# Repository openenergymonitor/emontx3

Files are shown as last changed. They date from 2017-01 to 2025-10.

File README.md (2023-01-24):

# emonTx V3.4.x



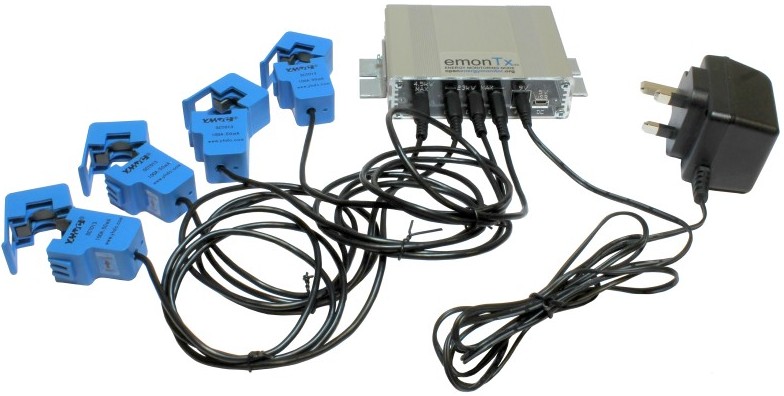
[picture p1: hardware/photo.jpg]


## Documentation

- [Overview](https://docs.openenergymonitor.org/emontx3/overview.html)
- [Install Guide](https://docs.openenergymonitor.org/emontx3/install.html)
- [Adding to an existing install](https://docs.openenergymonitor.org/emontx3/add.html)
- [3 phase](https://docs.openenergymonitor.org/emontx3/3phase.html)
- [Add ESP8266](https://docs.openenergymonitor.org/emontx3/esp8266.html)
- [Direct Serial](https://docs.openenergymonitor.org/emontx3/direct.html)
- [Configuration](https://docs.openenergymonitor.org/emontx3/configuration.html)
- [Firmware](https://docs.openenergymonitor.org/emontx3/firmware.html)
- [Technical](https://docs.openenergymonitor.org/emontx3/technical.html)

This documentation can also be viewed on github directly [here](docs).

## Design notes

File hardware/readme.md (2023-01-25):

# emonTx V3.4

The emonTx V3.4 is the latest generation of the open-source hardware Arduino compatiable emonTx low power wireless energy monitoring node. The unit has been totally re-designed using surface mount (SMT) electronics to enable automated pre-assembled manufacture here in the UK.

## Hardware change log

### V3.4.5 

*Not yet released as of April 2021*

PCB changes
- Remove MLF ATmega footprint to avoid solder bridges during reflow
- Fix rear silkscreen version number
- Improve via spacing 

BOM changes
- Update R13 & R14 from 1% to 0.5% tolerance
- Switch to LDK320ADU33R LDO for higher 18V input voltage
- Remove battery holder from BOM 
- Revert to 4x 3.5mm black CT sockets due to procurement issues for differnet colour sockets
- Moved TSV diodes from ESD5Z3.3T1G to UCLAMP3301H to procurement issues 

### V3.4.4 

Minor PCB changes:

- fix overlayed double via
- Add protection ring for top-right fiducial

### V3.4.3

**Shipping March/April 2018 onwards**

- Identifiable with blue CT4 jackplug socket (mostly)
- Add extra UART header with Rx/Tx swap-over for easy ESP connection
- Increase  reservoir capacitor of AC-DC circuit C18 16uF to 100uF to allow for greater peak power consumption of RFM69CW (compared to RFM12B)
- Change Burden resistors R7, R8, R9 (22R) from 1% to 0.5% tolerance  to increase accuracy. Wanted to change to 0.1% but unable to source
- Changed Burden resistor R18 (120R) from 1 % to 0.1%
- Change all 470K resistors from 1% to 0.1% (R1, R2, R4, R6, R11, R12, R15, R17, R21, R23, R27, R30)
- Changed CT4 jack plug socket to blue colour to indicate low power high accuracy channel

Live BOM: https://octopart.com/bom-tool/xiwE7CiN

#### V3.4.2

**Aug 2016**

- Same BOM as V3.4.1
- Increase mini USB location pin holes from 0.8mm to 0.9mm

#### 3.4.1 Mar 2015

- lots of via GND links around GND plane - make sure ant has best GND plane possible
- make sure antenna has got GND plane under ant PCB trace
- pull top gnd plane in around RFM69CW module and rear GND plan to cover whole undersided
- Get rid of unused L1
- Move D2 location to not be under battery holder
- Correct terminal block silkscreen
- Disconnect RJ45 pin 1 and 3 from GND, stop power rail short if ethernet cable is connected by mistake

#### V3.4

- More FTDI connection bit to the left
- Increase pads for DIP switch
- Add TVS diodes, CT input protection

### V3.3

- ATmega328 on-board
- Edge SMA Antenna
- Non plate through mounting pads to eliminate interference through enclosure
- RJ45 DS18B20 temperature sensor
- 3 x AA Battery monitor on ADC7
- DIP Switch on Dig8 and Dig9 for Node ID selection
- RFM69CW compatible with SEL line pull-up resistor
- Pulse counting / terminal block IRQ changed from D2 IRQ0 to D3 IRQ1 since RFM12B now uses IRQ0
- Changed MCP1700 3.3V regulator to MCP1702 3.3V regulator to allow for powering from higher voltages (12V max) over RJ45

***

## Links

- [Purchase](http://shop.openenergymonitor.com/emontx-v3/)

- [User Guide](https://guide.openenergymonitor.org/setup/emontx)

***



### Schematic

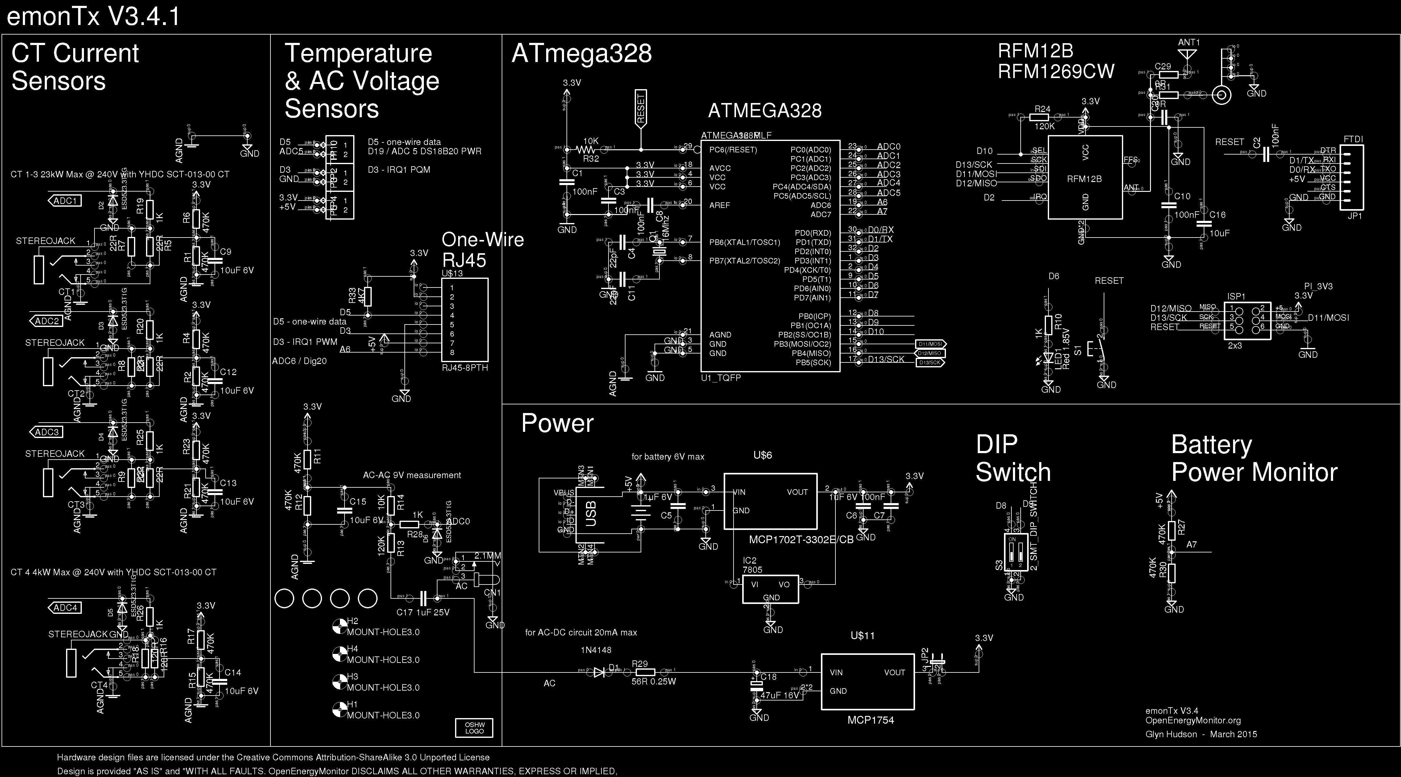
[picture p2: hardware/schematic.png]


### Board

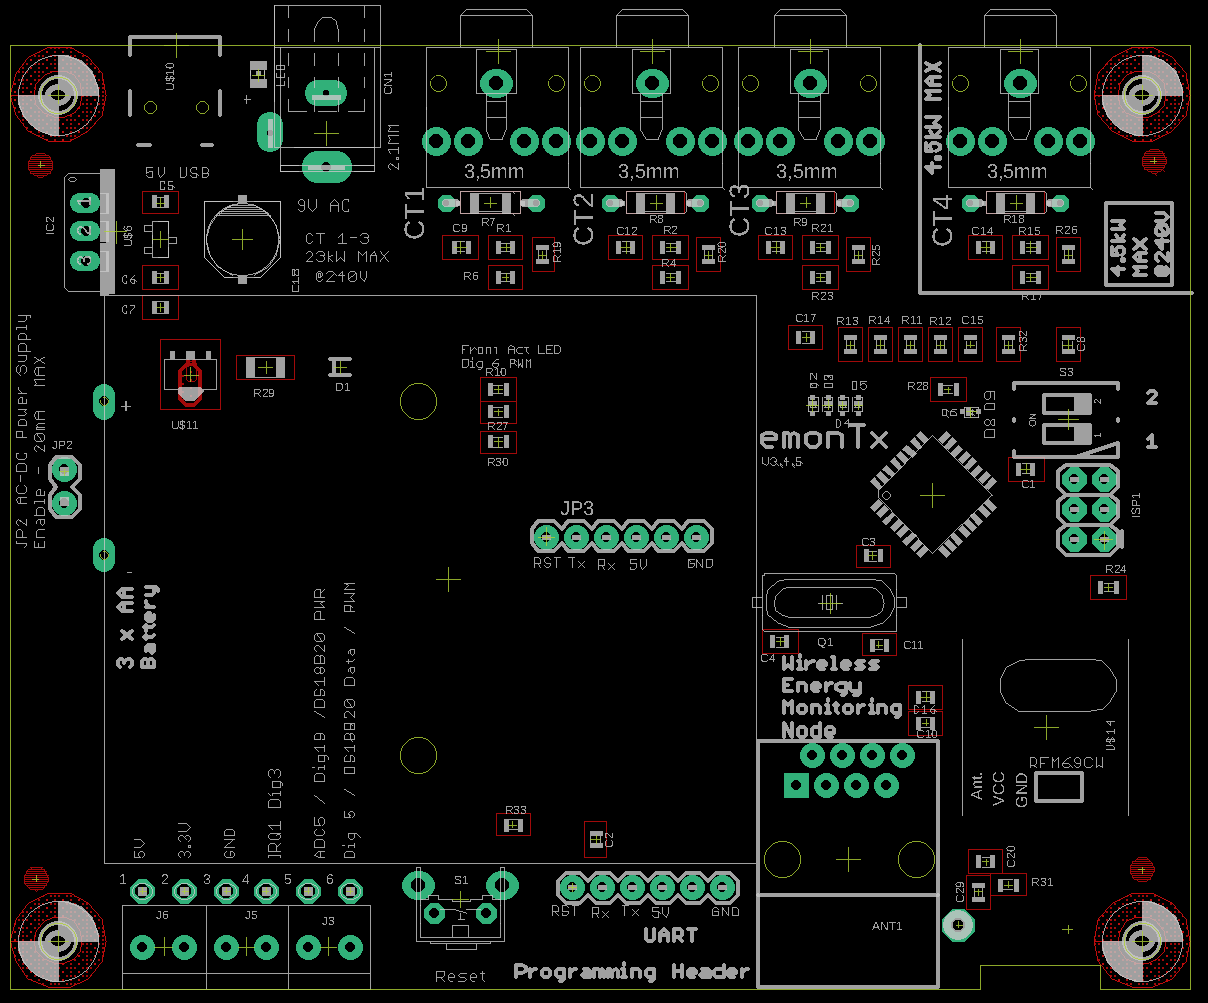
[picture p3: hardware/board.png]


## Portmap

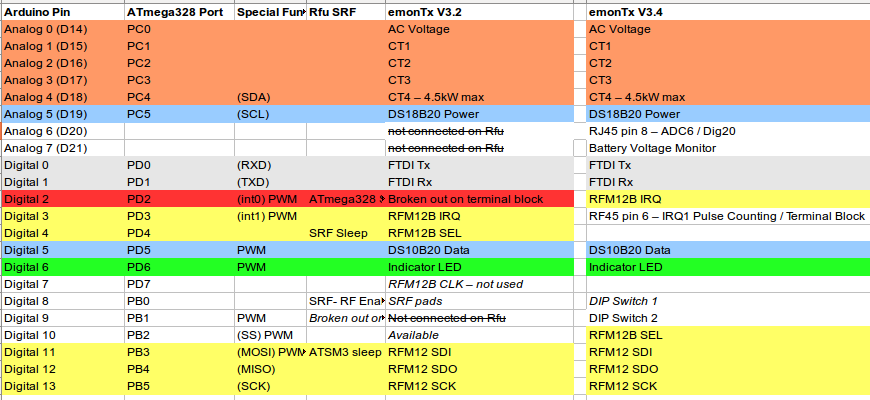
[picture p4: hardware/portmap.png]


### Open Hardware

Hardware designs (schematics and CAD) files are licensed under the [Creative Commons Attribution-ShareAlike 3.0 Unported License](http://creativecommons.org/licenses/by-sa/3.0/) and follow the terms of the [OSHW (Open-source hardware) Statement of Principles 1.0.](http://freedomdefined.org/OSHW)

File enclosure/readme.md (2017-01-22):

Lincoln Binns E-Case B

https://www.lincolnbinns.com/en/aluminium-electronic-enclosure-e-case-b-data/

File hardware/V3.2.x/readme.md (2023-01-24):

# emonTx 3.2.x

The emonTx v3.2 used the RFu328 module to provide both the ATmega328 and the RFM12B radio module. This was available pre-installed or the emonTx base board. 

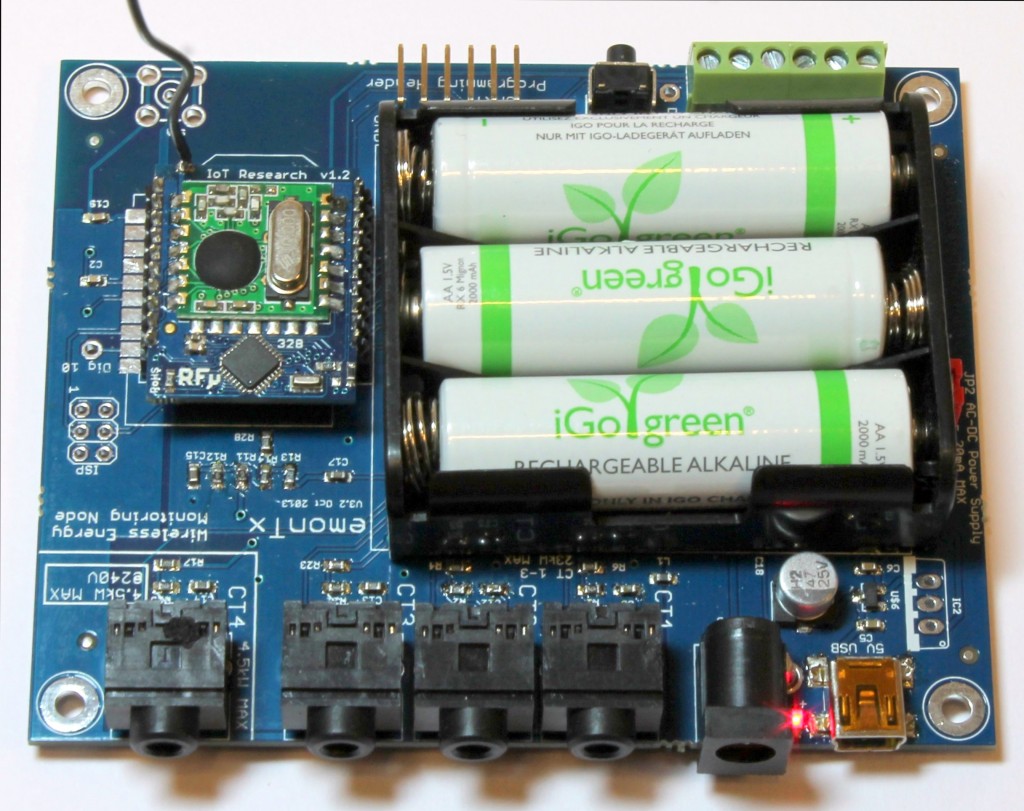
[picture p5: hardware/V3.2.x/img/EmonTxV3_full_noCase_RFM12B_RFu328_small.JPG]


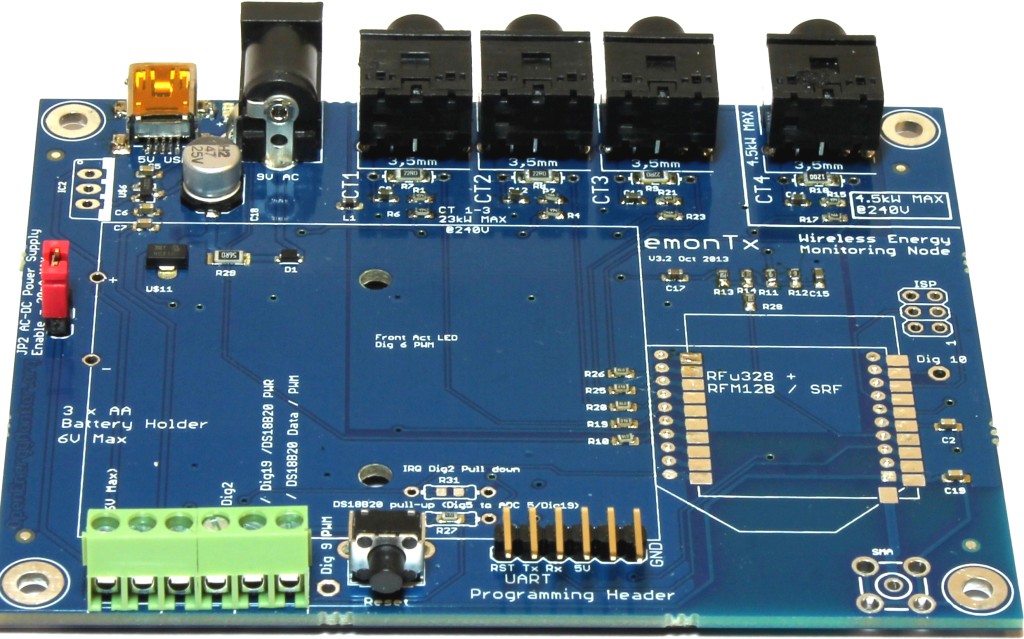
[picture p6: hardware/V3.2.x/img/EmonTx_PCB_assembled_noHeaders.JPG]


## Port Map

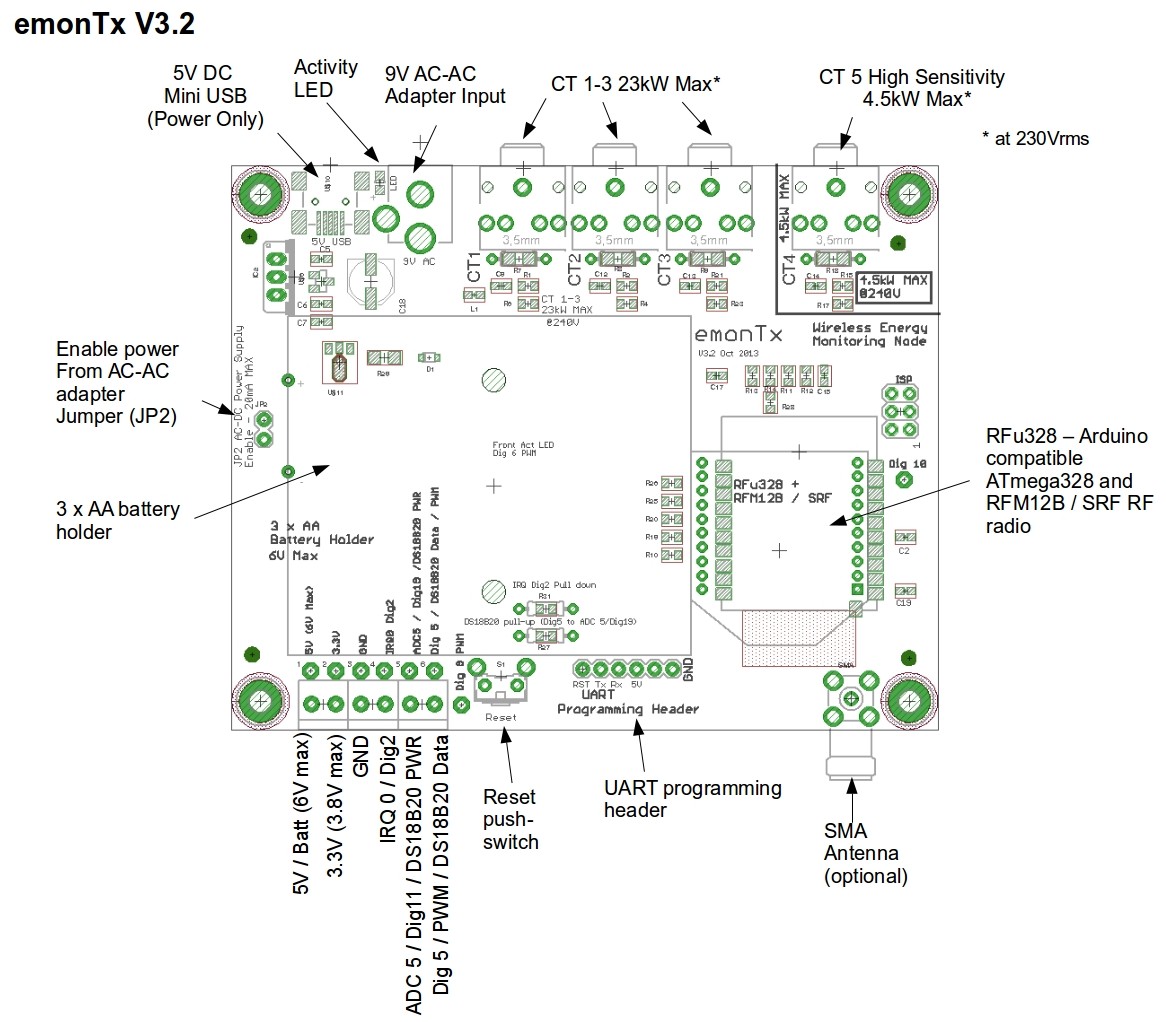
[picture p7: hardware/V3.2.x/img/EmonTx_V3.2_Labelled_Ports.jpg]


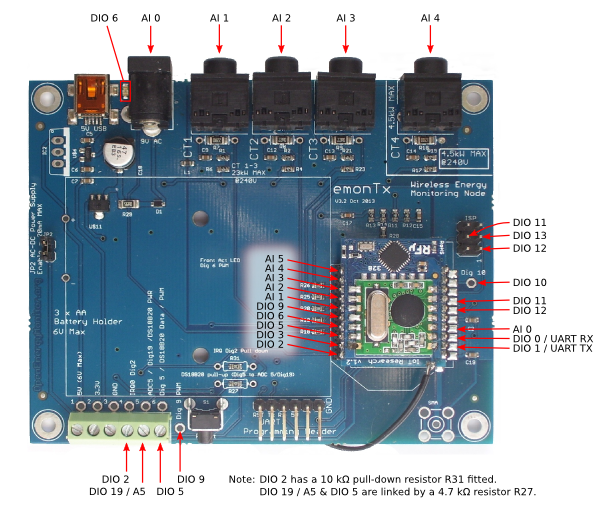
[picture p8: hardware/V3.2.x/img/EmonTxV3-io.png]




*Note: pulse counting on IRQ0, Dig2 rather than IRQ1 Dig3 on the emonTx3.4 

## Firmware

See: [https://github.com/openenergymonitor/emonTxFirmware/tree/master/emonTxV3/RFM/emonTxV3.2 ](https://github.com/openenergymonitor/emonTxFirmware/tree/master/emonTxV3/RFM/emonTxV3.2 )

## RF Connectivity

### RFM12B

To use the RFM12B on the RFu328, a modified version of the JeeLib RF12 library has been created. This is called the [RFu_JeeLib](https://github.com/openenergymonitor/RFu_jeelib) see the GitHub readme for details regarding the modifications. 

The emonTx V3.2 was initially shipped with a wire whip antenna. An SMA antenna could alternatively be added by soldering in the connector on the board. A small wire link was required between the RFu328 and the base board if an RFu328 with headers was used. See [EmonTx_V3_SMA.jpg](img/EmonTx_V3_SMA.jpg) & [EmonTx_V3_SMA_RFu_headers.jpg](img/EmonTx_V3_SMA_RFu_headers.jpg).

Power consumption:

- MCU sleep + RFM12B sleep: 0.034 mA
- MCU running: 7.3mA 
- MCU + LED: 9-10mA
- RFM12B TX ~3ms: 23-28mA

### RF testing

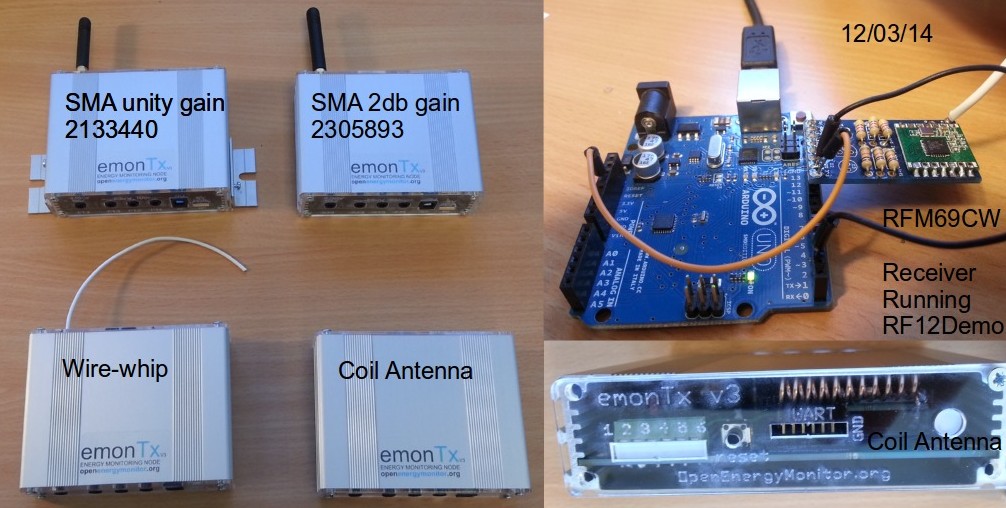
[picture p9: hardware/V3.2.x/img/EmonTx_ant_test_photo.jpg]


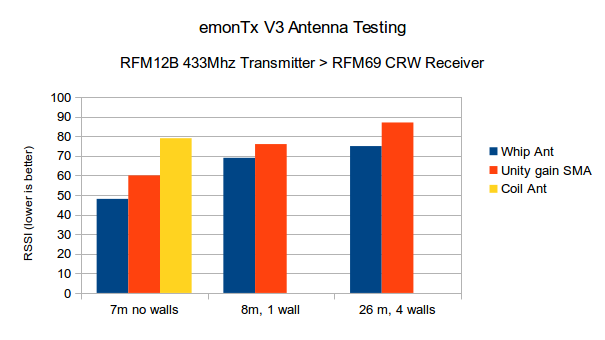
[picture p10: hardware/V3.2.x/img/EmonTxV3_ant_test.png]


All antennas and RFM12B modules were 433MHz running standard emonTx discrete sampling firmware, transmitting once very 10s.

An RFM69CW receiver provided RSSI readings to enable antenna comparison. The RSSI readings were all lower than normal since the RFM69CW used is an 868MHz module, with an 868MHz antenna, forced via software, to a 433MHz receive frequency.

The emonTxs with the SMA antenna had the RFu328 soldered directly (SMT) to the PCB, the coil and whip antenna had the RFu328 mounted using headers 

## BOM

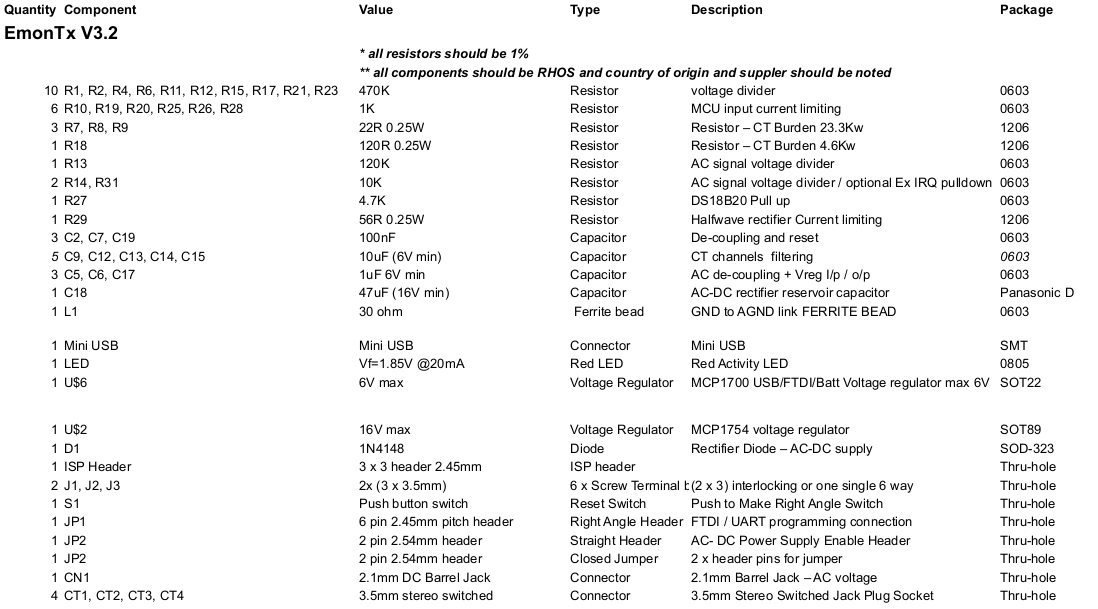
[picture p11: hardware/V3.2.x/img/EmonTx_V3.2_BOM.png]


## Dimensions

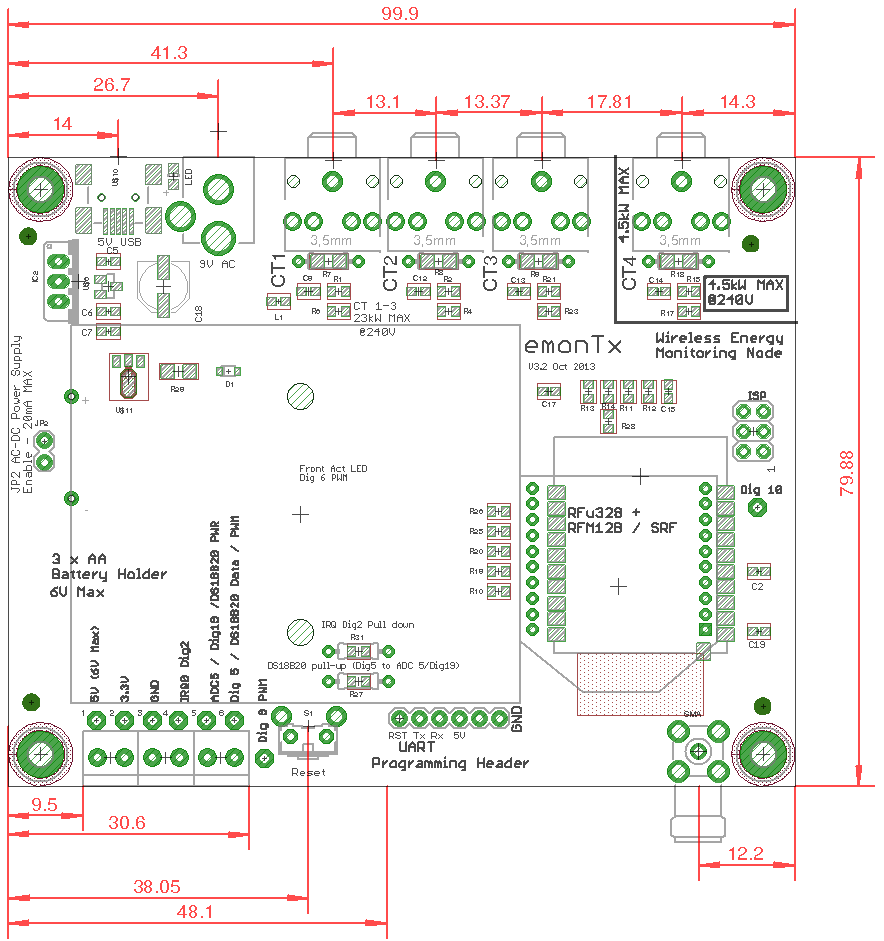
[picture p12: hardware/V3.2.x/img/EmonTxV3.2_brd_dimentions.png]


Enclosure: extruded aluminium case with acrylic fascia.

**DIN Rail Mount:** Thanks to [@Aquefot](http://twitter.ccom/Aquefot) for contributing a [DIN mount rail fitting CAD design](https://twitter.com/aquefot/status/413708371809026048/photo/1) ready to be 3D printed for the emonTx: [Thingiverse Download](http://www.thingiverse.com/thing:208177) 

## Licence

Creative Commons Attribution-ShareAlike 3.0 Unported License

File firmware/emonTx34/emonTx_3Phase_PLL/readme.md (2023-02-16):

# emonTx_3Phase_PLL

This firmware is a development of the 3-phase ‘discrete sample’ sketch and MartinR’s PLL
energy diverter.

It is intended for use on a **3-phase, 4-wire system**. It utilises advanced features of the Atmel328P microprocessor to provide continuous monitoring of voltage of one phase and the currents in all three phases, thereby allowing a good estimate of real power to be calculated. The physical quantities are measured continuously, the average values are calculated and transmitted at user-defined intervals.

Pulse counting and temperature monitoring using a single DS18B20 sensor is supported.

## Key Feautures

- Continuous monitoring of one voltage channel and up 4 current channels.
- Gives an accurate measure of rapidly varying loads.
- 1800 sample sets per second – using 4 channels of an emonTx V3.4 @ 50 Hz
- Calculates rms voltage, rms current, real & apparent power & power factor.
- Pulse input for supply meter monitoring.
- Integrated temperature measurement (one DS18B20 sensor).
- User-defined reporting interval.
- Suitable for operation on a three-phase, 4-wire supply at 50 or 60 Hz.
- Can be calibrated for any voltage and current (default calibration is for emonTx with 100 A CTs & UK a.c. adapter).
- **New:** Radio format support with #define selection for: JeeLib Classic, JeeLib Native & LowPowerLabs

## Limitations

Because the voltage of only one phase can be measured, the sketch must assume that the voltages of the other two phases are the same. This will, in most cases, not be true, therefore the powers calculated and recorded will be inaccurate. However, this error should normally be limited to a few percent. Voltage imbalance might be the result of unbalanced loads within your installation, or it might result from the actions of other consumers on the same supply.

If you find that one or other phase voltage is consistently wrong, you might want to consider a small adjustment to the current calibration of the affected phase. Because of the additional power required for continuous operation, a 5 V USB power supply is likely to be required, even if only the on-board RFM69CW radio is used. The 5 V power will always be required when the ESP8266 WiFi module is added.

The sketch is not compatible with the RFM12B radio module, nor the Arduino Due.

## Resources

- [Introduction to three-phase](https://learn.openenergymonitor.org/electricity-monitoring/ac-power-theory/3-phase-power)
- [Full 3-phase Firmware User Guide](emonTx_3Phase_PLL_User_Doc.pdf)

## Pre-compiled HEX files:

JeeLib Classic radio format:<br>
https://github.com/openenergymonitor/emontx3/releases/download/tx3-16-02-23/emonTx_3Phase_PLL_jeelib_classic_2_1.hex

**New:** LowPowerLabs radio format:<br>
https://github.com/openenergymonitor/emontx3/releases/download/tx3-16-02-23/emonTx_3Phase_PLL_LPL_2_1.hex

## Compile and upload using PlatformIO

PlatformIO works great from the command line. See the excellent [PlatformIO Quick Start Guide](https://docs.platformio.org/en/latest/core/installation/index.html#super-quick-mac-linux) for installation instructions.

    git clone https://github.com/openenergymonitor/emontx3
    cd emontx3/firmware/emonTx34/emonTx_3Phase_PLL
    pio run -t upload

View serial port with PlatformIO CLI

    pio device monitor

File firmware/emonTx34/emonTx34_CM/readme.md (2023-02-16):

# emonTx3_CM

This firmware implements higher accuracy continuous monitoring. Continuous monitoring means that the power readings are representative of the full 10s period that they represent rather than a short snapshot (as originally implemented in the discrete sampling firmware). 

Continuous monitoring firmware was pre-loaded on emonTx3 units sold from the OpenEnergyMonitor shop as standard since 2019, unless battery operation was selected.

## Features

- Continuous Monitoring on all four EmonTxV3 CT channels and ACAC Voltage input channel.
- Real power (Watts) and cumulative energy (Watt-hours) measurement per CT channel.
- RMS Voltage measurement.
- Support for 3x DS18B20 temperature sensors.
- Support for pulse counting.
- Resulting readings transmitted via RFM radio or printed to serial.
- Serial configuration of RFM radio and calibration values.
- **New:** Radio format support with #define selection for: JeeLib Classic, JeeLib Native & **LowPowerLabs**

## Serial configuration

See [https://docs.openenergymonitor.org/emontx3/configuration.html#serial-configuration](https://docs.openenergymonitor.org/emontx3/configuration.html#serial-configuration)

## Pre-compiled HEX files:

JeeLib Classic radio format:<br>
https://github.com/openenergymonitor/emontx3/releases/download/tx3-16-02-23/emonTx34_CM_jeelib_classic_2_4.hex

**New:** LowPowerLabs radio format:<br>
https://github.com/openenergymonitor/emontx3/releases/download/tx3-16-02-23/emonTx34_CM_LPL_2_4.hex

## Compile and upload using PlatformIO

PlatformIO works great from the command line. See the excellent [PlatformIO Quick Start Guide](https://docs.platformio.org/en/latest/core/installation/index.html#super-quick-mac-linux) for installation instructions.

    git clone https://github.com/openenergymonitor/emontx3
    cd emontx3/firmware/emonTx34/emonTx34_CM
    pio run -t upload

View serial port with PlatformIO CLI

    pio device monitor

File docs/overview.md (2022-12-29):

# Overview

The emonTx3 is a low power RF remote sensor node. Data is transmitted to an emonPi or an emonBase via a low power 433 MHz radio.

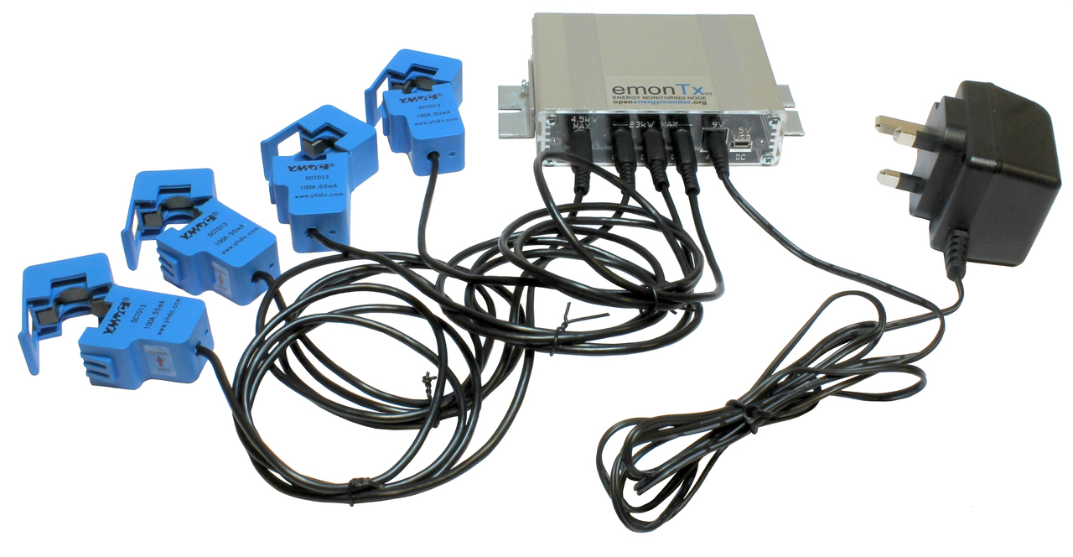
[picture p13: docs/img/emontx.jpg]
emonTx


**Features:**

- 4x CT Sensor inputs for single-phase AC electricity monitoring designed for use with the [100A SCT-013-000 CT sensor](https://shop.openenergymonitor.com/100a-max-clip-on-current-sensor-ct/)
- CT 1-3 are standard 100A / 24KW max CT inputs (@240V)
- CT 4 is a special high sensitivity input for 19A / 4.6KW (@240V)
- 1x AC voltage measurement using plug-in AC-AC adapter for real power calculation alongside current measurement from CT sensors. Designed for use with a [9V AC output voltage adapter](https://shop.openenergymonitor.com/ac-ac-power-supply-adapter-ac-voltage-sensor-uk-plug/)
- Support for multiple wired one-wire DS18B20 temperature sensors via RJ45 socket or terminal block.
- Support for pulse counting either wired or via Optical Pulse Sensor
- Can be powered by a single AC-AC adaptor (DC PSU not required)
- Battery power option via 3 x AA batteries
- RF Range is approximately similar to home WiFi (real world range depends on many factors e.g. thick stone walls)
- Up to 2x emonTx can be connected to a single emonPi or emonBase (up to 30x is possible with manual RF node ID setting*)
- Wall-mount option
- New 2019: The emonTx firmware now supports higher accuracy continuous monitoring as standard, power from an ACAC adapter or USB power is assumed.
- Alternative firmware options include: Discrete Sampling firmware - useful when only battery power is available; and 3-phase firmware.

**WiFi option:** It is possible to use an emonTx with a ESP8266 WiFi adapter to provide WiFi connectivity. This can be useful in applications where the 433 MHz radio range is not sufficient but there is good WiFi signal. The emonTx can post data to a local emonBase/emonPi over WiFi or work in 'standalone mode' to post directly to a remote emoncms server such as emoncms.org. See [Using emonTx with the ESP8266 WiFi module](esp8266.md)

**Battery vs AC adapter:**
An emonTx can be powered by 3 x AA batteries; however, if possible, it is recommended to power the unit with an AC-AC adapter to provide an AC voltage reference for more accurate real power calculation and continuous sampling support.

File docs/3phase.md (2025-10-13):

# emonTx 3phase

An emonTx3 can be used for 3-phase monitoring using the [3-phase firmware](https://github.com/openenergymonitor/emontx3/tree/master/firmware/emonTx34/emonTx_3Phase_PLL).

Designed for use on a 3-phase, 4-wire system. The firmware provides continuous monitoring of voltage of one phase and the currents in all three phases, thereby allowing a good estimate of real power to be calculated. The physical quantities are measured continuously, the average values are calculated and transmitted at user-defined intervals.

Pulse counting and temperature monitoring using a single DS18B20 sensor is supported.

Data is transmitted to the emonPi or emonBase via the low power 433MHz radio as standard, or alternatively using the [ESP8266 WiFi adapter](esp8266.md).

## 1. Installation 

**Before starting installation it's important to identify the phases.**

- Ideally plug the AC voltage adapter into L1 this will allow straightforward connection of CTs as follows CT1=L1, CT2=L2 and CT3=L3. 

- If it's not possible to plug the AC voltage adapter into L1 e.g all the accessible plug sockets are on a different phase then the connection of CTs must be adjusted e.g If AC voltage adapter is plugged into L2 then the CTs must be connected as follows CT1=L2, CT2=L3 and CT3=L1

For a detailed and technical explanation of the 3-phase firmware, see the [emonTx three-phase technical user guide](https://github.com/openenergymonitor/emontx3/blob/master/firmware/emonTx34/emonTx_3Phase_PLL/emonTx_3Phase_PLL_User_Doc.pdf) and the [3-phase emonTx firmware](https://github.com/openenergymonitor/emontx3/tree/master/firmware/emonTx34/emonTx_3Phase_PLL). 

```{note}
The emonTx3 3-phase firmware default nodeid is node 11. If installing multiple units, moving the bottom DIP switch (D8) to the left will change the node ID to 12. This can alternatively be done via serial configuration, see [Adding to an existing install](add.md)
```

## 2. Emoncms Input processing

Setup the input processing as follows, 

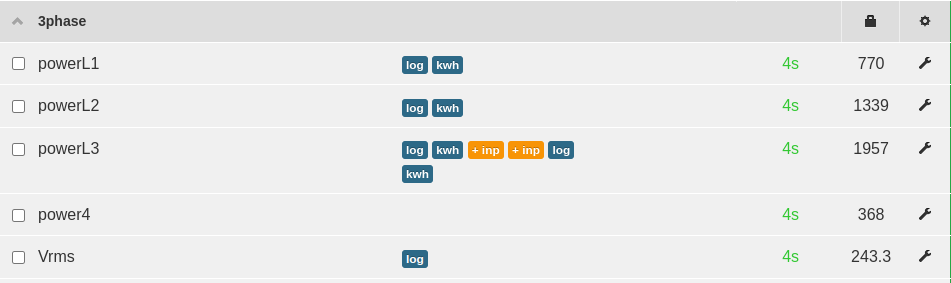
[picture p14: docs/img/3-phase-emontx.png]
emontx three-phase input processing


Use the `+ Input` input process to add the phase power inputs together to create a feed for the total power e.g

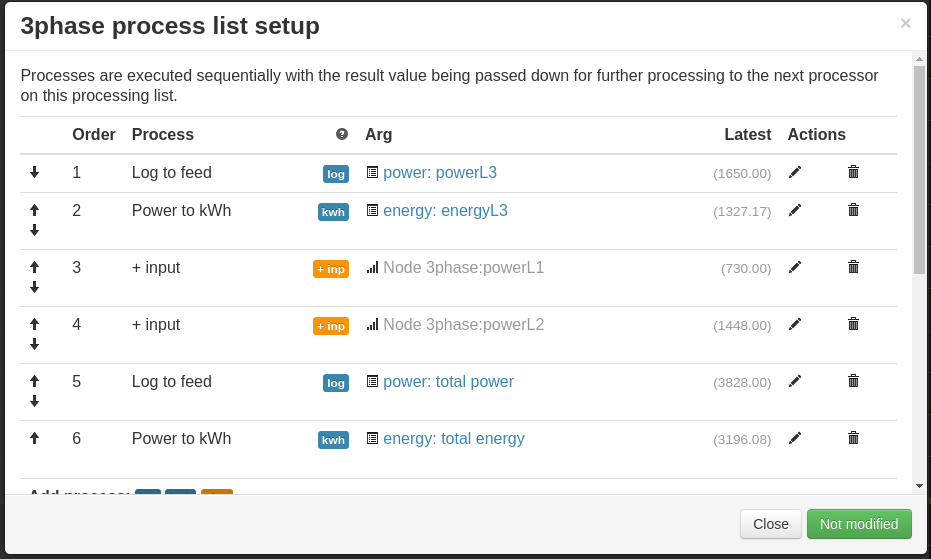
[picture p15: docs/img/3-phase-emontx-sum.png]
emontx three-phase sum


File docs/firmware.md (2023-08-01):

# Firmware

The emonTx3 firmware is based on Arduino. Alternative or customised firmware sketches can be uploaded using Arduino IDE or PlatformIO and a USB to UART cable.

## Available Firmware

### [emonTx34_CM](https://github.com/openenergymonitor/emontx3/tree/master/firmware/emonTx34/emonTx34_CM): continuous sampling firmware

This firmware provides higher accuracy continuous monitoring. Continuous monitoring means that the power readings are representative of the full 10s period that they represent rather than a short snapshot. This firmware was pre-loaded as standard since 2019, unless battery operation was selected.

**New:** Support for three different radio formats is available: JeeLib Classic, JeeLib Native and **LowPowerLabs**.

### [emonTx34_DS_jeelib_classic](https://github.com/openenergymonitor/emontx3/tree/master/firmware/emonTx34/emonTx34_DS_jeelib_classic): discrete sampling firmware

The original emonTx firmware, this performs power measurement in short discrete snapshots ~300ms long per CT channel at 50Hz per 10s period. This makes it possible for the emonTx to go to sleep inbetween readings enabling battery powered operation but is less accurate.

**Indicator LED:** Illuminates solid for a 10 seconds on first power up, then flashes multiple times to indicate an AC-AC waveform has been detected (if powering via AC-AC adapter). Flashes once every 10s to indicate sampling and RF transmission interval.

### [emonTx_3Phase_PLL](https://github.com/openenergymonitor/emontx3/tree/master/firmware/emonTx34/emonTx_3Phase_PLL): 3-phase continuous sampling firmware

This firmware is intended for use on a 3-phase, 4-wire system and implements continuous monitoring as above. Because the voltage of only one phase can be measured, the firmware must assume that the voltages of the other two phases are the same. This will, in most cases, not be true, therefore the powers calculated and recorded will be inaccurate. However, this error should normally be limited to a few percent.

- [Learn: Introduction to three-phase](https://learn.openenergymonitor.org/electricity-monitoring/ac-power-theory/3-phase-power)
- [Full 3-phase Firmware User Guide](https://github.com/openenergymonitor/emontx3/blob/master/firmware/emonTx34/emonTx_3Phase_PLL/emonTx_3Phase_PLL_User_Doc.pdf)

**New:** Support for three different radio formats is available: JeeLib Classic, JeeLib Native and **LowPowerLabs**.

## Updating firmware using an emonPi/emonBase

The easiest way of updating the emonTx3 firmware is to connect it to an emonPi or emonBase with a USB to UART cable and then use the firmware upload tool available at `Setup > Admin > Update > Firmware`.

The example images below show the earlier [Wicked Device / OpenEnergyMonitor Programmer](../electricity-monitoring/programmers/wicked-device.md). The programmer is the small board that plugs in to the emonTx3 on the 6-pin UART header. The [newer programmer](../electricity-monitoring/programmers/ftdi-programmer.md) currently available in the shop needs to be orientated the other way around. **Make sure that GND on the programmer matches up with GND on the emonTx3 board.**

Refresh the update page after connecting the USB cable. You should now see port ttyUSB0 appear in the ‘Select port` list.

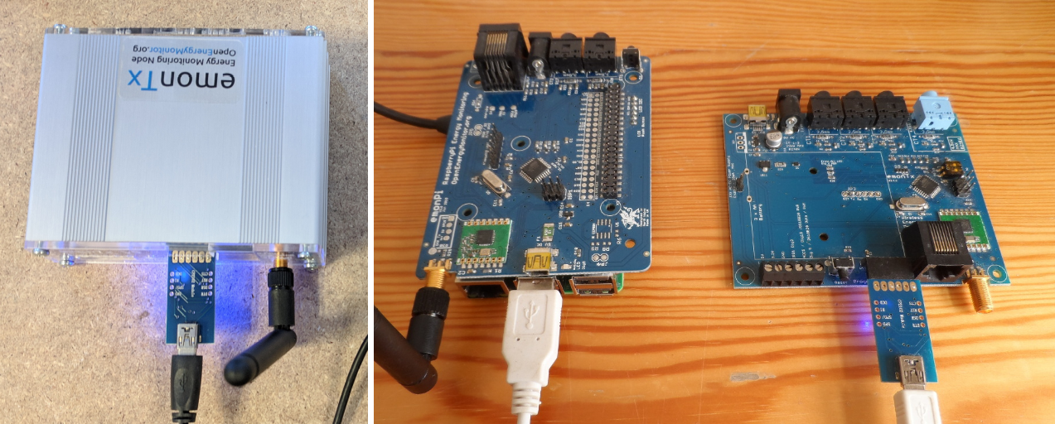
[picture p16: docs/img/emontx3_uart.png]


Select port: `ttyUSB0`, Hardware: `emonTx`, Radio format: `RFM69 JeeLib Classic`, Firmware: As required, see above.



Click `Update Firmware` to upload the firmware.

## How to compile and upload firmware

### PlatformIO Command Line

PlatformIO works great from the command line. See the excellent [PlatformIO Quick Start Guide](https://docs.platformio.org/en/latest/core/installation/index.html#super-quick-mac-linux) for installation instructions.

**Compile and upload emonTx34_CM Continuous Sampling firmware**

    git clone https://github.com/openenergymonitor/emontx3
    cd emontx3/firmware/emonTx34/emonTx34_CM
    pio run -t upload
    
**Compile and upload emonTx34_DS_jeelib_classic Discrete Sampling firmware**

    git clone https://github.com/openenergymonitor/emontx3
    cd emontx3/firmware/emonTx34/emonTx34_DS_jeelib_classic
    pio run -t upload
    
**Compile and upload emonTx_3Phase_PLL firmware**

    git clone https://github.com/openenergymonitor/emontx3
    cd emontx3/firmware/emonTx34/emonTx_3Phase_PLL
    pio run -t upload

**View serial port with PlatformIO CLI**

    pio device monitor

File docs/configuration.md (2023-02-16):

# Configuration

## DIP Switch

The on board DIP switch can be used as a convenient way to change both the node ID and the voltage calibration of the emonTx3.

Multiple emonTx unit's can operate on a single network posting to a single emonBase web-connected base station, each emonTx on the same network group must have an unique node ID. If more than two emonTx's are required on the same network then further nodeID values can be set via RF node ID serial config.

The following image shows the DIP switch configuration looking at the emonTx with the CT sensor inputs at the top of the board. 

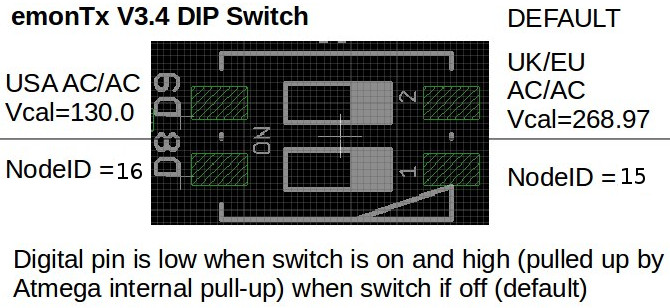
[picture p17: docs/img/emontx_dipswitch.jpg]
```{image} img/emontx_dipswitch.jpg
:width: 400px
:align: right
```

<br>

Move the top switch D9 to the left to select USA ACAC Voltage calibration. 

Move the bottom switch D8 to the left to select RF node ID 16 rather than 15.

<br>
<br>

## Serial Configuration

It's possible to set the emonTx3 radio settings, sensor calibration and other properties over serial using the arduino serial monitor or other similar tool. 

The following details the available commands and their function:

- **l** list the settings
- **r** restore sketch defaults
- **s** save settings to EEPROM
- **v** show firmware version
- **z** zero energy values
- **x** exit, lock and continue
- **?** show this text again
- **w\<x\>** turn RFM Wireless data off: x = 0 or on: x = 1
- **b\<n\>** set r.f. band n = a single numeral: 4 = 433MHz, 8 = 868MHz, 9 = 915MHz (may require hardware change)
- **p\<nn\>** set the r.f. power. nn - an integer 0 - 31 representing -18 dBm to +13 dBm. Default: 25 (+7 dBm)
- **g\<nnn\>** set Network Group nnn - an integer (OEM default = 210)
- **n\<nn\>** set node ID n= an integer (standard node ids are 1..60)
- **d\<xx.x\>** a floating point number for the datalogging period
- **c\<n\>** n = 0 for OFF, n = 1 for ON, enable current & power factor values to serial output for calibration.
- **f\<xx\>** the line frequency in Hz: normally either 50 or 60
- **k\<x\> \<yy.y\> \<zz.z\>**
  - Calibrate an analogue input channel:
  - x = a single numeral: 0 = voltage calibration, 1 = ct1 calibration, 2 = ct2 calibration, etc
  - yy.y = a floating point number for the voltage/current calibration constant
  - zz.z = a floating point number for the phase calibration for this c.t. (z is not needed, or ignored if supplied, when x = 0)
  - e.g. k0 256.8
  - k1 90.9 2.00
- **a\<xx.x\>** a floating point number for the assumed voltage if no a.c. is detected
- **m\<x\> \<yy\>** meter pulse counting: 
  - x = 0 for OFF, x = 1 for ON
  - yy = an integer for the pulse minimum period in ms. (y is not needed, or ignored when x = 0)
- **t\<x\>** turn temperature measurement on or off: x = 0 for OFF, x = 1 for ON

```{note}
If a custom node ID is set, a corresponding node decoder needs to be in place in emonhub.conf to decode the EmonTx radio packet data. See [emonhub.conf configuration guide](https://github.com/openenergymonitor/emonhub/blob/emon-pi/configuration.md).
```

Note: When using the Arduino IDE to set properties of the firmware via serial, ensure the serial monitor is set to `NL` (newline) and the baud rate is set to `115200`. The serial monitor may need to be restarted after changing the line ending selection.

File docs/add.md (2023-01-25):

# Adding to an existing install

Additional [EmonTx energy monitoring nodes](../emontx3/add.md) can be added to both an emonPi or a emonBase system to:

- Expand the number of AC circuits that can be measured.<br>(Each EmonTx adds +4x CT sensor inputs)
- Monitor circuits at different locations in a building
- Monitor circuits where an AC socket is not available (using battery power)
- Monitor 3-phase power (with 3-phase emonTx firmware, see [EmonTx Technical](../emontx3/add.md))

Data is transmitted to the emonPi or emonBase via low power 433MHz radio as standard, or alternatively using the [ESP8266 WiFi adapter](esp8266.md) via WiFi for applications where the 433 MHz radio range is insufficient. 

emontx

## 1. Adding one emonTx to an emonPi system

If you have already setup an emonPi following the [emonPi installation guide](../emonpi/install.md). The steps for installing an emonTx are covered in the [emonTx and emonBase installation guide](../emontx3/install.md). The emonPi in this instance works in much the same way as the emonBase.

## 2. Adding more than one emonTx to an emonPi or emonBase system

In addition to standard emonTx installation as covered in the [emonTx and emonBase installation guide](../emontx3/install.md): when using 2 or more emonTx units with the same base-station **the node ID on each unit needs to be unique**. See [Configuration](configuration.md) for details on how to change the nodeid.

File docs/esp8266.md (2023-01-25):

# Using the emonTx v3 with the ESP8266 Huzzah WIFI module

This is a guide on how to use the Adafruit ESP8266 Huzzah WiFi module with an [emonTx v3](../emontx3/technical.md) to make a simple WiFi enabled energy monitor that can post directly to [emoncms.org](https://emoncms.org) or any other Emoncms installation local or remote.

For applications that only require basic posting of data from one emonTx to a remote server such as Emoncms.org an emonTx with this WiFi module provides a lower cost route than an emonBase or emonPi base-station installation.

An emonBase or emonPi is recommended for more complex applications where local storage is desirable and/or an installation with multiple sensors and control nodes. An emonPi/emonBase system allows for much greater expandability and customisation.

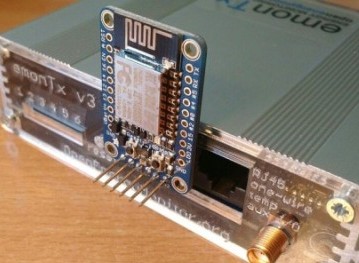
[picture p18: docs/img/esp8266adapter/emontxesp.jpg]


## To set up an emonTx v3 + ESP8266 Wifi energy monitor you will need:

- **[An emonTx + WiFi adapter bundle is now available to buy in the shop.](https://shop.openenergymonitor.com/emontx-wifi-adapter-1/)** 

Alternatively, you will need:

- **[emonTx V3](../emontx3/overview.md):** + CT, AC-AC adapter, temperature and pulse sensors as required by your application.<br>
*To use ESP8266 with emonTx three-phase firmware, the EmonESP baud rate needs to be set to 9600*

- **5V USB DC Power supply for the emonTx:** The AC-AC Voltage adapter that can power the emonTx in normal operation does not deliver enough power to run the ESP8266 Huzzah WiFi module and so an additional 5V USB Power supply is required. Battery operation is not possible when using ESP8266.

- **ESP8266 Huzzah WiFi module with a 6 way stackable header running [EmonESP](https://github.com/openenergymonitor/emonesp):** For a DIY approach see the original forum post [here](https://community.openenergymonitor.org/t/using-the-emontx-v3-with-the-esp8266-huzzah-wifi-module/795).

## ESP8266 Huzzah WIFI module with a 6 way stackable header:

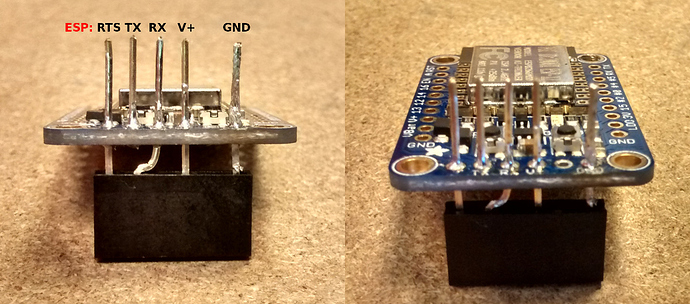
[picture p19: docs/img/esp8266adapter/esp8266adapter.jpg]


Alternatively, 6 way ribbon cable with the RX/TX line swapped could be used, and may be a bit easier to put together.

N.B. You should connect ONLY the RX pins, and leave the Tx pins not connected, as the pictures above show.

## Setup procedure

1) Plug the ESP8266 Huzzah WIFI module into the emonTx as shown in the first picture above.

2) Connect any CT sensors, AC-AC adapter for voltage sensing and other sensors as required and plug in USB Power to the USB mini socket on the emonTx.

3) Remove (open) jumper JP2 on the emonTx PCB, then connect both the 5V DC USB power supply and the AC-AC adapter simultaneously, to ensure that the emonTx starts up detecting the AC-AC adapter and that enough power is delivered to the ESP8266 Huzzah WiFi module for start-up.

**Note:** It's important to remove/open jumper JP2 separates the AC and DC power supplies to ensure the emonTx is powered via DC and the AC is only used to provide an AC voltage reference.

4) The ESP8266 WiFi module will now create a WiFi access point for configuration. Using your laptop or phone, scan for WIFI networks, you should see a network SSID that looks something like:

    emonESP_1679732

5) After successful connection, navigate to IP address 192.168.4.1 to access the configuration page:

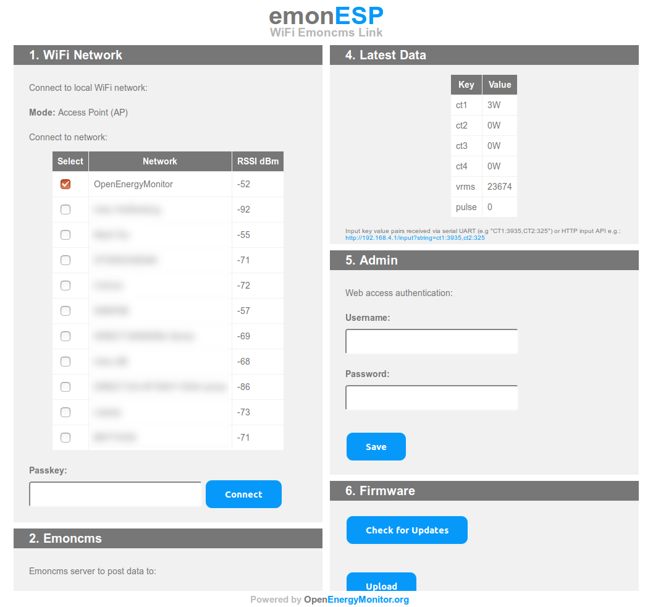
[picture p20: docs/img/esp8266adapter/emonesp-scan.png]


6) Select the WiFi network that you wish to connect to, enter passkey and click 'Connect'. Wait about 30s for the module to connect. Once connected the module will show its IP-address in the interface (underlined in red in the screenshot).

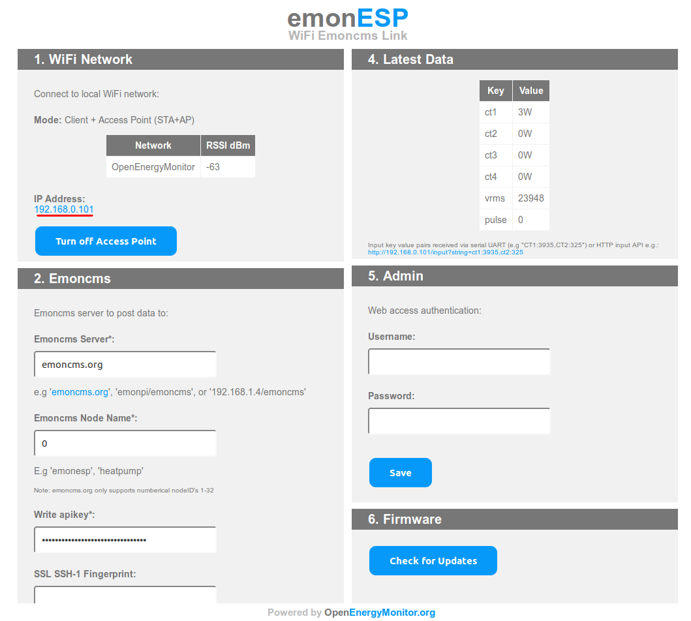
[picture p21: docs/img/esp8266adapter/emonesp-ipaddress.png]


7) Click on the IP address to change your browser to the new location. Re-connect to your home WiFi network. Refresh the page to load the emonESP configuration page across your home LAN WiFi rather than the access point.

8) If you wish to post data to Emoncms.org, enter your Emoncms.org write apikey found on your Emoncms.org account page.

9) Click save, after around 10-20 seconds the interface should report that the successful packets have been sent to emoncms.org. You can now check the inputs page on your emoncms.org account, which should looks like this:

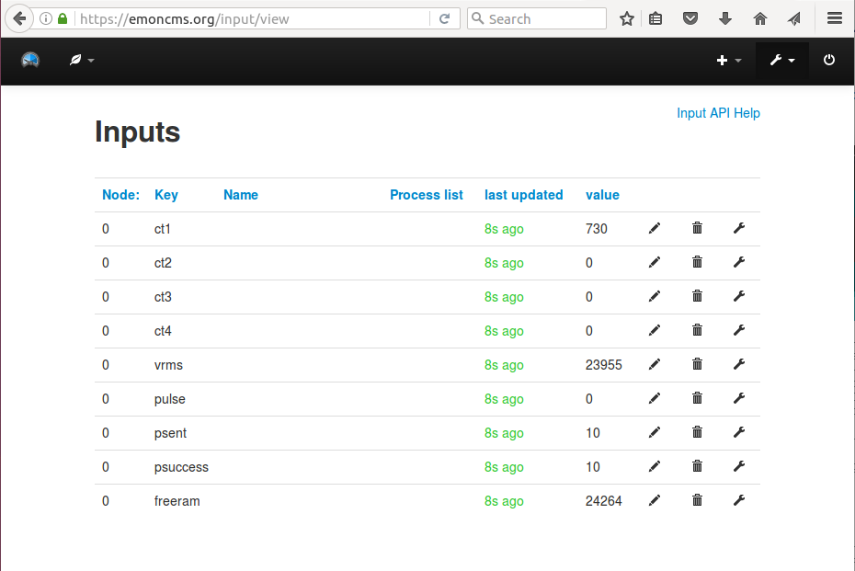
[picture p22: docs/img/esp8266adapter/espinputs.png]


10) Configure Emoncms.org as normal, see emoncms documentation section of guide.

## EmonESP

The ESP8266 needs to run EmonESP firmware. The Huzzah modules sold via the shop are pre-loaded with EmonESP. For more info about EmonESP and to check for updates see [EmonESP Github](https://github.com/openenergymonitor/emonesp).

## MQTT

The emonESP firmware also supports publishing data to an MQTT broker. To use MQTT see the MQTT section on the EmonESP configuration page. You can enter a hostname, username, password and base topic to configure the module to post to an MQTT broker of your choice.

If you have an emonBase or emonPi on your local network the default settings are:

**hostname:** emonpi<br>
**username:** emonpi<br>
**password:** emonpimqtt2016<br>
**base topic:** emon/emontx<br>

*Note: on some networks that don't support hostname lookup you will need to use the IP address of the emonPi as the hostname. Also some networks report local hostname with the .local or .lan extension e.g. http://emonpi.local*

See [emonPi technical overview](../emonpi/technical.md) and [MQTT](../emoncms/mqtt.md) User Guide pages for more info.

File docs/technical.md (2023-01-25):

# Technical

The following has been ported over from the original emonTx3 Wiki page.

## Electrical characteristics

| Function | Parameter | Min | Recommended  Max / typical | Absolute Max  if exceeded, damage may occur | Notes |
|---|---|---|---|---|---|
| CT 1-3 | Monitoring Power @ 240V | | 23kW / 95.8A | 60kW / 250A | Using 22R burden and  YHDC SCT-013-00 |
| CT 4 | Monitoring Power @ 240V | | 4.5kW / 19.2A | 4.6kW max measure – 19.7kW / 82A Max dissipation  | Using 120R burden and  YHDC SCT-013-00 |
| DC half-wave power supply  | Current output | | 20mA | 60mA | Current draw above 20mA AC sample signal will be affected  |
| 3.3V Rail current output | When powered via 5V USB connector  | | 150mA | 168mA | Limitation SOT22 MCP1700 Ta=40C Vi=5.25V |
| Operating Temperature | Temperature | -40C | +40C | +85C | |
| Storage Temperature | Temperature | -50C | | +150C | |
| 5V Input Voltage | USB/FTDI/5V Aux | +3.4V | +6V | +6.5V (see note 1) | See note 1 |
| 3.3V Supply Voltage | on 3.3V supply rail | 2.6V *  | 3.3V | 3.9V RFM69CW | *ADC readings will be incorrect if Vcc is not 3.3V |

*A higher voltage (up to 17.6V) can be used to power the emonTx if power is connected into the MCP1754 through the AC-DC enable jumper pin.*

## Port Map



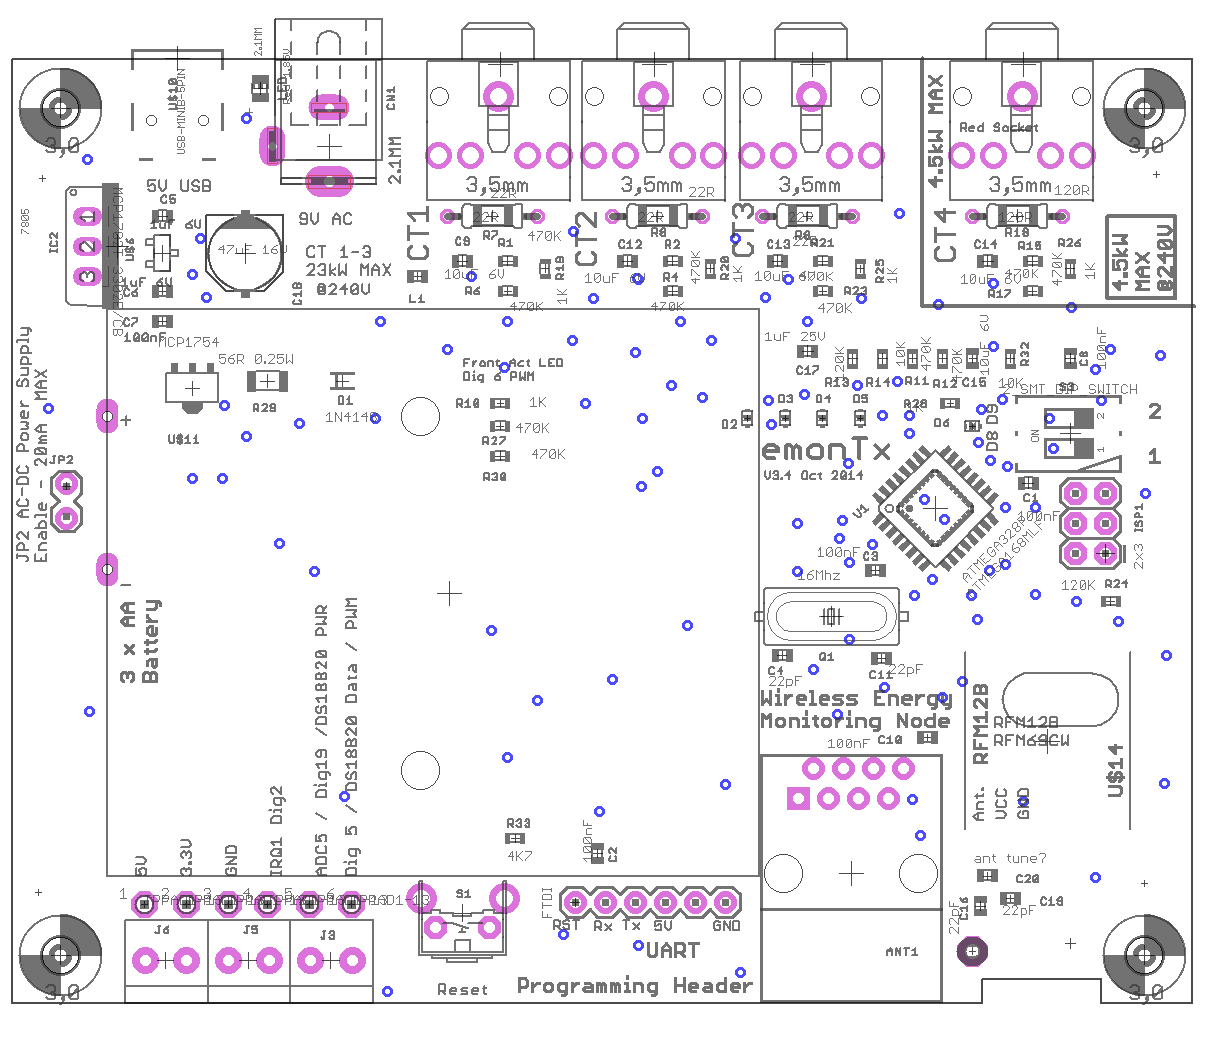
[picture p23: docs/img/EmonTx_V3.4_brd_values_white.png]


*Note: The FTDI connector Tx and Rx pins are reversed on the PCB legend and on the Schematic. Data is received by the emonTx on the Tx pin and transmitted by the emonTx on the Rx pin.*

## Schematic and Board files

Proudly open source, the hardware designs are released under the Creative Commons Attribution-ShareAlike 3.0 Unported License: 

**emonTx Schematic and Board files:**<br> [https://github.com/openenergymonitor/emontx3/tree/master/hardware](https://github.com/openenergymonitor/emontx3/tree/master/hardware)

## CT Sensor Burden Resistor Calculations

The emonTx3 was primarily designed to use the YHDC SCT-013-000 100A, 2000 turns, current output CT sensors. Using this sensor:

- **CT channels 1-3** have a 22R burden resistor, and can measure up to 97A RMS (23.3kW @ 240V) using a YHDC SCT-013-00 CT which has 2000 turns.

- **CT channel 4** has a 120R burden and can measure up to 19.16 A RMS (4.6kW max @ 240 V) 

These burden resistor values were choosen based on the following calculation:

    Peak current primary = RMS current x sqrt(2)

    Peak current secondary = Peak current primary / turns

    Burden resistance = (Analog reference voltage x 0.5) / Peak current secondary

The analog reference voltage on the emonTx3 is 3.3V.

For a capability to measure 100A RMS primary current on CT channels 1-3, the calculated burden resistance is 23.3 Ohms. The closest resistor values are 22 Ohms and 24 Ohms. We selected 22 Ohms giving a measurement range of 0-97A RMS.

For a capability to measure 4kW or 16.7A RMS primary current on CT channels 4, the calculated burden resistance is 139.9 Ohms. The closest resistor values are 120 Ohms and 150 Ohms. We selected 120 Ohms giving a measurement range of 0-19.2A RMS or 4.6 kW @ 240V.

It is possible to change the standard burden resistors on an emonTx3 in order to change the measurement range when using the standard SCT-013-000 CT sensor. E.g to make all CT channels higher sensitivity 4.6kW channels. The burden resistor can also be changed to suit alternative CT sensors, in order to match the CT sensor output and desired measurement range with the emonTx3 ADC input voltage range.

The higher the burden resistance, the smaller the measurement range, the higher the low end accuracy will be. For higher accuracy it's also worth choosing resistors with precise tolerance e.g ±0.1% or ±1%.

The following burden resistor value calculator is a useful tool to work out the best value: [https://tyler.anairo.com/projects/open-energy-monitor-calculator](https://tyler.anairo.com/projects/open-energy-monitor-calculator)

If the power level goes above the CT max rating, the voltage will go above 3.3V and the ATmega328’s ADC will be saturated. A 1K series resistor is used to limit input current to the ATmega. The ATmega 328’s internal clamping diodes will safely limit the voltage, preventing damage. [http://openenergymonitor.org/emon/node/171 ](http://openenergymonitor.org/emon/node/171 )

**Alternative CT sensors**

Using an SCT-016-000 with 6060 turns, at 200A max primary the recommended burden is 33R, which gives a max current rating of 214A

Using an SCT-006-000 with 533 turns, at 20A max primary the recommended burden is 30R, which gives a max current rating of 20.7A

**Burden resistor power rating**

From the YHDC SCT-013-000 test results, the maximum current in the secondary at saturation is 85 mA RMS (primary current 250A – 60kW! @ 240V).

- CT 1-3: the max voltage across the 22 Ohm burden CT at saturation will be 1.87V (measured to be 1.5V RMS by @Robert.Wall). The power dissipation will be `1.87V x 85mA = 159 mW`.

- CT 4: the max voltage across the 120 Ohm burden CT at saturation will be 10.2V (measured to be 5.2V RMS by @Robert.Wall). The power dissipation would be `10.2V x 85mA = 867mW`.

However as the emonTx is designed for domestic use, the maximum rated fuse/RCB is 100A and therefore we can safely design for a maximum of 100A. The current in the secondary at 100A is 50mA (RMS).

- Max voltage in CT 1-3 22R burden = 1.1Vrms (measured by Robert to be 0.935 Vrms). 
- Max power in 22R CT = 55mW.
- Max voltage in CT 4 120R burden = 6V (measured by Robert to be 3.9 V rms)
- Max power in 120R burden = 300mW

If a 0.25W resistor is used, the maximum current in the secondary would be 42mA. This equates to 82A or 19.7kW. CT4 is physically removed from CT1-3 and clearly marked as 4.6kW max.

Given testing results these values have been shown be to conservative, testing results are:

- 100 A, 22 R: Burden voltage = 0.935 Vrms, 2.612 V peak-peak, 40mW
- 100 A, 120 R: Burden voltage = 3.89 Vrms, 12.07 V peak-peak, 126mW
- 250 A, 22 R: Burden voltage = 1.498 Vrms, 5.626 V peak-peak, 102mW
- 250 A, 120 R: Burden voltage = 5.194 Vrms, 21.9 V peak-peak, 225mW

These are the maximum RMS voltages that can be developed.

Conclusion: 0.25W burden and 6V capacitor will be suitable ratings. A 0606 X5R 10uF 6.3V filtering capacitor can be used.

## Power Supply Options

There are four ways to power the emonTx3:

1. USB to UART cable - only recommended for short periods while programming, it is recommended to remove all other power sources
2. 5V DC Mini-USB cable - remove jumper JP2 when powering via DC if AC adapter is present
3. 3 x AA Batteries - remove jumper JP2 when powering via DC if AC adapter is present
4. 9V AC-AC power adapter - with jumper JP2 closed (If jumper 2 is left open then the AC-AC adapter will be used for power sampling but not to power the emonTx3 - see AC adapter voltage sensing and power supply below).

## AC adapter voltage sensing and power supply.

The emonTx3 is designed to use an AC-AC adapter to provide an AC voltage sample and also depending on the configuration power as well. If the emonTx3 detects the presence of an AC adapter at startup, it will automatically implement Real Power and Vrms measurements by sampling the AC voltage. Real Power is what you get billed for, and depending on the appliances connected to the circuit being monitored, can vary significantly from Apparent Power - see Learn for more info on AC power theory. **For best energy monitoring accuracy, we recommend powering the emonTx3 with an AC-AC adapter whenever possible**.

Using the AC-AC adapter also enables the emonTx to monitor the direction of current flow. This is important for solar PV monitoring. If you notice a negative reading when you were expecting a positive one, reverse the orientation of the CT on the conductor.

Powering via the AC adapter is only suitable for standard CT monitoring and up to 4x DS18B20 temperature sensors, transmitting data via RFM69 433Mhz radio. The power supply circuit is only able to deliver a limited amount of current without impacting the voltage sensor accuracy.

To avoid damage to the emonTx3 circuits, the current drawn from the AC circuit should never exceed 60mA. If more than 10 mA of current is required, it is recommended to remove jumper 2 (JP2) and power the emonTx via the 5V mini-USB connector. When JP2 is removed, the AC-AC adapter (if connected) will be used only to provide an AC voltage sample, i.e. it will not power the emonTx.

**If using the emonTx with an ESP8266 WiFi adapter a seperate 5V USB power supply is required.**

## Power supply design considerations

**DC:**<br>
The emonTx3 has been designed to accept power via 5V USB, 3x AA batteries, UART connection or auxiliary input from terminal blocks.

In order to keep quiescent power loss to a minimum, a SOT32 MCP1700 LDO regulator was chosen for battery, USB 5V and FTDI power (5V) operation. The max input is 6V which is fine for battery (3 x AA) and USB operation. The MCP1700 has lower quiescent power consumption than the MCP1754 used in the AC-DC half-wave supply.

Powering from 5V USB (MCP1700 SOT22) Thermal Calculations 

- Max voltage drop required = 5.25-3.3=1.95V
- Thermal resistance junction to ambient (JA) for MCP1700 SOT23A = 230 degrees C/W (from datashet)
- Max case temperature = 150 degrees (from datasheet)
- I max = (T case max – T ambient max)/thermal resistance (JA) / delta V max
- I max (SOT23A) = ((150-40)/336)/1.95V = 168mA (for SOT23A)

The emonTx v3 does not support battery charging. Please ensure batteries are removed before connecting USB or FTDI power. 

**AC-DC:**<br>

For Power supply design circuit design, see blog posts: [[1](http://openenergymonitor.blogspot.co.uk/2012/05/emontx-single-ac-power-supply.html)] ][2](http://openenergymonitor.blogspot.com/2013/01/power-emontx-from-single-ac-power.html)] 

An SOT89 MCP1754 LDO regulator is used in the the AC-DC power supply circuit. The MCP17542 maximum input is 16 Volts. The larger SOT89 package is needed to dissipate the heat. The 47uF capacitor stores enough energy to see us through half wave cycles.

- Thermal resistance junction to ambient (JA) for MCP1702 SOT-89 JA=153.3 degrees C/W (from datasheet P.22)

- Max case temperature = 150 degrees (from datasheet)

- Imax = (T case max – T ambient max)/thermal resistance (JA) / delta V max

At 12Vrms (max output of 9V AC-AC at max mains voltage)

- ΔB = 12-3.3 = 10.7V
- Imax (SOT-89) MCP1754 = ((150-40)/153.3)/10.7V = 67 mA (40C ambient)
- worst case – max mains voltage and 50 degree ambient – max output = 61mA )

At V=10.4Vrms (output of 9V AC-AC at typical mains voltage)

- ΔB = 10.4-3.3 = 7.1V
- Imax (SOT-89) MCP1754 = ((150-40)/153.3)/7.1V = 101 mA (40C ambient)

At V=8.77Vrms (output of 9V AC-AC at min mains voltage)

- ΔB = 8.77-3.3 = 3.62
- Imax (SOT-89) MCP1754 = ((150-40)/153.3)/3.62V = 198 mA (40C ambient) 

Using the MCP1754 with its higher thermal rating means the current limiting resistor dissapation rating is now the bottleneck to how much current can be drawn from the supply.

The AC-DC supply ripple is greatest at high current load and lowest mains voltage.

**AD-DC Power Supply component ratings**

Max operation output of circuit = 20mA

Maximum output of circuit = 30mA. The AC voltage sample will be affected and the MCP1702 could overheat if ambient temperature is 40-50 degrees. 30mA should be drawn only for short periods. E.g. SRF radio Transmitting.

Do not try to draw more than 30mA. This will result in the 3.3V rail dropping significantly, and excess current passing through the 56R current limiting resistor. This will cause the resistor to overheat.

Halfwave rectifier diode D1: Worst case at highest mains voltage and extreme current output: 30mW average

Current limiting resistor: 56R R29. At worst case, lowest mains voltage and extreme current output: Average power dissipation: 222mW. 0.25W resistor will be ok.

Reservoir capacitor C18 47uF: should not see a higher voltage than 12V since the zener diode will clamp the voltage to 12V. A capacitor rating of 16V will be more than enough.

De-coupling 1uF capacitor C17 voltage rating: The transformer is ground referenced, the other side referenced to 1.65 V – so 6.3 V should be plenty. The alternating component of the voltage should be very small, else we have phase shift problems. [The major part of the 12V will appear across the divider chain, R13 + R14.]

Zener diode - 12V MCP1702 over voltage protection 106mW average - not needed since MCP1754 is used and can handle 16V input

Update V3.4.5: Swap to LDK320ADU33R with a max input voltage of 18V since at highest mains voltage 16V max input of MCP1754 was being exceeded** 

## Enclosure

The emonTx V3 PCB is 100mm x 80mm and enclosed in an EBS80 enclosure sourced from Lincoln Binns, see [data sheet](https://www.lincolnbinns.com/en/aluminium-electronic-enclosure-e-case-b-data).

**Community contributed**

- [emonTx DIN-RAIL mount #1 fixing on Thingiverse](http://www.thingiverse.com/thing:1355749)
- [emonTx DIN-RAIL mount #2 fixing on Thingiverse](https://www.thingiverse.com/thing:208177)
- [emonTx > EmonESP > LCD](https://www.thingiverse.com/thing:2043784)
- [emonTx 3D printed case design](https://www.thingiverse.com/nduarte/designs)

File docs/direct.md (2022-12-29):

# emonTx3 direct serial

EmonTx3 data can also be read directly over serial or via a USB to UART cable. When connected to an emonPi/emonBase or RaspberryPi, the data can be read and forwarded directly to emoncms using the emonHub software utility.

## Using a USB to UART cable



**EmonHub interfacer configuration**<br>
To use emonHub to read the emonTx3 data, add the following emonHub OEM interfacer to the EmonHub configuration file in the interfacers section:

    [[USB0]]
        Type = EmonHubOEMInterfacer
        [[[init_settings]]]
            com_port = /dev/ttyUSB0
            com_baud = 115200
        [[[runtimesettings]]]
            pubchannels = ToEmonCMS,
            nodename = emonTx3

## Direct Raspberry Pi GPIO

Both the Raspberry Pi and emonTx v3 run at 3.3V so the serial Receive and Transmit lines can be connected directly. The 5V power rail from the Raspberry Pi can be supplied to the emonTx which is then stepped down to to 3.3V by the emonTx voltage regulator. 5V is provided by the red wire (see photo). The ground connection is the black wire and the serial data going from the emonTx to the Raspberry Pi is the green wire. Wire for serial data going the opposite direction (Pi to emonTx) has not been connected in this example but could be added if two-way communication is required.

```{note}
On the PCB and schematic, the Tx and Rx pins are labelled according to the connections on the Programmer, meaning that data is received by the emonTx on the Tx pin, and transmitted by the emonTx from the Rx pin.
```

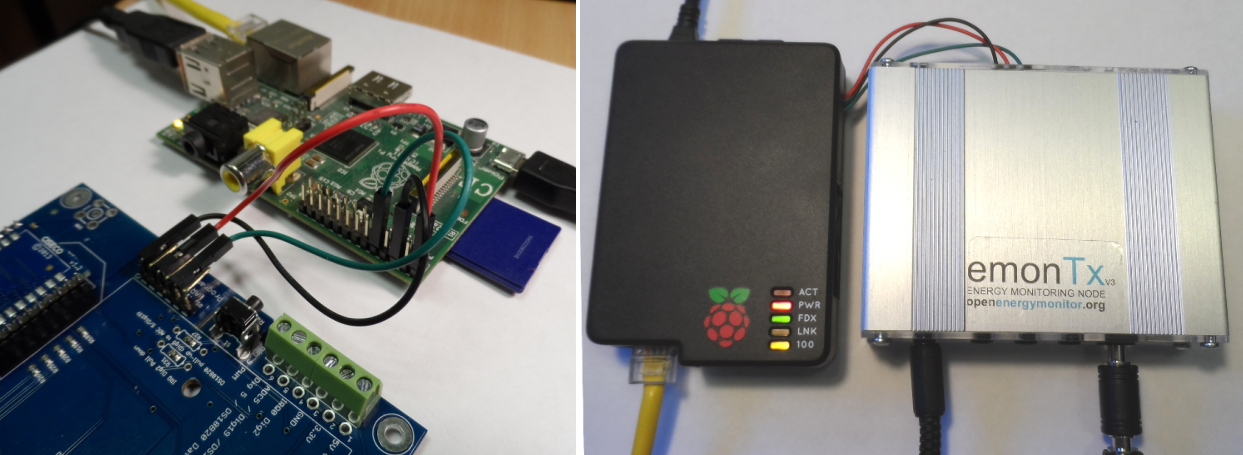
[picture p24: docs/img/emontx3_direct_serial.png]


**EmonHub interfacer configuration**<br>
To use emonHub to read the emonTx3 data, add the following emonHub OEM interfacer to the EmonHub configuration file in the interfacers section:

    [[AMA0]]
        Type = EmonHubOEMInterfacer
        [[[init_settings]]]
            com_port = /dev/ttyAMA0
            com_baud = 115200
        [[[runtimesettings]]]
            pubchannels = ToEmonCMS,
            nodename = emonTx3

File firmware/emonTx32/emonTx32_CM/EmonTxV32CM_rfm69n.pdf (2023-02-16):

# EmonTxV32CM_rfm69n.ino

This sketch should only be used when transmitting data to an emonPiCM that expects the radio data packet to use the “RFM69 Native” format. An emonPi or emonBase not using that format will be unable to receive the data from this sketch. (Use one of the archived sketches, e.g. emonTxV3_2_DiscreteSampling.ino instead.)
This sketch uses the Continuous Monitoring library.

Setting up
The emonTx V3.2 was fitted with a RFM12B radio module, and uses different hardware pins making it not directly compatible with the emonTx V3.4. Neither does it have the two DIP switches, so the NodeID and “USA” mode (line frequency and a.c. adapter calibration) must be set individually either by editing the constants in the sketch or by on-line programming the EEPROM.
The nominal value required for vcal is 130.0, and you should either add the line

EmonLibCM_cycles_per_second(60);
to the emonLib configuration, or use the on-line commands k0 130.0 and then f60 as described for the emonTx V3.4 to set the voltage calibration and line frequency respectively.
Other than that, this sketch is identical to the EmonTxV34CM_rfm69n.ino.

Documentation V1.0.0 for EmonTxV32CM_rfm69n V1.0.0 - 10/7/2021

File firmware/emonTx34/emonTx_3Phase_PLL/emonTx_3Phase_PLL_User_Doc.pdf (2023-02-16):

emonTx_3Phase_PLL

This sketch is a development of the 3-phase ‘discrete sample’ sketch and MartinR’s PLL energy diverter. It is intended for use on a 3-phase, 3-wire or 4-wire system. It utilises advanced features of the Atmel328P microprocessor to provide continuous monitoring of voltage of one phase and the currents in all three phases, thereby allowing a good estimate of real power to be calculated. The physical quantities are measured continuously, the average values are calculated and transmitted at user-defined intervals. Pulse counting and temperature monitoring using a single DS18B20 sensor is supported. This document has the following main sections:
Key Properties – important points about this sketch
Limitations
Initial configuration
Calibration
Installation
Explanation of operation of the sketch
List of required supporting libraries

Key Properties
- Continuous monitoring of one voltage channel and up 4 current channels.
- Gives an accurate measure of rapidly varying loads.
- 1800 sample sets per second – using 4 channels of an emonTx V3.4 @ 50 Hz
- Calculates rms voltage, rms current, real & apparent power & power factor.
- Pulse input for supply meter monitoring.
- Integrated temperature measurement (one DS18B20 sensor).
- User-defined reporting interval.
- Suitable for operation on a three-phase, 3-wire or 4-wire supply at 50 or 60 Hz.
- Can be calibrated for any voltage and current (default calibration is for emonTx with 100 A CTs & UK a.c. adapter).

Limitations
An a.c. adapter is required. Because the voltage of only one phase can be measured, the sketch must assume that the voltages of the other two phases are the same. This will, in most cases, not be true, therefore the powers calculated and recorded will be inaccurate. However, this error should normally be limited to a few percent. Voltage imbalance might be the result of unbalanced loads within your installation, or it might result from the activities of other consumers on the same supply.
If you find that one or other phase voltage is consistently wrong, you might want to consider a small adjustment to the current calibration of the affected phase.
Because of the additional power required for continuous operation, a 5 V USB power supply is likely to be required, even if only the on-board RFM69CW radio is used. The 5 V power will always be required when the ESP8266 WiFi module is added.
The sketch is not compatible with the RFM12B radio module, nor the Arduino Due.
The baud rate for serial communications must not be set greater than 9600 – if an ESP8266 WiFi module is used, its baud rate must be changed to suit.

Initial Configuration

The internal EEPROM memory can be used to retain some of the system settings, configuration and calibration constants. When the settings have been saved to EEPROM memory, those values are read at each power-up thereafter and override the values in the sketch. You can however choose to erase the EEPROM settings, which will restore the default values. How to store, change and revert the settings is explained later.

There are three ways to change the setting. For example:

1. #define USEPULSECOUNT
As it stands, pulse counting is enabled. To disable it permanently, make this line a comment.
2. #define PULSEINT 1
This defines Interrupt 1 as the interrupt for pulse counting. Change the ‘1’ to ‘0’ to make the sketch suitable for the emonTx V2, which counts pulses using Interrupt 0.
3. int nodeID = 11;
This declares the variable nodeID and defines the initial value (11).

Many parameters must be set in the sketch for correct operation. This is done using both pre-processor directives and normal variable definitions. The configuration values in both
“System Settings” and “PLL & ADC Constants and Settings” must be set using both pre-processor directives and normal variable definitions before the sketch is compiled and loaded into the emonTx. The values listed under “Sensor Calibration Constants” and some others (as noted) can be changed while the sketch is running, using the configuration menu.

System Settings
RF_NATIVE
Defines the format to be used for the data transmitted by radio. Permissible values are:
RF_CLASSIC | for the emonPi (with discrete sampling software) or the
| emonBase.
RF_NATIVE | for the emonPiCM (running the Continuous Monitoring
| software).
The format chosen must be the format that the receiving node node uses.

EMONTX_V34
Defines the emonTx model for the I/O pin mapping. Permissible values are:
EMONTX_V2 | for the emonTx V2
EMONTX_V32 | for the emonTx V3.2
EMONTX_V34 | for the emonTx V3.4
EMONTX_SHIELD | for the emonTx Shield
Default: EMONTX_V34

SERIALPRINT
Turns on 'human-friendly' print statements for calibration and commissioning - comment this line to exclude. You should probably comment this when the installation is working satisfactorily. This output format is automatically turned off if either of the other serial output formats is selected.

USEPULSECOUNT

Turns on the ability to count pulses. Comment this line if pulse counting will not required. When enabled, pulse counting and reporting may still be turned on and off using the configuration menu.

PULSEINT
Defines the interrupt number for pulse counting:
EmonTx V2 = 0,
EmonTx V3 = 1,
EmonTx Shield – selectable, see the Wiki.

PULSEPIN
Defines the interrupt input pin:
EmonTx V2 = 2,
EmonTx V3 = 3,
EmonTx Shield – selectable, see the Wiki.

PULSEMINPERIOD
Defines the default minimum period between pulses, in milliseconds. This should be made smaller than the minimum time between switch operations where a mechanical switch is used (e.g. a magnetic reed switch). Set this to 0 for an electronic sensor with a solid-state output, where there is no risk of contact bounce. This setting can be changed using the configuration menu.
Default value: 110

RFM69CW
Defines the mode of transmitting the output data. Permissible settings are: RFM69CW Hope RFM69CW radio module
SERIALOUT Wired serial connection via the FTDI port (suitable for direct connection to the emonBase or emonPi
(see https://github.com/openenergymonitor/emonTxFirmware/blob/master/emonTxV3/noRF/emonTxV3_DirectSerial/emonTxV3_DirectSerial.ino ) EMONESP ESP8266 WiFi module
(see https://github.com/openenergymonitor/EmonESP) If neither radio nor serial connection is required, do not define anything - in which case, the serial output will be ‘human readable’ for information and debugging only.
NOTES:
1. The sketch cannot be used with the Hope RFM12B radio, and will hang if the wrong radio module is specified, or if one is specified and not fitted.
2. Depending on the data format specified, radio transmission will use either the JeeLib “Classic” format or the “RFM69 Native” format. The correct format for the receiving Base node must be chosen.
3. The baud rate for serial communications must not be set to a value greater than 9600. (For the ESP8266 module, change Line 41 or thereabouts in the ESP8266 file “src.ino”.)

RF12_433MHZ
Defines the frequency of RFM module. This can be
RF12_433MHZ
RF12_868MHZ
RF12_915MHZ
You should use the one matching the module you have. Do not operate the transmitter at or near maximum power if it does not have an efficient matching antenna for the chosen frequency.
NOTE: This is different from the normal OEM definition.

networkGroup
Sets the wireless network group. This must be same as the emonBase / emonPi and the emonGLCD. The OEM default is 210. This setting can be changed using the configuration menu.
Default: 210

nodeID
Sets the node ID for this emonTx. If DIP switch 1 was ON at power-up, then the nodeID is one more than the number specified. This setting can be changed using the configuration menu.
Default: 11

RFPWR 25
Sets the transmitter power.
The control range for transmitter power is 0 - 31 = -18 dBm to +13 dBm.
NOTE: Ensure a correctly matched antenna is used when operating at or near maximum power, otherwise the module may be damaged. The RFM12B equivalent power is: 25 ( +7 dBm ).
Default: 25 = +7 dBm
A 5 V d.c. USB supply is likely to be required if the transmitter is operated above minimum power.

Sensor Calibration Constants
These values can be changed at run time and the new value stored in EEPROM memory, using the configuration menu. Thereafter, the stored value is used instead of the values in the sketch.

VCAL
The voltage at the sensor input that gives 1 V rms as measured by the ADC input. It is a function of the a.c. adapter / transformer voltage ratio and the resistor divider network. For the emonTx V3 using the ‘standard’ UK a.c. adapter, the calculated value is 240:11.6 x 13:1 = 268.97
For the emonTx Shield, the calculated value is 234.2
This value depends on component tolerances and should be adjusted for best accuracy. If DIP switch 2 is ON at power-up, then the calibration constant for the EU a.c. adapter is used.
Default: 268.97

I1CAL – I4CAL
The current at the sensor input that gives 1 V rms as measured by the ADC input. It is a function of the current transformer ratio and the burden resistor value (or the current transformer’s current:voltage ratio for c.t’s with an internal burden resistor).
For the emonTx V3 inputs 1-3 and the ‘standard’ current transformer, the calculated value is 100A:0.05A for current transformer ÷ 22 Ω for resistor = 90.91
For the emonTx Shield, the calculated values are 60.6 & 16.67
This value depends on component tolerances and should be adjusted for best accuracy. Default: 90.91 for inputs 1 – 3, 16.67 for input 4.

I1LEAD - I4LEAD
The number of degrees by which the a.c. adapter / v.t. phase error leads the c.t. phase error. This can be obtained from the manufacturers’ or from test data, or can be established by trial and error during calibration, or by loading and running a test sketch.
NOTE: Input 4 of an emonTx will probably be significantly different, even with the same c.t., due to the different burden resistor.
Default: 2.00 for c.t’s 1 – 3, 0.2 for c.t. 4.

period
Sets the time between data transmissions in milliseconds. Default: 5000

pulse_enable
Turns on pulse counting. Default: true

pulse_period
A delay (in ms) to prevent multiple counts due to contact bounce. May be set to zero if an electronic switch is used.
Default: 110

temp_enable
Enables temperature measurement. Default: true

showCurrents
Displays voltage, currents and power factors as an aid to calibration.
Default: false

VCAL_EU
Sets the default voltage calibration (for the European a.c. adapter) when DIP switch 2 is on.
Default: 260.0

PLL & ADC Constants and Settings

WIRES
Defines the number of wires in the system. Permissible values are:
3-WIRE
4-WIRE
Use 3-WIRE where no neutral is available and the a.c. adapter and all loads are connected Line – Line,
use 4-WIRE where there is a neutral and the a.c. adapter is connected Line – Neutral, and loads are connected mainly Line – Neutral, though Line – Line is permissible. Default: 4-WIRE

CT1Phase
CT2Phase
CT3Phase
CT4Phase
Attaches c.t.1 - 4 to one of the phases to allow the correct voltage reference to be used for real power calculations. Permissible values are:
PHASE1
PHASE2
PHASE3
Phase 1 is defined as being the phase that feeds the a.c. adapter, irrespective of the wire colours or labelling. Phases 2 & 3 follow phase 1 in that order.
C.T’s 1 – 3 must be specified, only c.t.4 is optional. If c.t.4 is not needed, comment the appropriate line. This permits a faster sampling rate to be selected – see NUMSAMPLES below.
Defaults:
c.t.1: PHASE1 | c.t.2: PHASE2 | c.t.3: PHASE3 | c.t.4: PHASE1

LEDISLOCK
The on-board LED lights to indicate that phase lock has been obtained, and flickers very briefly to indicate a data transmission (this might not be readily visible). Comment this line for the ‘standard’ LED behaviour where a flash indicates data transmission.

SUPPLY_VOLTS
Specifies the reference voltage for the ADC. This will normally be 3.3 for any emonTx but 5.0 for an Arduino (including the emonTx Shield). If the accurate voltage is known, it may be specified. This value affects the calibration of every analogue input.
Default: 3.3

SUPPLY_FREQUENCY
The nominal supply frequency, either 50 or 60.
Default: 50

NUMSAMPLES
The number of times to sample each 50/60Hz cycle. The number chosen must be a multiple of 3 for a 4-wire system, and a multiple of 6 for a 3-wire system. Permissible maximum values are:
| 3 c.t’s | 4 c.t’s
50 Hz | 45 | 36
60 Hz | 36 | 33

Lower values are permissible, but in general should not be used without good reason. (E.g. if phase lock is lost.)
Default: 36

ADC_BITS
Defines the resolution of the ADC. 10 for the Atmel 328P (emonTx, many Arduino boards). Default: 10

ADC_RATE
The time between successive ADC conversions in microseconds. This is calculated from the clock frequency and the divider setting. Do not change this unless either of these is changed.
Default: 64

PLLTIMERRANGE
Sets the limits for the PLL timer. 100 = ~ +/-0.5Hz. This should not normally be changed. Default: 100

PLLLOCKRANGE
The allowable ADC range to enter locked state. This should not normally be changed. Default: 40

PLLUNLOCKRANGE
The allowable ADC range to remain locked. This should not normally be changed. Default: 80

PLLLOCKCOUNT
The number of cycles to determine if PLL is locked. This should not normally be changed. Default: 100

Calibration

Calibration might not be necessary provided that the ‘standard’ components are used. However, if there is any deviation from this, and especially if the optimum accuracy is desired, then the unit must be carefully calibrated using known good test instruments.
If test instruments are not available, then by adjusting the various calibration constants by small amounts, over a period of time, it should be possible to obtain agreement with the energy supplier’s meter.

Before calibrating the sketch, read (but do not do) the calibration instructions in Learn > Electricity Monitoring > Current & Voltage. Those instructions contain the general procedure and safety warnings, which you must be familiar with. The detailed instructions that follow apply only to this sketch. Follow these instructions for the order in which to make the adjustments and how to apply the values in the sketch, but follow the general instructions for how to proceed with the measurements.
1. Obtain a resistive load that will draw a current that is close to but less than the maximum that your multimeter can read and less than the rating of your c.t. Steps 2 – 5 that follow can be done on the test bench.
2. Plug in the a.c. adapter. Set the output to use SERIALPRINT, i.e. if you have enabled SERIALOUT or EMONESP, temporarily disable those. Using the on-line configuration (for details of how to use this, see the section On-line calibration & configuration below) to turn on the display of voltage, currents and power factors (“c1”).
Using your multimeter (or a reliable voltage measurement), adjust VCAL so that the voltage measured is the same as your meter indicates.
3. Set all three main c.t’s (inputs 1 – 3) on the cable to your test load, and all facing the same way. If you are using c.t. 4, put this on the cable too. Label the c.t’s, because the calibration is for the combination of c.t. and input. From now on, each c.t. must stay with the same input.
Temporarily set the sketch to 4-wire, and set each CT phase to PHASE1.
4. Insert your multimeter in series with the test load, to measure current. The power factor for every c.t should be nearly +1.0. If it is negative, reverse all the c.t’s on the cable, or reverse your a.c. adapter – if it is of the type that can be reversed. (But if you do reverse your a.c. adapter, from now on ensure you do not reverse it again.) Adjust the current calibration factors I1CAL, I2CAL, I3CAL & if appropriate I4CAL to read the same current as your meter. Ignore the power values and power factor. When done, take the meter out of circuit. If you are using (say) an inverter’s power meter to calibrate, set I1CAL to give the correct c.t.1 power, but set I2CAL, I3CAL and I4CAL to give the same currents as c.t.1.
5. Adjust I1LEAD, I2LEAD, I3LEAD and if appropriate I4LEAD so that the power factor for each c.t is as close as possible to 1.000.
6. Set the sketch to 3-wire or 4-wire according to your power system, and in the sketch set each CT to the phase it will be used on. Leave the c.t’s on your test load.
Check (but do not re-adjust) the power factors:
For a 4-wire system, the power factor for the c.t’s on phase 1 should be nearly +1.0, the c.t’s on phase 2 and phase 3 should be close to -0.5
For a 3-wire system, the combined power for inputs 1 & 2 should be 1.5 times the previous value, and the combined power factor should be close to +0.75, a c.t on phase 1 should be +1.0, and a c.t on phase 2 should be close to +0.5
Transfer the c.t’s to their final positions.

No calibration is required for the temperature sensor.

Temperature Sensor Error values:
300.00 | : | Sensor has never been detected since power-up/reset.
302.00 | : | Sensor returned an out-of-range value.
304.00 | : | Faulty sensor, sensor broken or disconnected.
85.00 | : | Although within the valid range, if it is not close to the expected
| | value, this could represent an error, and might indicate that the
| | sensor has been powered but not commanded to measure
| | (‘convert’) the temperature. It might be a symptom of an
| | intermittent power supply to the sensor.

Pulse sensor.
If multiple pulses are counted where only one is expected, and a mechanical reed switch is in use, then it might be necessary to increase the value in PULSEMINPERIOD.

Installation

It is possible that there will be exposed live metal parts where you install the current transformers. If you think this might be the case, take the greatest possible care and ensure that you, or nothing that conducts electricity, touches a live part.

At the place where you will install the c.t’s, identify the phase sequence and the phase on which the a.c. adapter will be installed. This is most important. If you cannot identify the phase sequence from the wire colours or the labelling, you will need to do this by trial and error:
Plug in the a.c. adapter. This will define phase 1 as far as the sketch is concerned, even though that might not be phase 1 as indicated by the phase colours or labels or terminal numbers on the meter or main circuit breaker.

Use your test load, and note its power rating. Switch off all other loads. Put the c.t. for phase 1 (c.t. input 1) onto one of the main phase conductors. Plug the test load into each phase in turn. If, at some point, the test load reads the correct power, c.t.1 is on the correct phase. If it reads half the correct power, the c.t. is not on the correct conductor for phase 1, so choose another and repeat the process.

When you have identified phase 1, repeat with the remaining c.t’s and the remaining phase conductors.

Our convention is consumed power is positive. Reverse the c.t. on its cable if the power is negative. If you use an a.c. adapter that is reversible, that may be reversed if all the c.t’s indicate the wrong polarity. Take care not to reverse the a.c. adapter subsequently.

Pulse Input
A reed switch or S0 sensor should be wired between the input pin and GND.
On-line calibration & configuration

On-line calibration & configuration is not available when the serial output is being used for machine-read data (i.e. when SERIALOUT or EMONESP has been set).

The user can change the Frequency band, Network Group and the Node ID, and adjust the sensor calibration and some other settings when running.

To enter configuration mode, using the serial monitor part of the Arduino IDE, enter “+++” followed by the [Enter] key. You may do this at any time during operation. When finished, be sure to exit configuration mode with the ‘x’ command, so as to minimise the likelihood of accidentally changing the settings.

You will then see a menu:

l | - list the settings
r | - restore sketch defaults
s | - save settings to EEPROM
v | - show firmware version
z | - zero energy values
x | - exit, lock and continue
? | - show this text again
w<x> | - turn RFM Wireless data off: x = 0 or on: x = 1
b<n> | - set r.f. band n = a single numeral: 4 = 433MHz, 8 = 868MHz,
| 9 = 915MHz (may require hardware change)
p<nn> | - set the r.f. power. nn - an integer 0 - 31 representing -18 dBm
| to +13 dBm. Default: 25 (+7 dBm)
g<nnn> | - set Network Group nnn - an integer (OEM default = 210)
n<nn> | - set node ID n= an integer (standard node ids are 1..60)
d<xx.x> | - xx.x = a floating point number for the datalogging period
c<n> | - n = 0 for OFF, n = 1 for ON, enable voltage, current & power
| factor values to serial output for calibration.
k<x> <yy.y> <zz.z>
- Calibrate an analogue input channel:
| x = a single numeral: 0 = voltage calibration, 1 = ct1
| calibration, 2 = ct2 calibration, etc
| yy.y = a floating point number for the voltage/current
| calibration constant
| zz.z = a floating point number for the phase calibration for
| this c.t. (z is not needed, or ignored if supplied,
| when x = 0)
| e.g. k0 256.8
| k1 90.9 2.00
m<x> <yy> | - meter pulse counting:
| x = 0 for OFF, x = 1 for ON, <yy> = an integer for the pulse
| minimum period in ms. (y is not needed, or ignored when x = 0)
t0 <y> | - turn temperature measurement on or off: y = 0 for OFF, y = 1 for ON
t<x> <yy> <yy> <yy> <yy> <yy> <yy> <yy> <yy>
- change a temperature sensor's address or position:
| x = a single numeral: the position of the sensor in the list
| (1-based)
| yy = 8 hexadecimal bytes representing the sensor's address
| e.g. 28 81 43 31 07 00 00 D9
| N.B. Sensors CANNOT be added.

When you change one or more of the settings, the change will take effect immediately, though the full effect might not be seen until a full reporting interval has passed. i.e. the second set of values displayed will show the full effect of a calibration change.

For the settings you change when running, you will normally see a confirmation message, and you will see the displayed values change. You will see further confirmation when you save the changes.

Option (‘s’) will save all the changes. If you do not do this, the settings will revert to the previous values at the next restart. After you save (‘s’) the changes, the new settings will be used forever, or until changed again.

If you restore the sketch default values (‘r’ ), the EEPROM data is erased and the sketch restarts immediately, using the values set in the sketch. There is then no means of recovering the EEPROM data.

If this sketch has previously been used in the same hardware, then the values saved in EEPROM will be used again. If an old version of this sketch has been used, run that sketch and make a note of the configuration and calibration values before loading this version. If an old version or a different sketch has been used previously, any configuration saved in EEPROM will be erased when a new configuration is saved. The command ‘r’ will erase the EEPROM to the manufacturing default values and the sketch will restart using its own set values.

## Explanation of operation of the sketch

General Principle

The sketch measures samples of voltage and current many times in each cycle of mains electricity. To be able to measure real power and energy, which is the quantity that energy suppliers generally charge for, the relationship between voltage and current must be known. The emonTx has only one voltage input, and as this sketch is designed for 3-phase use, it is necessary to use artificial methods to obtain a voltage reference for the other phase(s).

In the case of a 4-wire (3 phases + neutral) supply, there are two other phases. The voltage reference for these is obtained by ensuring that the number of voltage readings in one mains cycle is a multiple of three, and by storing the voltage readings for one third and two thirds of a cycle, they can be made to coincide with the second and third phases of the mains supply.

In the case of a 3-wire (no neutral) supply, one phase conductor is treated as the neutral and so there is only one other ‘phase’ and it is displaced one sixth of a cycle behind the first. In this case, the voltage reference for the second phase is obtained by ensuring that the number of voltage readings in one mains cycle is a multiple of six, and by storing the voltage readings for one sixth of a cycle, they can be made to coincide with the second phase of the mains supply.

The sketch uses a Phase-Locked Loop (PLL) to ensure that the readings always happen at the same place on each phase on each mains cycle, even though the mains frequency can change.

Pairs of readings (voltage and current) are multiplied together and added in an accumulator. At the end of the ‘reporting period’, the average power is calculated and transmitted. The rms averages for the voltage and current are calculated in a similar way.

What is a PLL – operating principle
A Phase Locked Loop (PLL) is a particular form of a closed loop control system. It is often used, as here, to follow the changes in frequency of some incoming signal. In our case, that is the mains electricity supply.
If we set up our emonTx to measure the mains voltage and current 1800 times per second, (that's 36 times per cycle in the UK) then as long as the mains frequency remains at 50 Hz, and as long as the clock in our emonTx is accurate and doesn't drift, then we will indeed take exactly 36 measurements in each cycle, and on successive cycles each measurement will be at exactly the same place on the wave. Clearly, in practice even if we can start out like this, it won't stay like it for long. Both the mains frequency and our clock can drift, and so the measurements will slide

36th sample late: Positive voltage at crossing is subtracted from the count, shortening the time period.

36th sample early: Negative voltage at crossing is subtracted from the count, extending the time period.

backwards and forwards along the wave as the two frequencies change relative to each other.
To stop this from happening, we must control the frequency at which we make the measurements so that they happen at exactly the same place on the wave each time. If we say we start measuring when the mains voltage crosses zero going positively, then the 37th
measurement should again be zero. If our clock is running fast, we will get there early and the voltage will be negative and we need to slow our clock; on the other hand, if we are late the voltage will be positive and we need to speed our clock up. So we are not only locking our clock and the frequency of our measurements to the mains, we are also locking every 36th measurement to the positive-going zero crossing of the voltage. We have a phase locked loop.

The ADC and interrupts

The analogue to digital converter (ADC) in the Atmel processor can run in one of two modes. The data sheet lists features that are key to how we use the ADC:
- Free Running or Single Conversion Mode
- Interrupt on ADC Conversion Complete
This sketch uses the “Single Conversion Mode”. The first conversion is started by an interrupt from Timer 1, which is the timer that controls the PLL. This “interrupts” the main program, and a special function, the “interrupt handler” or “Interrupt Service Routine” (ISR) then runs. It is from here that the instruction to start the first conversion is sent. When that conversion completes, we tell the ADC which conversion to perform next. While the ADC is converting, the main program is free to carry on with whatever it was doing.
When the ADC finishes the first conversion, it puts the result in a special place. It also generates an “Interrupt on ADC Conversion Complete”. This again interrupts the main program, and a second ISR then runs to pick up the result and do something useful with it (and it’s this function that tells the ADC which conversion to do next).

This second ISR is at the heart of the sketch. In addition to directing the operation of the input multiplexer and the ADC, it performs the initial calculations on each sample to remove the initial offset, multiplies or squares the samples and accumulates them over the measuring period.

The maths – removing the bias offset

The way that the ADC input works means that we must ‘bias’ the input signal to mid-way between the power supply rails in order to measure an alternating voltage. But that means we must then remove the effect of that bias in order to read the correct value. That can be done by measuring the average input over a long time (a whole number of mains cycles) and then subtracting that average from the readings. This has the advantage that we do not need to do complicated maths using decimal numbers on each reading – we can simply multiply voltage and current (for the power) or multiply the current or voltage by itself for the rms value – and add the result to an accumulator. This inherently uses integer mathematics, which is a simpler and faster operation than calculating decimal fractions in a software filter.

Purely to reduce the size of the numbers, we actually subtract the nominal offset – 512 for a 10-bit ADC – first, then perform the multiplication and accumulation, finally removing the remaining offset at the end of the measurement period. For the real power, we simply subtract the “offset power”, which is the product of the voltage and current offsets. For the rms current and voltage, we make use of a simplified version of the formula for the rms value of a wave with many components:
[rms of signal+offset]=√(signal²
+offset²
).

The maths – removing the effect of timing and transformer phase errors

The physical properties of all transformers means that there will be a phase error between input and output. Careful design and choice of materials can minimise this, but there will always be some error. We also introduce a timing error because, having only one ADC, it is necessary to measure voltage and current one after the other. Fortunately, we can use the same software to compensate for these two effects together. The first step is to read the current first, because generally, the current transformer has the smaller error – which is almost always a ‘phase lead’ – meaning the current appears to have been measured before it actually was. The voltage transformer (a.c. adapter) has a much greater phase lead, so by measuring it later, we have already partly compensated for its phase lead. But we have no control over the time between readings, that is decided by the ADC. However, it is possible to interpolate between voltage samples to generate a new voltage wave that we can move about in time at will.
The formula used by emonLib, which does this calculation for each voltage sample and then multiplies the ‘shifted’ voltage sample by the current sample to give the instantaneous power, which is then averaged over the sampling period, is

average power=

k
n∑0

n−1
[(lastSampleV + PHASECAL∗(sampleV −lastSampleV ))∗sampleI]

where k is a calibration constant depending on the voltage and current calibration constants, the ADC reference voltage and the ADC resolution, and n is the sample count.

Because PHASECAL is a constant, the equation can be rearranged as

average power=

k
n

.(PHASECAL.∑0

n−1
[sampleV ×sampleI ]+(1−PHASECAL).∑0

n−1
[lastSampleV×sampleI])

This implies that the two multiplications can still be done with integer arithmetic, it follows that the summation is integer arithmetic, and the only calculation that requires decimal precision is multiplication by PHASECAL or (1-PHASECAL) and the final scaling by k/n. And that is done after summation, in the main program where time is not critical.
One final refinement is to adjust the values of PHASECAL and (1-PHASECAL) to compensate for the amplitude change that interpolation creates. For a pure sine wave, the coefficients are modified thus:

average power=

k
n

.( X×∑

0

n−1
[sampleV ×sampleI]+Y×∑

0

n−1
[lastSampleV ×sampleI])

where
Δ=samplinginterval
Φ=phase error differencebetweentwo transformers
Y=sinΦ/sin Δ
X=cosΦ−Y×cos Δ

While interpolation still introduces some more distortion to already distorted waves, such as the ‘flat-topped’ mains wave shape commonly encountered, it is much less than when extrapolation is used.

Detailed description of the sketch

### 1. emonTx_3Phase_PLL.ino

The first part, lines 1 – 186, contain comments and the normal settings that the user might need to change. There should be no need to change anything below line 150.

Debugging pins – lines 194 – 200
These are pin allocations for attaching an oscilloscope, to monitor timing etc. Due to the limited availability of accessible output pins, it might be necessary to re-use pins already allocated. This will create a conflict, proceed with care.

Line 202 - Arduino pin use.
Definitions of I/O pins for various hardware.

Line 264 - constants calculated at compile time.
Values substituted by the pre-processor, placed here primarily to reduce clutter in the code.

Line 286 - Temperature sensor definitions.

Line 301 - Pulse counting definitions and variables.

Line 323 - Data structure for RFM transmitted data.

Line 328 – Variables for rarely changed intermediate calculations.

Line 334 - Values accumulated over 1 mains cycle. These are shared between the ISR and the main program.

Line 340 - Values accumulated over the reporting period. These are of necessity 64-bit values, and used exclusively in the main program.

Line 346 - Function and variable declarations used in final stages of calculation.

Line 375 - setup( ). Set I/O pins, serial comms, initialise RF module. The first temperature measurement is started, the ADC is set up (but not started) and the phase correction coefficients calculated. Finally, the timer is started.

Line 512 – loop( ). The main loop processes no time-critical operations. As each mains cycle completes, it add the cycle accumulated values to the period accumulators, and at the end of the reporting period - ‘nextTransmitTime’, it calculates the average values, fetches the temperature reading, and transmits the data. It then starts the next temperature conversion. (Note: temperature readings may therefore be “old” by nearly the full reporting interval. Normally, temperature will change only slowly so this is of little consequence.)

Line 514 – getSettings( ). If user input is present (via the IDE serial monitor), then this allows sensor calibration to be achieved and some other settings changed without reloading the sketch.

Line 553 - Timer 1 interrupt handler. Timer 1 is the main timer for the PLL. It runs at a frequency that is nominally the mains frequency times the number of samples per cycle

(i.e. between 1440 and 2250 per second), and each time starts the ADC with the conversion of the first (c.t.1) current.

Line 566 - ADC interrupt handler. This is the heart of the sketch. It executes when the ADC has completed a conversion. First (lines 549-552) it fetches the result of the conversion just completed and removes the nominal offset of half the ADC range. Then, depending on which conversion has just completed, it starts the next one.
For the current samples, it stores the I value and the I² value in their respective accumulators.
For the voltage sample, it stores the V value and the V² value in their respective accumulators, then it goes on to accumulate the ‘partial’ power values (which will eventually give the totals for using in the phase & timing correction formula) for each of the three or four c.t’s.
Finally, it calls the function that updates and corrects the PLL timing so that synchronism is maintained.

Line 650 - PLL update function. This is called from and is therefore part of the ISR. It looks for the end of a cycle, and checks the voltage that was measured. If it is rising, then the Timer 1 count is adjusted as described earlier. If lock has been lost, then the timer is set so that lock can be regained as quickly as possible. The ‘locked’ flag is controlled from here.

Line 702 - addsumCycle( ) This function is called by the main loop when a mains cycle ends, and transfers the cycle totals into the ‘period’ accumulators.

Line 755 - removeRMSOffset( ). Applies the formula to remove the residual offset from the rms value that includes the offset.

Line 761 - removePowerOffset( ). Subtracts the “offset power” from the average power that includes the offset.

Line 766 - Converts degrees to radians for the trigonometric functions.

Line 771 - applyPhaseShift( ). This function calculates the real power from the two ‘partial’ power values.

Line 780 - Calculate voltage, current, power and frequency.
This is the final calculation to produce the result of the measurement in engineering units. First, the frequency is calculated, then the residual offsets are removed and the true value of real power, apparent power and power factor calculated for each c.t.
The data structure for the RFM module is filled (line 849) and the period averages are zeroed.

Line 886 – calculateConstants( ). Calculate the internal, rarely changed, ratios used in the calculations.

Line 909 – calculateTiming( ). Calculate the coefficients for applying the phase error correction by interpolation.

Line 925 - Send the results. The results are formatted according to the eventual destination (screen display, ESP8266 or emonBase/emonPi) and sent to the serial output.

Line 1059 - isTemperatureSensor( ) Checks for the presence of the temperature sensor.

Line 1064 - convertTemperature( ) Issues the command to the DS18B20 to measure the temperature.

Line 1071 - readTemperature( ) This commands the DS18B20 to send the temperature reading on the OneWire bus, processes and converts the data to a temperature. An error value is returned if a fault is detected.

Line 1105 - onPulse( ). This is the ISR triggered by a pulse from a reed switch, Hall effect or optical detector. Pulses occurring sooner than PulseMinPeriod after the previous one are ignored, this effectively removes contact bounce. PulseMinPeriod may be set to zero if the input device does not exhibit contact bounce.

### 2. config.ino

This handles the ‘on-line’ configuration and calibration commands.

Line 25 – loads the EEPROM standard library and the OEM extensions to that. The structure ‘EEProm’ is the interface between the sketch variables and EEPROM memory.

Line 70 – load_config(bool verbose) Reads data from EEPROM and assigns it to the relevant variables. If the first byte of EEPROM is 0xFF (255), it is assumed that the EEPROM memory is either unused or erased, and no action is taken, therefore the values set in the sketch are used. If ‘verbose’ is true, the values are printed to the serial user interface. The values should not be printed when using SERIALOUT or EMONESP.

Line 83 – list_calibration( ) Prints the calibration constants.

Line 108 – save_config( ) Transfers the configuration variables into EEPROM.

Line 117 – wipe_eeprom( ) Writes the value 0xFF (255) to the area of EEPROM in use. (This is the default value before first use of the EEPROM memory.)

Line 126 – softReset( ) Restarts the processor

Line 132 – getPass( ) This gets and verifies the user access code. “+++” shows the help text immediately, “++s” inhibits that, but commands are still acknowledged and the ‘help’ is displayed when requested, etc)

Line 273 – getSettings( ) This handles user input via the IDE Serial Monitor at run time. If no serial input is available, no further time is wasted and the function returns immediately. Provided that settings are already enabled, the incoming buffer is processed. The first character is read and that determines the subsequent action: if further values are expected, the following 1, 2 or 3 values are read and the values are loaded into the appropriate constants, and the necessary follow-up actions (calculation of other variables, including the phase calibration) is done.

Line 400 – showString( ) Prints the help text.

Line 411 – set_temperatures( ) This handles the temperature settings (enable, set addresses). Note that this code is common to all emonTx sketches, but only one sensor is allowed due to the time taken to retrieve the reading.

REQUIRED LIBRARIES
These libraries are required to support the sketch:
Wire | [Arduino standard library]
OneWire | (Paul Stoffregen)
SPI | [Arduino standard library]
CRC16 | [Arduino standard library]
EEPROM | [Arduino standard library]
rfmTxLib.h | [OEM library]
or
rfm69nTxLib.h | [OEM library]

Acknowledgements
Martin Roberts (MartinR) for the original PLL energy diverter and RFM12B interface. Jörg Becker for background work on interrupts and the ADC.
@ursi (Andries) and @mafheldt (Mike Afheldt) for suggestions made at https://community.openenergymonitor.org/t/emonlib-inaccurate-power-factor/3790 and https://community.openenergymonitor.org/t/rms-calculations-in-emonlib-and-learn-documentation/3749/3
@Simsala (Elias – Rexometer) for invaluable testing in a 3-phase environment. @Bill.Thomson (Bill Thomson) for testing at 60 Hz.
Documentation Version 2.0.0 | Derived from Version 1.7 Reference to file “rfm.ino” removed. 11th July 2021

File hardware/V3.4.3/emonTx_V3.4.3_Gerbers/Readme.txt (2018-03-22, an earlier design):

emonTx V3.4.3 - September 2017

PCB to be 1.6mm thickness
Solder Resist: Blue
Finish: HASL

* DC Socket (CN1) holes are to be milled slots plated through
* No silkscreen should overlap pads
* Check Welsh Daragon logo on the rear is re-produced OK :-)

OpenEnergyMonitor.org 
glyn.hudson@openenergymonitor.org
01248672607

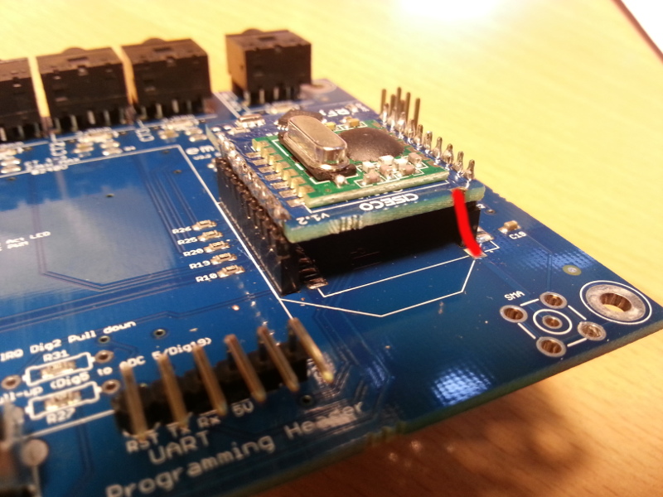
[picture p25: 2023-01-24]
hardware/V3.2.x/img/EmonTx_V3_SMA_RFu_headers.jpg

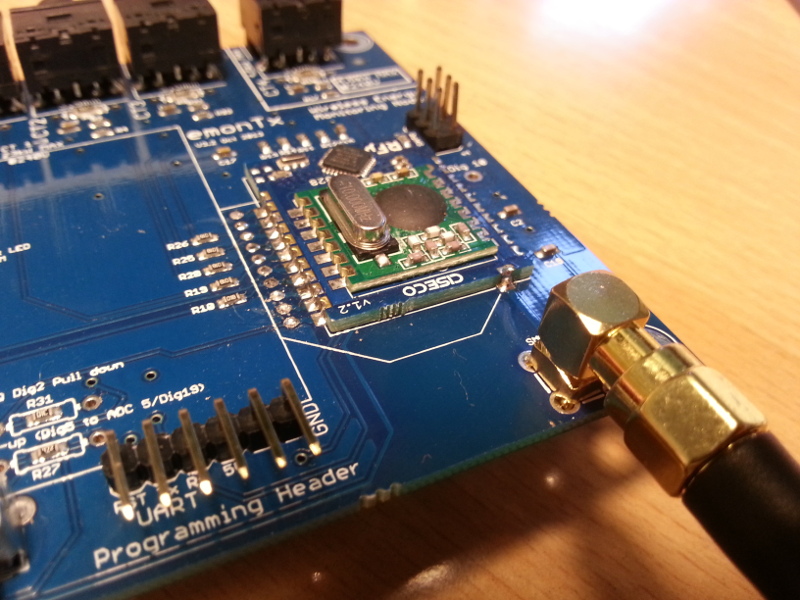
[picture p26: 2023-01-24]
hardware/V3.2.x/img/EmonTx_V3_SMA.jpg

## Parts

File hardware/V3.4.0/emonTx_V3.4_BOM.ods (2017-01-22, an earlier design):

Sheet: SMT
Item | Qty Per | Stock Name | Board Locations | Manufacturer Part No. | Man
1 | 12 | Chip Resistor 0603 470K 1% | R1, R2, R4, R6, R11, R12, R15, R17, R21, R23, R27, R30 | CR0603F474 | GEN
2 | 6 | Chip Resistor 0603 1K 1% | R10, R19, R20, R25, R26, R28 | CR0603F102 | GEN
3 | 3 | Chip Resistor 1206 22R 1% | R7, R8, R9 | CR1206F220 | GEN
4 | 1 | Chip Resistor 1206 120R 1% | R18 | CR1206F121 | GEN
5 | 2 | Chip Resistor 0603 120K 1% | R13, R24 | CR0603F124 | GEN
6 | 2 | Chip Resistor 0603 10K 1% (MARKED 01C) | R14, R32 | CR0603F103 | GEN
7 | 1 | Chip Resistor 0603 4K7 1% | R33 | CR0603F472 | GEN
8 | 1 | Chip Resistor 1206 56R 1% | R29 | CR1206F560 | GEN
9 | 6 | Ceramic Chip Cap 0603 X7R 100nF 10% 50V | C1-3, C7, C8, C10 | CC0603X104K50 | GEN
10 | 5 | CERAMIC CHIP 0603 X5R 10UF 20% 6V3 | C9, C12, C13, C14, C15 | CC0603V106M6.3 | GEN
11 | 3 | CAP CER CHIP 0603 1UF X5R 10% 25V | C5, C6, C17 | CC0603V105K25 | GEN
12 | 1 | ALUMINIUM ELECTROLYTIC CAP CASE D 47UF 16V | C18 | EEE1CA470SP | PANA
13 | 1 | FERRITE BEAD, 0.04OHM, 3A, 0603 | L1 | MLB1608080030PQ | KITA
14 | 1 | Miniature USB Socket 5 Pin Female Smt | U$10 | USM5L1BK | DEEC
15 | 1 | 0805 1.85v Red LED Surface Mount 60mcd | LED 1 | TLHQR35XTRB | TRUO
16 | 1 | VOLT REG LDO 250MA SMD SOT-23-3 MCP1702T-3302E/CB | U$6 | MCP1702T3302ECB | MCHP
17 | 1 | LDO, 150MA, 3.3V, SOT89-3 (MU****) | U$11 | MCP1754ST3302EMB | MCHP
18 | 1 | DIODE, 100V,150MA, SOD323 (A2) *OBS* | D1 | 1N4148WSVGS08 | VISH
19 | 1 | CRYSTAL, 16MHZ, 18PF, HC49-US, SMD | Q1 | 9C-16.000MAAJ-T | TXC
20 | 5 | ESD PROTECTION DIODE, 3.3V, SOD-523-2 | D2-6 | ESD5Z3.3T1G | ONSE

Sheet: CON
Item | Qty Per | Stock Name | Manufacturer Part No. | Manufacturer Name | Board Locations
1 | 1 | TERMINAL BLOCK 3.5MM PITCH 6 WAY | XY35006 | XINY | J1, J2, J3, J5, J6
2 | 1 | DTSA-63K 5.85MM RIGHT ANGLE TACT SWITCH (78-1154) | DTSA63K | DIPT | S1
3 | 1 | PIN HEADER R/A 6 WAY SIL 2.54MM (1X6) | PH1106R11 | DEEC | JP1
4 | 1 | PIN HEADER STRAIGHT 2 WAY SIL 2.54MM | PH1102S11 | DEEC | JP2
5 | 1 | CONNECTOR 2W JUMPER LINK OPEN BLACK 2.54MM | MJ11 | DEEC | JP2
6 | 1 | PCB MTG POWER SKT 1A 12VDC 2.1MM (OBSOLETE) | 200970 | RAPI | CN1
7 | 4 | 3.5mm Switched Stereo Socket Black | STX3100 | RAPI | CT1, CT2, CT3
8 | 1 | PART TO BE FREE ISSUED BY END CUSTOMER | FREE ISSUED | DIA | 3 X AAA BATTERY HOLDER U$3
9 | 1 | DIP SMT SWITCH 2WAY WITH COVER TAPE | 161SL02O | XINY | S3
10 | 1 | COMPONENT NOT SUPPLIED BY DIAMOND | NOTDIAMONDSUPPLY | DIA | J$1
12 | 1 | PIN HEADER 3 x 2 (ISP header) 2.54mm |  |  | ISP1
13 | 1 | CONNECTOR 24-0465 FCC68 COMMS SKT 8/8 R/A | 240465 | RAPI | U$13
14 | 1 | MCU, 8BIT, AVR, 32K FLASH, 32TQFP | ATMEGA328PAU | ATME | U1
15 | 1 | SMA EDGE CONNECTOR 50 OHMS | FREE ISSUED | Farnell 1909303 | SMA

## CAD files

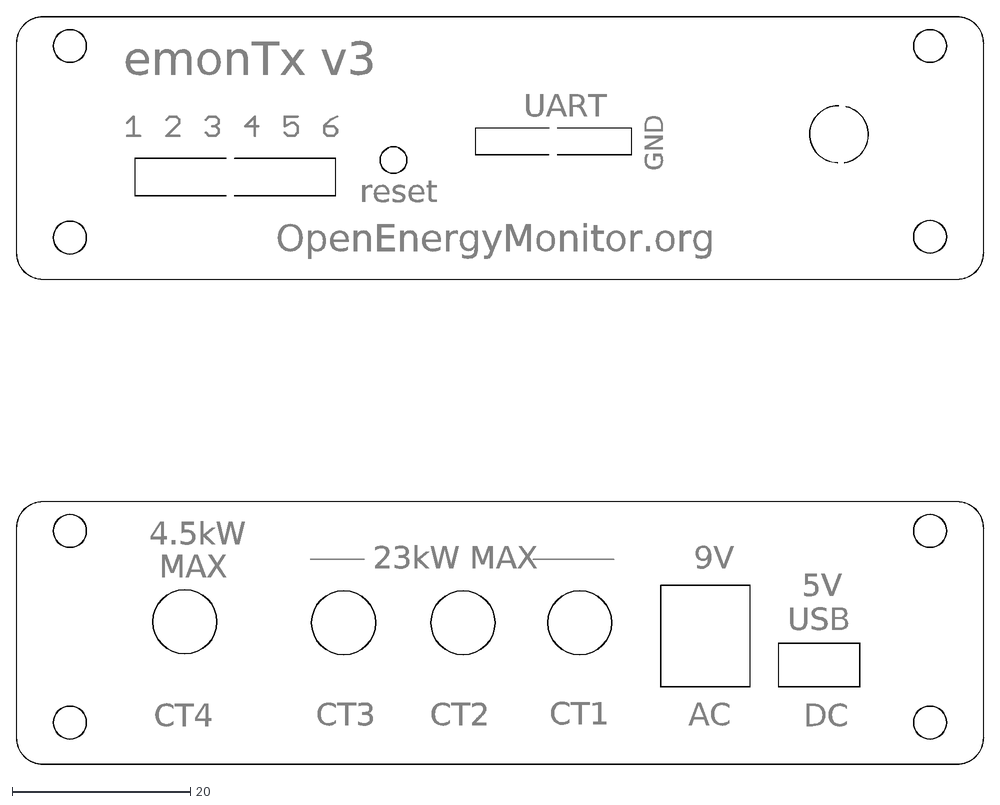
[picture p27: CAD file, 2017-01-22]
enclosure/fascia/fascia.dxf
AC
CT1
CT2
CT3
CT4
9V
reset
USB
4.5kW
23kW MAX
MAX
UART
OpenEnergyMonitor.org
emonTx v3
GND
DC
5V

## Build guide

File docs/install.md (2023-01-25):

# emonTx3 Install Guide

The following guide details how to install an [emonTx3 energy monitoring node](overview.md). Covering an example with 2x CT sensors to monitor two AC circuits in a house and an ACAC Voltage sensor to allow real power calculation as well as power for the emonTx unit itself. The emonTx supports up to 4x CT sensors so the steps below can easily be extended to monitor additional circuits. 

In this example the emonTx transmits AC power, voltage and temperature sensor measurements (if connected) every 10s via 433 MHz radio to the emonBase base-station. 

The emonBase base-station consists of a RaspberryPi and an RFM69Pi adapter board to receive the 433 MHz radio packets from the emonTx. The emonBase runs our emonSD software including emonCMS for full local data logging and visualisation capability.

- New 2019: The emonTx firmware now supports higher accuracy continuous monitoring as standard, power from an ACAC adapter or USB power is assumed.
- Alternative firmware options include: Discrete Sampling firmware - useful when only battery power is available; and 3-phase firmware.

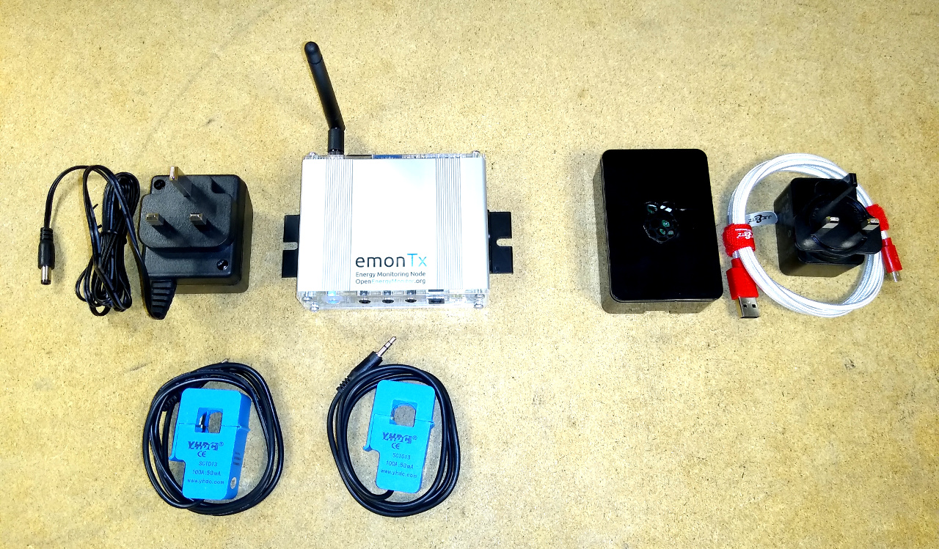
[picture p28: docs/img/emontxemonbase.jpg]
emontx and emonbase


A typical emonTx & emonBase system consists of:

- 1x [emonTx (includes antennae and wall mounts)](https://shop.openenergymonitor.com/emontx-v3-electricity-monitoring-transmitter/)
- 1-4x [100A CT sensors](https://shop.openenergymonitor.com/100a-max-clip-on-current-sensor-ct/)
- 1x [ACAC Voltage sensor](https://shop.openenergymonitor.com/ac-ac-power-supply-adapter-ac-voltage-sensor-uk-plug/)
- 1x [emonBase (RaspberryPi + RFM69Pi adapter board + Enclosure + emonSD card)](https://shop.openenergymonitor.com/emonbase-web-connected-base-station/)
- 1x [USB Power supply](https://shop.openenergymonitor.com/5v-dc-usb-power-adapter-uk-plug/) and [micro-USB cable](https://shop.openenergymonitor.com/micro-usb-cable-20-awg-emonbase/)

## Example emonTx sensor node installation

In this example installation the total house electricity consumption is measured using the CT sensor attached to the brown cable (main feed to the house). Another CT sensor is located inside the main consumer unit, in this case monitoring the electricity supply to a heat pump.

A dedicated socket was installed for the AC-AC Voltage sensor and combined power supply. 

A RFM69 433 MHz antennae is attached and also a DS18B20 temperature sensor connected to the emonTx RJ45 Temperature and Pulse input socket.

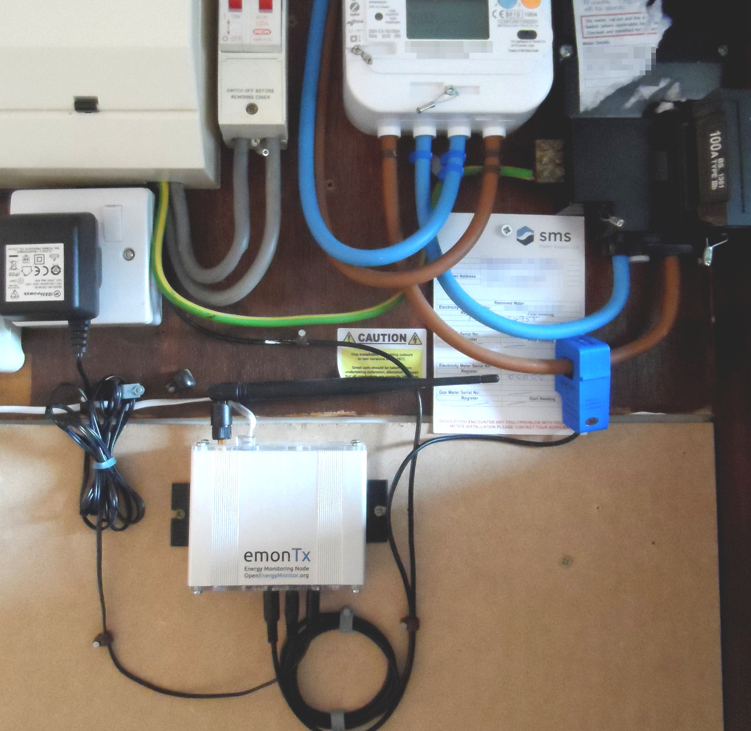
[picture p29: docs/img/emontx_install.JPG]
emontx install


The emonTx transmits real power, cumulative watt-hours, mains voltage and temperature measurements every 10s over RFM69 radio to an emonBase connected via Ethernet to the internet router in the living room.

## Installation overview

**emonTx**

1. Mount emonTx in desired location, use wall mounts if required, attach antennae.
2. Plug CT sensors into the emonTx first and then clip around either the **Line** or **Neutral** cable of the AC circuits that you wish to measure. If the power reading is negative, reverse the CT sensor orientation. [Please read the CT installation guide before installing](../electricity-monitoring/ct-sensors/installation.md).
3. Attach temperature sensors or/and pulse sensor as required. See guides: [+ Add Temperature Nodes](../emonth2/install.md) and [+ Add Optical Pulse Sensor](../emontx3/install.md).
    
3. Plug in and connect the AC-AC adapter to provide voltage measurement and power. This may require installation of a new outlet or extending an existing one.

**emonBase**

1. Connect Ethernet before powering up the emonBase if using Ethernet.
2. Plug in USB power supply and connect micro-USB cable.

That's the hardware setup done! The next step is to configure the network connection and setup the emonBase to log data locally or/and post data to a remote server such as emoncms.org. 

To setup the software continue to guides: 

- [1. Connect](../emonpi/connect.md)
- [2. Log Locally](../emoncms/intro-rpi.md)
- [3. Log Remotely](../emoncms/intro-remote.md)

For advanced emonTx configuration and alternative firmware options see:<br> [emonTx technical guide](../emontx3/technical.md).

## Temperature sensing

A DS18B20 digital temperature sensor can easily be connected to the emonTx V3 by connecting the sensor to the emonTx V3 screw terminal block or RJ45 connector.

The continuous Monitoring firmware (default) supports 3x temperature sensors. The Discrete Sampling firmware (used for battery operation) supports up to 6x temperature sensors.

A DS18B20 sensor can be connected directly to the RJ45 socket, or an RJ45 to terminal block breakout can be used to connect multiple sensors:

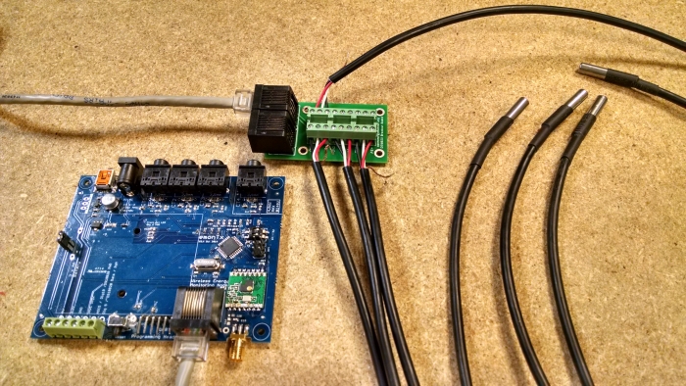
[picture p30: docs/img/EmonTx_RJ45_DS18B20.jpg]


*Note: The RJ45 socket does not support power supply switching via Dig19 (ADC5).*

- [Shop: Encapsulated DS18B20 temperature sensor](http://shop.openenergymonitor.com/encapsulated-ds18b20-temperature-sensor/)
- [Shop: emonPi / emonTx RJ45 to Terminal Block Breakout for DS18B20](https://shop.openenergymonitor.com/rj45-to-terminal-block-breakout-for-ds18b20/)
- Additional RJ45 breakouts are available from [Sheep Walk Electronics](http://www.sheepwalkelectronics.co.uk/index.php?cPath=23)

**RJ45 Pinout**<br>
The RJ45 implements a standard pinout used by other manufacturers of DS18B20 temperate sensing hardware such as Sheepwalk Electronics.

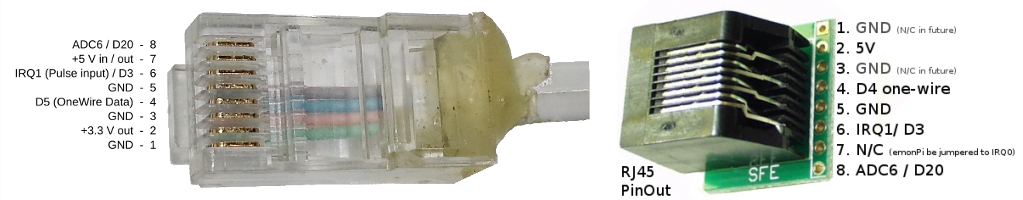
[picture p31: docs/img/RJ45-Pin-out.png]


*Note: The RJ45 socket does not support power supply switching via Dig19 (ADC5) as described above.*

**Terminal Block Connection**<br>
To connect an external DS18B20 to the emonTx V3 screw terminal block, connect the **black** wire to GND, **red** to 'ADC5 / Dig19 / DS18B20 PWR' and **white** to 'Dig 5 / DS18B20 Data / PWM':

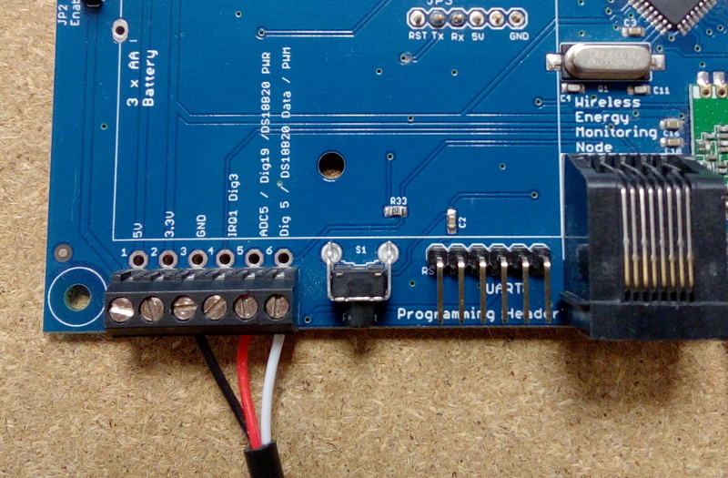
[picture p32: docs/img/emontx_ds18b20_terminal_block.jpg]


**EmonTx Power Supply**<br>
When using multiple temperature sensors and or an optical pulse sensor with the emonTx it is recommended to power the emonTx via a 5V USB rather than AC-AC adapter due to increased power requirement. An AC-AC adapter can still be used to provide an AC voltage reference. 

**EmonTx Low power battery mode**<br>
In order to save power when running on batteries, the emonTx V3 supports switching off of the DS18B20 in-between readings and performing the temperature conversion while the ATmega328 is sleeping. To do this, power (3.3 V) is supplied to the DS18B20's power pin from Dig19 (ADC5), this digital pin is switched off between readings. (This facility is available only if the temperature sensors are connected via the terminal block.) The data connection from the DS18B20 is connected to Dig5, this I/O pin has a 4K7 pull-up resistor on-board as required by the DS18B20. 

**Further reading**<br>
If you are using temperature sensors with heating systems such as heat pumps the following blog post by John Cantor provides a number of useful mounting suggestions: [John Cantor's Blog: Temperature sensors for monitoring heat pumps](https://heatpumps.co.uk/2015/06/08/temperature-sensing-with-openenergymonitor)

## Pulse counting

The emonTx supports the OpenEnergyMonitor optical pulse counter. The optical pulse counter plugs into the RJ45 socket on the EmonTx.

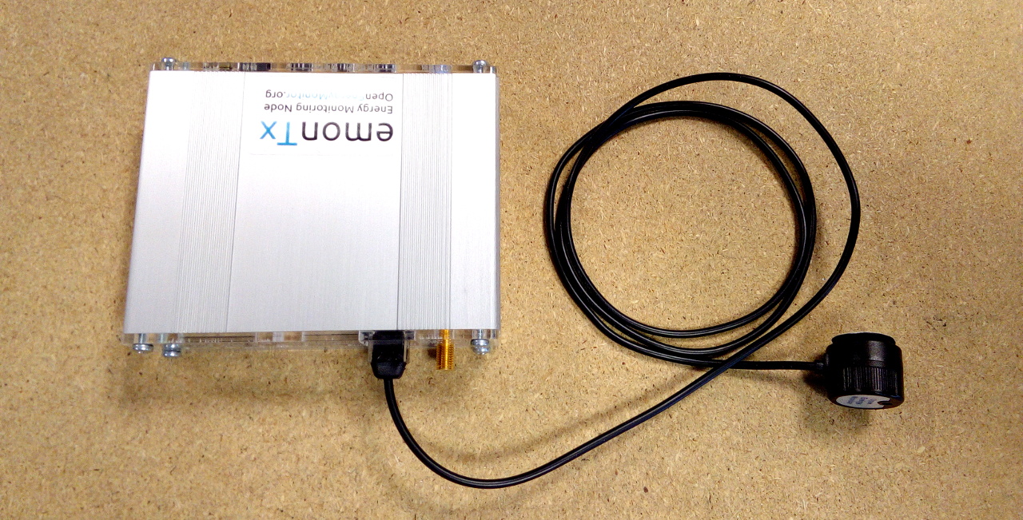
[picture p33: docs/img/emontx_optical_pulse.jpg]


Alternatively the terminal block can be used for wired pulse counting. Connect the pulse output to **IRQ1 Dig3** (4th along from left). 

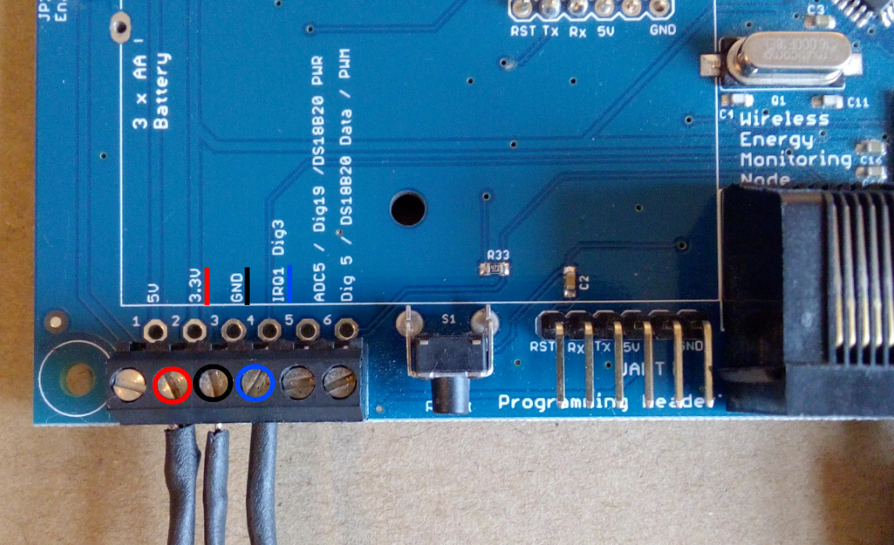
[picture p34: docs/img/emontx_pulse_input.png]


If you are using an optical counter attached to the terminal block, connect the power pin to the 3.3V terminal or 5V if the emonTx is powered via USB (2nd or 1st from the left) and connect ground to GND (3rd from the left).

For isolated volt-free / switch output (SO) pulse output devices, connect across IRQ1 Dig3 and GND. There is an internal pull-up resistor on the pulse input that is enabled in the standard firmware that will pull the signal up when the switched output is open.

In the face of long leads and/or moderate interference, it is advisable to “stiffen” the relatively weak internal pull-up with a parallel 10 kΩ (or possibly less if necessary) resistor wired between the pulse input and the 3.3 V supply.

Alternatively a volt-free / switch output (SO) pulse output device can be connected across 3.3V (or 5V) and IRQ1 Dig3. A pull-down resistor of resistance low enough to overcome the internal pull-up resistor needs to be added in this case, or a higher-value resistor with the firmware modified to disable the internal pull-up.

We recommend powering the emonTx v3 from either a 5V USB or AC-AC adaptor when used for pulse counting operation. Due to the additional power requirements of the optical pulse sensor, battery life will be reduced significantly compared to an emonTx powered by 3 AA batteries for CT operation only. 

**Emoncms input processing**<br>Pulses and the most recent pulse count are transmitted via RF, as the final variable in the JeeLib packet structure. The emonCMS wh_accumulator input process can be used to log the pulse count. The wh_accumulator input process detects when the pulse count gets reset to zero (after the emonTx is reset) and continues to accumulate, ignoring the reset. A scaler input process can be used to convert number of pulses to kWh. For example: my utility meter outputs 800 pulses per kWh, so each pulse is 0.8Wh. I can multiply the number of pulses by 0.8 to get the number of Wh, or by 0.0008 for the number of kWh accumulated.

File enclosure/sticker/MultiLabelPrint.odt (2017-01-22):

emonTxV3

ENERGY MONITORING NODE

openenergymonitor.org

emonTxV3

ENERGY MONITORING NODE

openenergymonitor.org

emonTxV3

ENERGY MONITORING NODE

openenergymonitor.org

emonTxV3

ENERGY MONITORING NODE

openenergymonitor.org

emonTxV3

ENERGY MONITORING NODE

openenergymonitor.org

emonTxV3

ENERGY MONITORING NODE

openenergymonitor.org

emonTxV3

ENERGY MONITORING NODE

openenergymonitor.org

emonTxV3

ENERGY MONITORING NODE

openenergymonitor.org

emonTxV3

ENERGY MONITORING NODE

openenergymonitor.org

emonTxV3

ENERGY MONITORING NODE

openenergymonitor.org

emonTxV3

ENERGY MONITORING NODE

openenergymonitor.org

emonTxV3

ENERGY MONITORING NODE

openenergymonitor.org

emonTxV3

ENERGY MONITORING NODE

openenergymonitor.org

emonTxV3

ENERGY MONITORING NODE

openenergymonitor.org

emonTxV3

ENERGY MONITORING NODE

openenergymonitor.org

emonTxV3

ENERGY MONITORING NODE

openenergymonitor.org

emonTxV3

ENERGY MONITORING NODE

openenergymonitor.org

emonTxV3

ENERGY MONITORING NODE

openenergymonitor.org

emonTxV3

ENERGY MONITORING NODE

openenergymonitor.org

emonTxV3

ENERGY MONITORING NODE

openenergymonitor.org

emonTxV3

ENERGY MONITORING NODE

openenergymonitor.org

emonTxV3

ENERGY MONITORING NODE

openenergymonitor.org

emonTxV3

ENERGY MONITORING NODE

openenergymonitor.org

emonTxV3

ENERGY MONITORING NODE

openenergymonitor.org

emonTxV3

ENERGY MONITORING NODE

openenergymonitor.org

emonTxV3

ENERGY MONITORING NODE

openenergymonitor.org

emonTxV3

ENERGY MONITORING NODE

openenergymonitor.org

emonTxV3

ENERGY MONITORING NODE

openenergymonitor.org

emonTxV3

ENERGY MONITORING NODE

openenergymonitor.org

emonTxV3

ENERGY MONITORING NODE

openenergymonitor.org

emonTxV3

ENERGY MONITORING NODE

openenergymonitor.org

emonTxV3

ENERGY MONITORING NODE

openenergymonitor.org

emonTxV3

ENERGY MONITORING NODE

openenergymonitor.org

emonTxV3

ENERGY MONITORING NODE

openenergymonitor.org

emonTxV3

ENERGY MONITORING NODE

openenergymonitor.org

emonTxV3

ENERGY MONITORING NODE

openenergymonitor.org

emonTxV3

ENERGY MONITORING NODE

openenergymonitor.org

emonTxV3

ENERGY MONITORING NODE

openenergymonitor.org

emonTH

TEMPERATURE & HUMIDITY

openenergymonitor.org

emonTH

TEMPERATURE & HUMIDITY

openenergymonitor.org

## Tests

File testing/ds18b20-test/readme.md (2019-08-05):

## emonTx V3 DS18B20 Tester

Testing sketch for DS18B20 connected to emonTx V3. LED will light up if sensor is detected and reading is within limits.

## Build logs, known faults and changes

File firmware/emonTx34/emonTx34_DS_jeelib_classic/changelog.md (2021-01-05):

## emonTx V3.4 firmware change log:

- V3.4   05/01/21 Slow down DS18B20 conversion - required for new batch of RJ45 temp sensors 
- V3.3   05/12/19 Fix RFM factory test
- V3.2   27/08/19 Add watchdog reset
- V3.1   25/05/18 Prompt to set 'Both CR & NL' on serial monitor.
- V3.0   16/01/18 Return zero reading when CT is disconnected and always sample from all CT's when powered by AC-AC (negate CT's required plugged in before startup)
- v2.9   30/03/17 Correct RMS voltage calc at startup when USA mode is enabled
- v2.8   27/02/17 Correct USA voltage to 120V
- v2.7   34/02/17 Fix USA apparent power readings (assuming 110VRMS when no AC-AC voltage sample adapter is present). Fix DIP switch nodeID config incorrect serial print if node ID has been set via EEPROM serial config and DIP switch.
- v2.6   31/10/16 Add RF config via serial & save to EEPROM feature. Allows RF settings (nodeID, freq, group) via serial
- v2.5   19/09/16 Increase baud 9600 > 115200 to emonesp compatibility
- v2.4   06/09/16 Update serial output to use CSV string pairs to work with emonESP e.g. 'ct1:100,ct2:329'
- v2.3   16/11/15 Change to unsigned long for pulse count and make default node ID 8 to avoid emonHub node decoder conflict & fix counting pulses faster than 110ms, strobed meter LED http://openenergymonitor.org/emon/node/11490
- v2.2   12/11/15 Remove debug timing serial print code
- v2.1   24/10/15 Improved timing so that packets are sent just under 10s, reducing resulting data gaps in feeds + default status code for no temp sensors of 3000 which reduces corrupt packets improving data reliability
- V2.0   30/09/15 Update number of samples 1480 > 1662 to improve sampling accurancy: 1662 samples take 300 mS, which equates to 15 cycles @ 50 Hz or 18 cycles @ 60 Hz.
- V1.9   25/08/15 Fix spurious pulse readings from RJ45 port when DS18B20 but no pulse counter is connected (enable internal pull-up)
- V1.8 - 18/06/15 Increase max pulse width to 110ms
- V1.7 - 12/06/15 Fix pulse count denounce issue & enable pulse count pulse temperature
- V1.6 - Add support for multiple DS18B20 temperature sensors
- V1.5 - Add interrupt pulse counting - simplify serial print debug
- V1.4.1 - Remove filter settle routine as latest emonLib 19/01/15 does not require
- V1.4 - Support for RFM69CW, DIP switches and battery voltage reading on emonTx V3.4
- V1.3 - fix filter settle time to eliminate large initial reading
- V1.2 - fix bug which caused Vrms to be returned as zero if CT1 was not connected
- V1.1 - fix bug in startup Vrms calculation, startup Vrms startup calculation is now more accurate

`emonhub.conf` node decoder (nodeid is 8 when switch is off, 7 when switch is on)
See: https://github.com/openenergymonitor/emonhub/blob/emon-pi/configuration.md

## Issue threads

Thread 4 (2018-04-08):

Vrms values, power supply

ArashiCZ, 2018-04-08:
Hello,

My emonTX3 with emonESP measures 260 Vrms AC.
I live in Czech republic, therefor grig voltages are  230V AC 1 phase and 400V AC 3 phase.

My expensive True RMS multimmeter measures 232,6 V AC.
I'm using 9V AC-AC Europe adapter, that I boughtt with the device.

Could it be caused by I'm having to use second power supply, beacuse the EmonESP doesn't work with 9V AC adaptor only?

Thank you.

glynhudson, 2018-04-08:
Hi,

You you need to calibrate for the specific AC-AC voltage adaptor you are using. The error is not caused by the two power supplies. You should ensure jumper JP2 is removed when using the two power supplies. See calibration procedure: https://learn.openenergymonitor.org/electricity-monitoring/ctac/calibration

You need to edit `Vcal`:

https://github.com/openenergymonitor/emontx3/blob/master/firmware/src/src.ino#L98

Closed 2018-04-08.

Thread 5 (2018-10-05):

Baud rate wrong in config

jodli, 2018-10-05:
Hi!

Since v2.5 of the emontx3 firmware the baud rate is upped to 115200 but the PIO monitor baud rate is still 9600 for this board.
So monitoring via serial port is not possible.

I'm opening a PR soon that fixes this. 🎊

Best regards
jodli

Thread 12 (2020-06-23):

Question: Board 3.4.4 IC2 7805

stuartpittaway, 2020-06-23:
On the board schematic IC2 is a 7805 regulator, should that still be on the design?  Its overlapping with a 3.3V regulator.

glynhudson, 2020-06-23:
It's not used, it's just there to provide pads for test points

Closed 2020-06-23.

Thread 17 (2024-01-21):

Serial output undocumented

dwmw2, 2024-01-21:
I see serial output (from an RF12B but ISTR that I get something almost identical from the unit itself) looking something like this:
```
OK 8 146 21 11 0 28 0 0 0 65 93 184 11 184 11 184 11 184 11 184 11 184 11 0 0 0 0 (-69)
```

I'm fairly sure this used to be documented, but it seems to be unmentioned in the current documentation.

dwmw2, 2024-01-22:
Update: I managed to work it out using my own code at https://github.com/merbanan/rtl_433/blob/master/src/devices/emontx.c#L116

Would still be good if this was easier to find in the documentation.

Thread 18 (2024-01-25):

pulses not working

useless2u, 2024-01-25:
For V3 board these are wrong

#define PULSEINT 1                               // Interrupt no. for pulse counting: EmonTx V2 = 0, EmonTx V3 = 1, EmonTx Shield - see Wiki
#define PULSEPIN 3                               // Interrupt input pin: EmonTx V2 = 2, EmonTx V3 = 3, EmonTx Shield - see Wiki

PULSEINT is 0
PULSEPIN is 2
( says so on the board )
At least for me it's working now

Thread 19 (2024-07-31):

Apparent bug in calibration channels

montgomeryb, 2024-07-31:
I pulled the latest code and had difficulty in calibrating my tx3 for my US system. On investigating the various libraries I believe the calibration code is using the wrong channels. I changed it locally and it seems to be working now as I expected it to.

In `emonTx34_CM.ino` it has:

        EmonLibCM_SetADC_IChannel(1, EEProm.i1Cal, EEProm.i1Lead);           // ADC Input channel, current calibration, phase calibration
        EmonLibCM_SetADC_IChannel(2, EEProm.i2Cal, EEProm.i2Lead);           // The current channels will be read in this order
        EmonLibCM_SetADC_IChannel(3, EEProm.i3Cal, EEProm.i3Lead);           // 90.91 for 100 A : 50 mA c.t. with 22R burden - v.t. leads c.t by ~4.2 degrees
        EmonLibCM_SetADC_IChannel(4, EEProm.i4Cal, EEProm.i4Lead);           // 16.67 for 100 A : 50 mA c.t. with 120R burden - v.t. leads c.t by ~1 degree

In `emonTx34_CM_config.ino` though it has:

        case 1 : EmonLibCM_ReCalibrate_IChannel(3, k2, k3);
          EEProm.i1Cal = k2;
          EEProm.i1Lead = k3;
          break;

        case 2 : EmonLibCM_ReCalibrate_IChannel(4, k2, k3);
          EEProm.i2Cal = k2;
          EEProm.i2Lead = k3;
          break;

        case 3 : EmonLibCM_ReCalibrate_IChannel(5, k2, k3);
          EEProm.i3Cal = k2;
          EEProm.i3Lead = k3;
          break;

        case 4 : EmonLibCM_ReCalibrate_IChannel(6, k2, k3);
          EEProm.i4Cal = k2;
          EEProm.i4Lead = k3;
          break;

I changed the first parameters in the switch to 1 through 4.

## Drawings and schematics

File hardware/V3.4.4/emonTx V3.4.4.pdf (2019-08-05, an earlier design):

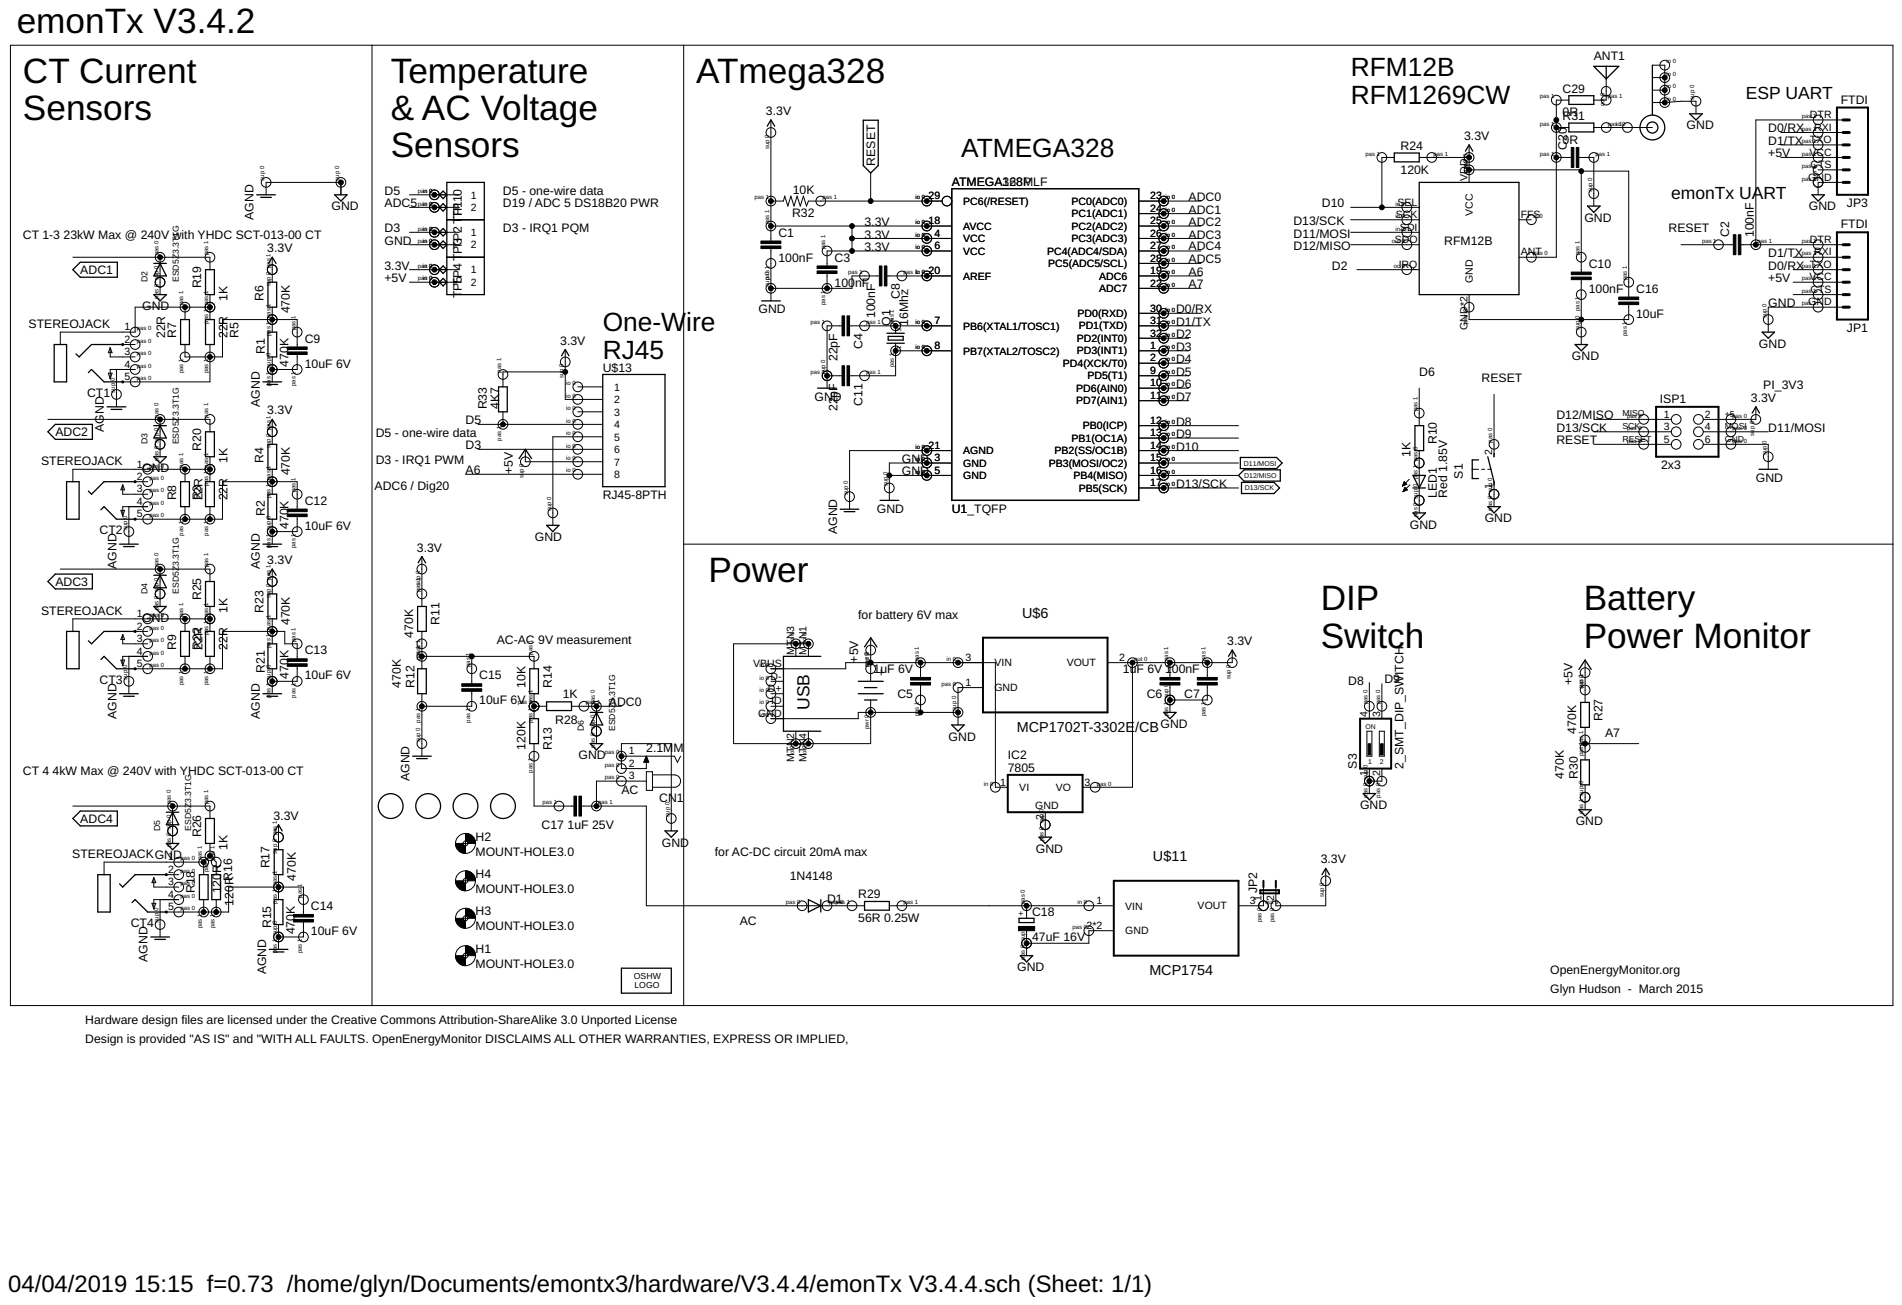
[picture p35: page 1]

CT 1-3 23kW Max @ 240V with YHDC SCT-013-00 CT

pas 0 pas 0 pas 0

pas 1 pas 1 pas 1 pas 1

pas 1 pas 1 pas 1

AGND AGND

pas 1 pas 1

CT 4 4kW Max @ 240V with YHDC SCT-013-00 CT

for AC-DC circuit 20mA max

OpenEnergyMonitor.org Glyn Hudson - March 2015

Design is provided "AS IS" and "WITH ALL FAULTS. OpenEnergyMonitor DISCLAIMS ALL OTHER WARRANTIES, EXPRESS OR IMPLIED, Hardware design files are licensed under the Creative Commons Attribution-ShareAlike 3.0 Unported License

04/04/2019 15:15 f=0.73 /home/glyn/Documents/emontx3/hardware/V3.4.4/emonTx V3.4.4.sch (Sheet: 1/1)

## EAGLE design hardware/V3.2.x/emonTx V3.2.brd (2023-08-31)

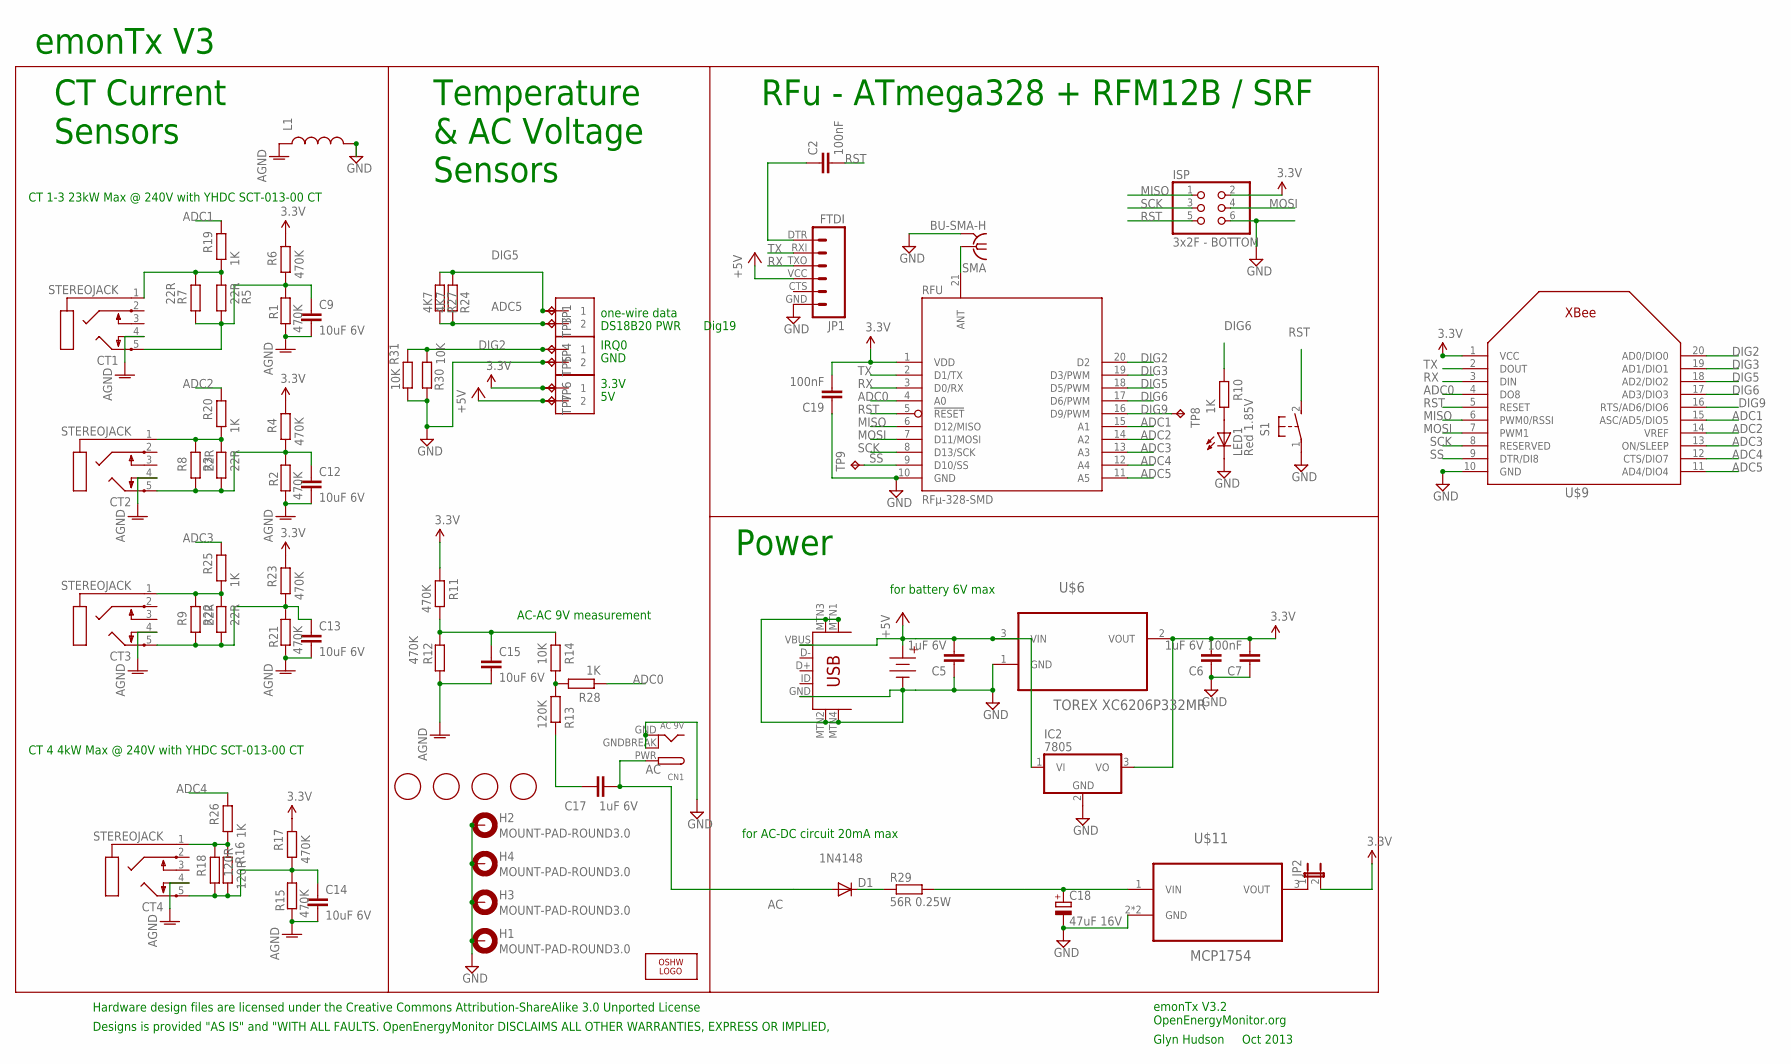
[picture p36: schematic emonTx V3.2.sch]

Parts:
C2, C7, C19: 100nF; C0603
C5, C6, C17: 1uF 6V; C0603
C9, C12, C13, C14, C15: 10uF 6V; C0603
C18: 47uF 16V; PANASONIC_D
CN1: AC 9V; DCJACK_2MM_PTH
CT1, CT2, CT3, CT4: STEREOJACK; STX3100
D1: 1N4148; SOD-323
H1, H2, H3, H4: MOUNT-PAD-ROUND3.0; 3,0-PAD
IC2: 7805; TO220V
ISP: 3x2F - BOTTOM; 2X03
J1, J2, J4: 1X2-3.5MM
JP1: FTDI; FTDI_BASIC
JP2: JUMPER-2PTH_LOCK; 1X02_LOCK
L1: INDUCTOR0603; 0603
LED1: Red 1.85V; CHIP-LED0805
LOGO1: OSHW_LOGO_6MILX0200-NT; OSHW_6X200_NOTEXT
R1, R2, R4, R6, R11, R12, R15, R17, R21, R23: 470K; R0603
R3, R5, R22: 22R; 0204/7
R7, R8, R9: 22R; R1206
R10, R19, R20, R25, R26, R28: 1K; R0603
R13: 120K; R0603
R14, R31: 10K; R0603
R16: 120R; 0204/7
R18: 120R; R1206
R24: 4K7; 0204/7
R27: 4K7; R0603
R29: 56R 0.25W; R1206
R30: 10K; 0204/7
RFU: RFµ-328-SMD; RFµ-328-LANDING
S1: 31-XX; B3F-31XX
SMA: BU-SMA-H
TP1, TP3, TP4, TP5, TP6, TP7, TP8, TP9: TPPAD1-13; P1-13
U$1, U$4, U$5, U$7: FIDUCIAL; FIDUCIAL_1MM
U$3: 4.5V; AAA_PCB_HOLDER
U$6: TOREX XC6206P332MR; SOT95P237X112-3N
U$9: XBEE
U$10: USB-MINIB-5PIN; USB-MINIB-CISECO
U$11: MCP1754; SOT89

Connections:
3.3V: C6.2, C7.2, C19.2, IC2.3 (VO), ISP.2, J4.1, JP2.2, R4.2, R6.2, R11.2, R17.2, R23.2, RFU.1 (VDD), TP6.TP, U$6.2 (VOUT), U$9.1 (VCC)
+5V: C5.2, IC2.1 (VI), J4.2, JP1.VCC (4), TP7.TP, U$3.+, U$6.3 (VIN), U$10.VBUS
AC: C17.2, CN1.PWR, D1.2 (A)
ADC0: R28.1, RFU.4 (A0), U$9.4 (DO8)
ADC1: R19.2, RFU.15 (A1), U$9.15 (ASC/AD5/DIO5)
ADC2: R20.2, RFU.14 (A2), U$9.14 (VREF)
ADC3: R25.2, RFU.13 (A3), U$9.13 (ON/SLEEP)
ADC4: R26.2, RFU.12 (A4), U$9.12 (CTS/DIO7)
ADC5: J2.2, R24.2, R27.2, RFU.11 (A5), TP3.TP, U$9.11 (AD4/DIO4)
AGND: C9.2, C12.2, C13.2, C14.2, C15.2, CT1.4, CT2.4, CT3.4, CT4.4, L1.1, R1.2, R2.2, R12.1, R15.2, R21.2
DIG2: J1.1, R30.1, R31.1, RFU.20 (D2), TP4.TP, U$9.20 (AD0/DIO0)
DIG3: RFU.19 (D3/PWM), U$9.19 (AD1/DIO1)
DIG5: J2.1, R24.1, R27.1, RFU.18 (D5/PWM), TP1.TP, U$9.18 (AD2/DIO2)
DIG6: R10.2, RFU.17 (D6/PWM), U$9.17 (AD3/DIO3)
DIG9: RFU.16 (D9/PWM), TP8.TP, U$9.16 (RTS/AD6/DIO6)
GND: C5.1, C6.1, C7.1, C18.-, C19.1, CN1.GND, CN1.GNDBREAK, H1.B3,0, H2.B3,0, H3.B3,0, H4.B3,0, IC2.2 (GND), ISP.6, J1.2, JP1.GND (6), L1.2, LED1.C, R30.2, R31.2, RFU.10 (GND), S1.1, SMA.2, SMA.3 (2), SMA.4 (2), SMA.5 (2), TP5.TP, U$3.-, U$6.1 (GND), U$9.10 (GND), U$10.GND, U$10.MTN1 (MTN2), U$10.MTN2 (MTN3), U$10.MTN3 (MTN1), U$10.MTN4, U$11.2 (GND), U$11.2.1 (GND)
MISO: ISP.1, RFU.6 (D12/MISO), U$9.6 (PWM0/RSSI)
MOSI: ISP.4, RFU.7 (D11/MOSI), U$9.7 (PWM1)
unnamed: CT1.1, R5.2, R7.2, R19.1
unnamed: C13.1, CT3.5, R9.1, R21.1, R22.1, R23.1
unnamed: R13.2, R14.1, R28.2
unnamed: JP2.1, U$11.3 (VOUT)
unnamed: C18.+, R29.2, U$11.1 (VIN)
unnamed: C17.1, R13.1
unnamed: CT4.1, R16.2, R18.2, R26.1
unnamed: C2.1, JP1.DTR (1)
unnamed: CT2.1, R3.2, R8.2, R20.1
unnamed: RFU.21 (ANT), SMA.1
unnamed: D1.1 (C), R29.1
unnamed: CT3.1, R9.2, R22.2, R25.1
unnamed: C12.1, CT2.5, R2.1, R3.1, R4.1, R8.1
unnamed: C15.1, R11.1, R12.2, R14.2
unnamed: C14.1, CT4.5, R15.1, R16.1, R17.1, R18.1
unnamed: C9.1, CT1.5, R1.1, R5.1, R6.1, R7.1
unnamed: LED1.A, R10.1
RST: C2.2, ISP.5, RFU.5 (!RESET), S1.2 (S), U$9.5 (RESET)
RX: JP1.TXO (3), RFU.3 (D0/RX), U$9.3 (DIN)
SCK: ISP.3, RFU.8 (D13/SCK), U$9.8 (RESERVED)
SS: RFU.9 (D10/SS), TP9.TP, U$9.9 (DTR/DI8)
TX: JP1.RXI (2), RFU.2 (D1/TX), U$9.2 (DOUT)

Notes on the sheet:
AC-AC 9V measurement
emonTx V3.2 OpenEnergyMonitor.org
Glyn Hudson Oct 2013
CT 4 4kW Max @ 240V with YHDC SCT-013-00 CT
CT 1-3 23kW Max @ 240V with YHDC SCT-013-00 CT
for battery 6V max
for AC-DC circuit 20mA max
Dig19
Power
RFu - ATmega328 + RFM12B / SRF
CT Current Sensors
Temperature & AC Voltage Sensors
Designs is provided "AS IS" and "WITH ALL FAULTS. OpenEnergyMonitor DISCLAIMS ALL OTHER WARRANTIES, EXPRESS OR IMPLIED,
Hardware design files are licensed under the Creative Commons Attribution-ShareAlike 3.0 Unported License
emonTx V3
DS18B20 PWR
one-wire data
IRQ0
GND
3.3V

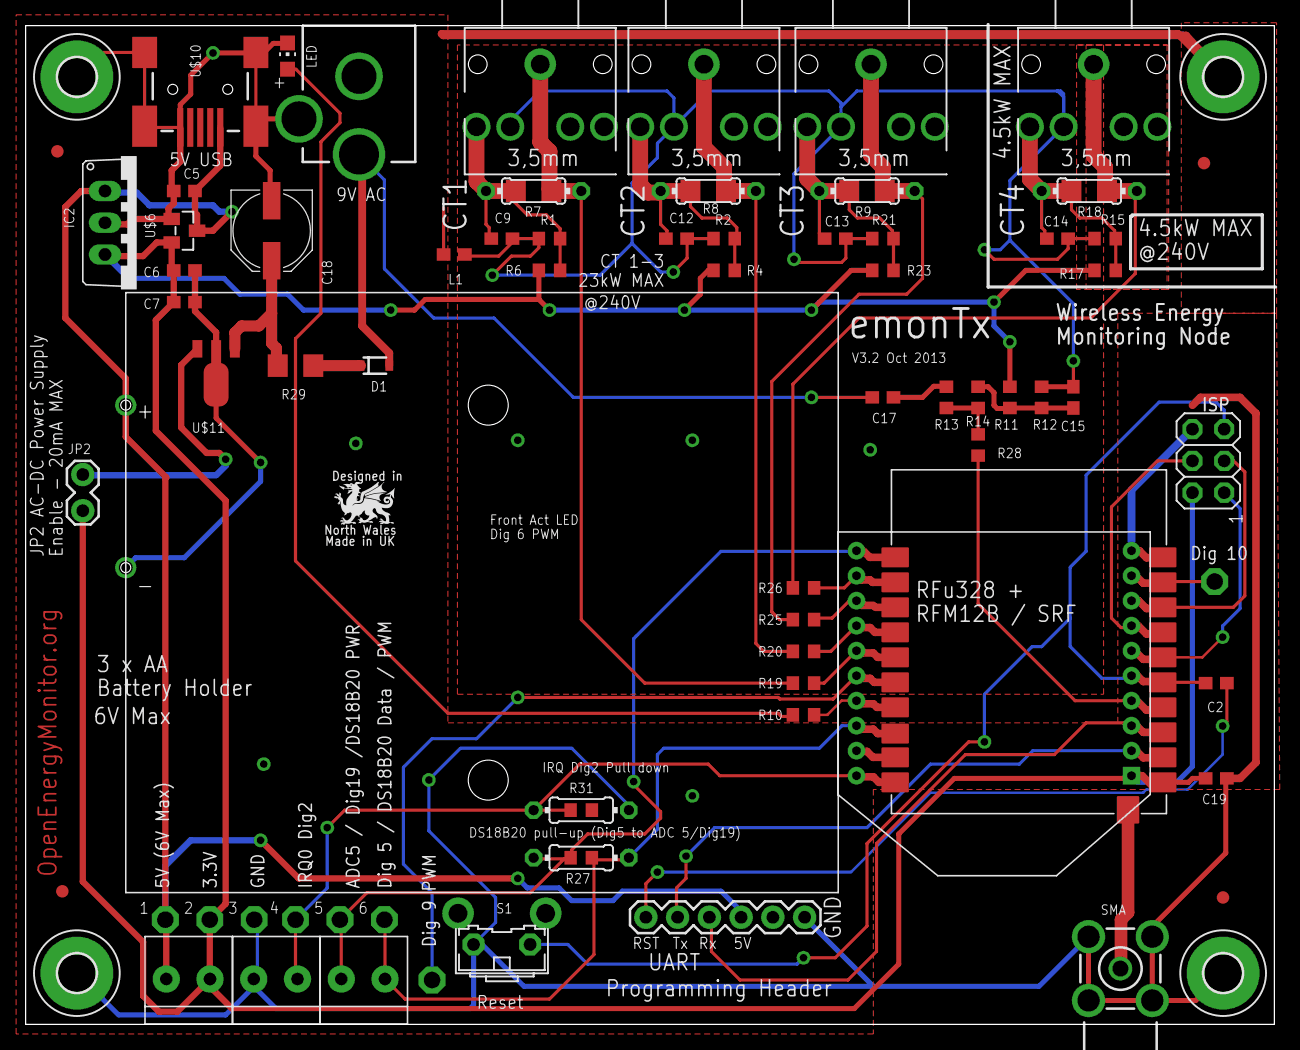
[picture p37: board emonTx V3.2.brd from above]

Board: 2 copper layers, 99.9 x 79.9 mm, 83 parts (1 on the bottom side), 40 nets.

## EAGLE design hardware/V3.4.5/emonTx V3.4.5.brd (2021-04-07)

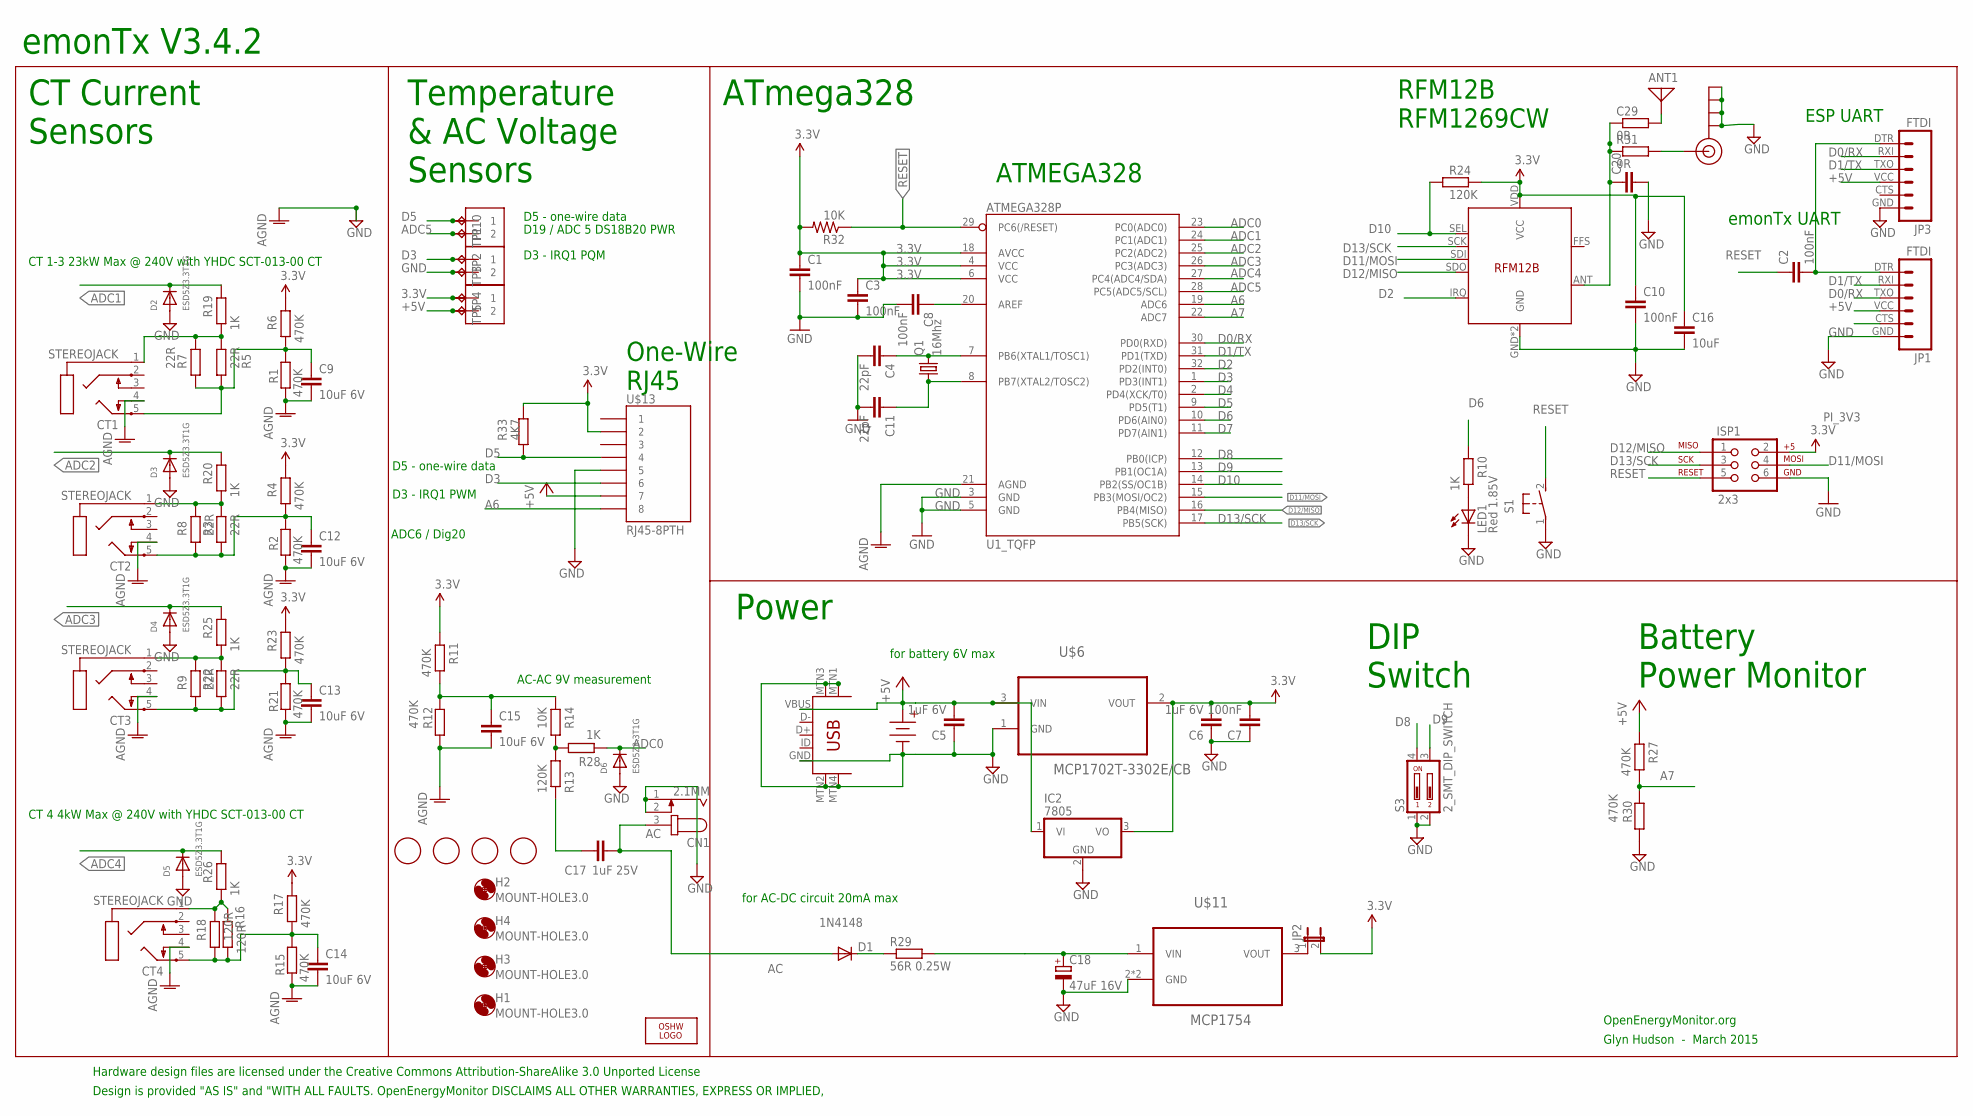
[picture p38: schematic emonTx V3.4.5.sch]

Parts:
ANT1: ANTENNA; PAD-01
C1, C2, C3, C7, C8, C10: 100nF; C0603
C4, C11: 22pF; C0603
C5, C6: 1uF 6V; C0603
C9, C12, C13, C14, C15: 10uF 6V; C0603
C16: 10uF; C0603
C17: 1uF 25V; C0603
C18: 47uF 16V; PANASONIC_D
C20: ant tune?; C0603
C29: 0R; R0603
CN1: 2.1MM; SPC4077
CT1, CT2, CT3, CT4: STEREOJACK; STX3100
D1: 1N4148; SOD-323
D2, D3, D4, D5, D6: ESD5Z3.3T1G; SOD-523
H1, H2, H3, H4: MOUNT-HOLE3.0; 3,0
IC2: 7805; TO220V
ISP1: 2x3; 2X3
J3, J5, J6: 1X2-3.5MM
J$1: SMA_EDGE; SMA-EDGE
JP1, JP3: FTDI; FTDI_BASIC
JP2: JUMPER-2PTH_LOCK; 1X02_LOCK
LED1: Red 1.85V; CHIP-LED0805
LOGO1: OSHW_LOGO_6MILX0200-NT; OSHW_6X200_NOTEXT
Q1: 16Mhz; HC49UP
R1, R2, R4, R6, R11, R12, R15, R17, R21, R23, R27, R30: 470K; R0603
R3, R5, R22: 22R; 0204/7
R7, R8, R9: 22R; R1206
R10, R19, R20, R25, R26, R28: 1K; R0603
R13, R24: 120K; R0603
R14, R32: 10K; R0603
R16: 120R; 0204/7
R18: 120R; R1206
R29: 56R 0.25W; R1206
R31: 0R; R0603
R33: 4K7; R0603
S1: 31-XX; B3F-31XX
S3: 2_SMT_DIP_SWITCH; DIP_SWITCH_SMT
TP1, TP2, TP3, TP4, TP5, TP10: TPPAD1-13; P1-13
U1_TQFP: ATMEGA328P; TQFP32-08
U$1, U$4, U$5, U$7: FIDUCIAL; FIDUCIAL_1MM
U$3: 4.5V; AAA_PCB_HOLDER
U$6: MCP1702T-3302E/CB; SOT95P237X112-3N
U$10: USB-MINIB-5PIN; USB-MINIB-CISECO
U$11: MCP1754; SOT89
U$13: RJ45-8PTH; RJ45-8
U$14: RFM12B

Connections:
3.3V: C1.1, C3.1, C6.2, C7.2, C10.1, C16.1, IC2.3 (VO), ISP1.2, J6.1, JP2.2, R4.2, R6.2, R11.2, R17.2, R23.2, R24.2, R32.2, R33.1, TP4.TP, U1_TQFP.4 (VCC), U1_TQFP.6 (VCC), U1_TQFP.18 (AVCC), U$6.2 (VOUT), U$13.2, U$14.VDD (VCC)
+5V: C5.2, IC2.1 (VI), J6.2, JP1.VCC (4), JP3.VCC (4), R27.2, TP5.TP, U$3.+, U$6.3 (VIN), U$10.VBUS, U$13.7
A6: U1_TQFP.19 (ADC6), U$13.8
A7: R27.1, R30.2, U1_TQFP.22 (ADC7)
AC: C17.2, CN1.3, D1.2 (A)
ADC0: D6.K (C), R28.1, U1_TQFP.23 (PC0(ADC0))
ADC1: D2.K (C), R19.2, U1_TQFP.24 (PC1(ADC1))
ADC2: D3.K (C), R20.2, U1_TQFP.25 (PC2(ADC2))
ADC3: D4.K (C), R25.2, U1_TQFP.26 (PC3(ADC3))
ADC4: D5.K (C), R26.2, U1_TQFP.27 (PC4(ADC4/SDA))
ADC5: J3.2, TP1.TP, U1_TQFP.28 (PC5(ADC5/SCL))
AGND: C9.2, C12.2, C13.2, C14.2, C15.2, CT1.4, CT2.4, CT3.4, CT4.4, R1.2, R2.2, R12.1, R15.2, R21.2, U1_TQFP.21 (AGND)
D0/RX: JP1.TXO (3), JP3.RXI (2), U1_TQFP.30 (PD0(RXD))
D1/TX: JP1.RXI (2), JP3.TXO (3), U1_TQFP.31 (PD1(TXD))
D2: U1_TQFP.32 (PD2(INT0)), U$14.IRQ
D3: J5.1, TP2.TP, U1_TQFP.1 (PD3(INT1)), U$13.6
D4: U1_TQFP.2 (PD4(XCK/T0))
D5: J3.1, R33.2, TP10.TP, U1_TQFP.9 (PD5(T1)), U$13.4
D6: R10.2, U1_TQFP.10 (PD6(AIN0))
D7: U1_TQFP.11 (PD7(AIN1))
D8: S3.4, U1_TQFP.12 (PB0(ICP))
D9: S3.3, U1_TQFP.13 (PB1(OC1A))
D10: R24.1, U1_TQFP.14 (PB2(SS/OC1B)), U$14.SEL
D11/MOSI: ISP1.4, U1_TQFP.15 (PB3(MOSI/OC2)), U$14.SDI
D12/MISO: ISP1.1, U1_TQFP.16 (PB4(MISO)), U$14.SDO
D13/SCK: ISP1.3, U1_TQFP.17 (PB5(SCK)), U$14.SCK
DIG1: C20.1, C29.1, R31.1, U$14.ANT
GND: C1.2, C3.2, C4.2, C5.1, C6.1, C7.1, C8.2, C10.2, C11.2, C16.2, C18.-, C20.2, CN1.1, CN1.2, D2.A, D3.A, D4.A, D5.A, D6.A, IC2.2 (GND), ISP1.6, J5.2, J$1.GND@0 (GND), J$1.GND@1 (GND), J$1.GND@2 (GND), J$1.GND@3 (GND), JP1.GND (6), JP3.GND (6), LED1.C, R30.1, S1.1, S3.1, S3.2, TP3.TP, U1_TQFP.3 (GND), U1_TQFP.5 (GND), U$3.-, U$6.1 (GND), U$10.GND, U$10.MTN1 (MTN2), U$10.MTN2 (MTN3), U$10.MTN3 (MTN1), U$10.MTN4, U$11.2 (GND), U$11.2.1 (GND), U$13.5, U$14.GND, U$14.P$12 (GND)
unnamed: C4.1, Q1.2, U1_TQFP.7 (PB6(XTAL1/TOSC1))
unnamed: CT1.1, R5.2, R7.2, R19.1
unnamed: C13.1, CT3.5, R9.1, R21.1, R22.1, R23.1
unnamed: R13.2, R14.1, R28.2
unnamed: JP2.1, U$11.3 (VOUT)
unnamed: C18.+, R29.2, U$11.1 (VIN)
unnamed: C17.1, R13.1
unnamed: CT4.1, R16.2, R18.2, R26.1
unnamed: C11.1, Q1.1, U1_TQFP.8 (PB7(XTAL2/TOSC2))
unnamed: CT2.1, R3.2, R8.2, R20.1
unnamed: ANT1.1, C29.2
unnamed: D1.1 (C), R29.1
unnamed: CT3.1, R9.2, R22.2, R25.1
unnamed: C8.1, U1_TQFP.20 (AREF)
unnamed: C2.2, JP1.DTR (1), JP3.DTR (1)
unnamed: J$1.SIG (SIGNAL), R31.2
unnamed: C12.1, CT2.5, R2.1, R3.1, R4.1, R8.1
unnamed: C15.1, R11.1, R12.2, R14.2
unnamed: C14.1, CT4.5, R15.1, R16.1, R17.1, R18.1
unnamed: C9.1, CT1.5, R1.1, R5.1, R6.1, R7.1
unnamed: LED1.A, R10.1
RESET: C2.1, ISP1.5, R32.1, S1.2 (S), U1_TQFP.29 (PC6(/RESET))

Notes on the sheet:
AC-AC 9V measurement
OpenEnergyMonitor.org
Glyn Hudson - March 2015
CT 4 4kW Max @ 240V with YHDC SCT-013-00 CT
CT 1-3 23kW Max @ 240V with YHDC SCT-013-00 CT
for battery 6V max
for AC-DC circuit 20mA max
Power
ATmega328
CT Current Sensors
Temperature & AC Voltage Sensors
Design is provided "AS IS" and "WITH ALL FAULTS. OpenEnergyMonitor DISCLAIMS ALL OTHER WARRANTIES, EXPRESS OR IMPLIED,
Hardware design files are licensed under the Creative Commons Attribution-ShareAlike 3.0 Unported License
emonTx V3.4.2
D19 / ADC 5 DS18B20 PWR
D5 - one-wire data
D3 - IRQ1 PQM
ATMEGA328
RFM12B RFM1269CW
One-Wire RJ45
D3 - IRQ1 PWM
ADC6 / Dig20
DIP Switch
Battery Power Monitor
ESP UART
emonTx UART

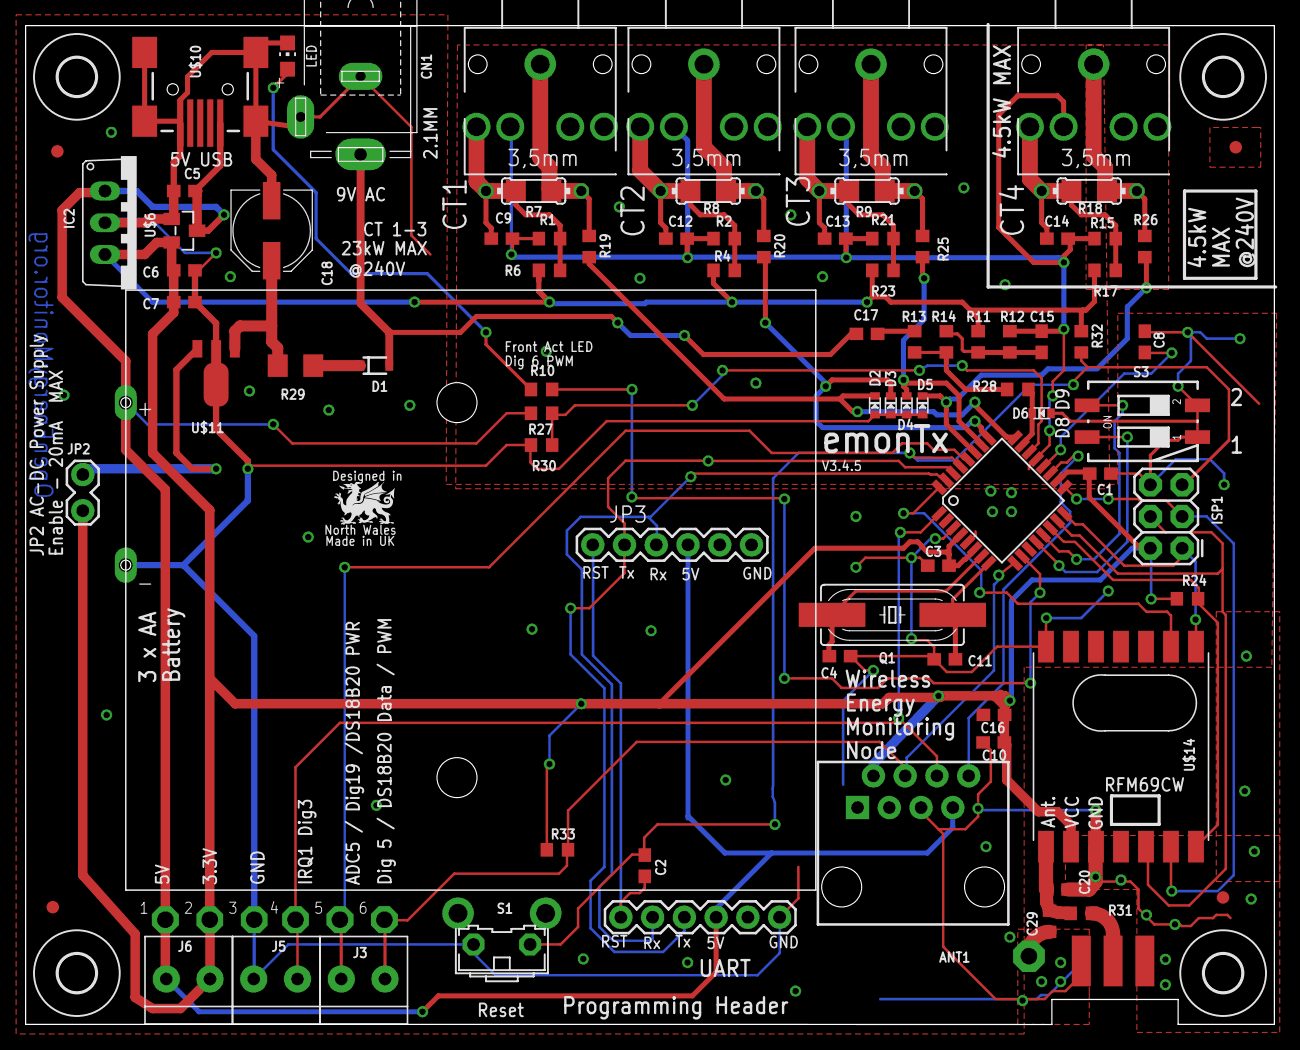
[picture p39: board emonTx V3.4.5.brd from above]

Board: 2 copper layers, 99.9 x 79.9 mm, 100 parts (1 on the bottom side), 48 nets.

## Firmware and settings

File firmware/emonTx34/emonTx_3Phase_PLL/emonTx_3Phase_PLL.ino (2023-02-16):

/*  Energy monitor for 3-phase 3-wire or 4-wire installation

    Based on a single phase energy diverter by Martin Roberts 2/12/12, which itself was
    based on emonTx hardware from OpenEnergyMonitor http://openenergymonitor.org/emon/
    this version implements a phase-locked loop to synchronise to the mains supply and
    supports a single Dallas DS18B20 temperature sensor.
    
    Temp fault codes: 300 deg = Sensor has never been detected since power-up/reset. 
                      302 deg = Sensor returned an out-of-range value. 
                      304 deg = Faulty sensor, sensor broken or disconnected.
                      85  deg   although in range, might indicate a wiring fault.

    Three-phase energy monitor
*/

#define VERSION "emonTx_3Phase_PLL - Firmware version 2.1.0 "                      
    
/*
    History (single Phase energy diverter):
    2/12/12  first published version
    3/12/12  diverted power calculation & transmission added
    4/12/12  manual power input added for testing
    10/12/12 high & low energy thresholds added to reduce flicker
    12/10/13 PB added 3rd CT channel to determine diverted power
    09/09/14 EmonTx v3 option added by PB ( http://openenergymonitor.org/emon/node/5714 )
    
    Three-phase energy monitor using "classic JeeLib"
    V 1.0    10/12/17 The original extensively modified with diverter code removed
                     and extended for 3-phase operation. 
    V 1.1    20/02/18 Sleep (sleep_mode()) removed from rfm_sleep() in rfm.ino
    V 1.2    12/03/18 Temperature fault codes were
                      300 deg = Faulty sensor, sensor broken or disconnected.
                      301 deg = Sensor has never been detected since power-up/reset. 
                      302 deg = Sensor returned an out-of-range value. 
    V 1.3    25/09/18 Declaration of showString() added - omission thereof caused 
                      compiler error in Arduino IDE V1.8.7
    V 1.4    22/10/18 Added 3-wire options & switch for 4-wire / 3-wire operation, 
                      free choice of phase for all four c.t's. 
    V 1.5            Documentation change only
    V 1.6    24/2/19  Unwanted space in emonESP output removed. No change to documentation.
    V 1.7            Versions 1.5 & 1.6 showed "V1.4" in serial print. Order of lines 457 & 458 was reversed. Added preprocessor substitution VERSION to replace a variable. 

    V 2.0.0  11/07/21  Derived from the "Classic JeeLib" version. Uses either Jeelib "Classic" or "RFM69 Native" format and OEM "rfm69nTxLib.h" library instead of rfm.ino file.
    V 2.1.0  16/02/23  Support for LowPowerLabs radio format


    emonhub.conf node decoder settings for this sketch:

    [[11]]
        nodename = emonTx_three_phase
        firmware = three_phase
        hardware = emonTx V3.2/V3.4/Shield
    [[[rx]]]
        names = power1, power2, power3, power4, Vrms, temp1, temp2, temp3, temp4, temp5, temp6, pulsecount
        datacodes = h, h, h, h, h, h, h, h, h, h, h, L
        scales = 1,1,1,1,0.01,0.01,0.01,0.01,0.01,0.01,0.01,1
        units =W,W,W,W,V,C,C,C,C,C,C,p
    
    IMPORTANT NOTE:
    When used in the 3-wire configuration with one line conductor being treated as the 'neutral', the
    individual powers recorded for the other two line conductors are meaningless, only the TOTAL power
    of the line conductors has a physical meaning. Therefore, 'power1' is the COMBINED power of inputs 1 & 2
    and all the values for input 2 alone are set to zero.
    Note also: Only one temperature sensor may be connected. All remaining temperatures will read "300.00"

    For serial input, emonHub requires "datacode = 0" in place of "datacodes = ...." as above.
    
    This sketch requires the OEM RFM69CW transmit-only library "rfm69nTxLib.h" and uses the "JeeLib RFM69 Native" message format.
*/

#define RFM69_JEELIB_CLASSIC 1
#define RFM69_JEELIB_NATIVE 2
#define RFM69_LOW_POWER_LABS 3

#define RadioFormat RFM69_LOW_POWER_LABS

#define EMONTX_V34                               // Sets the I/O pin allocation. 
                                                 // use EMONTX_V2 or EMONTX_V32 or EMONTX_V34 or EMONTX_SHIELD as appropriate
                                                 // NOTE: You must still set the correct calibration coefficients

//--------------------------------------------------------------------------------------------------
// #define DEBUGGING                             // enable this line to include debugging print statements
                                                 //  This is turned off when SERIALOUT or EMONESP (see below) is defined.
                                                 
#define SERIALPRINT                              // include 'human-friendly' print statement for commissioning - comment this line to exclude.

// Pulse counting settings
#define USEPULSECOUNT                            // include the ability to count pulses. Comment this line if pulse counting is not required. When enabled, pulse counting can still be turned on and off in the on-line settings.
#define PULSEINT 1                               // Interrupt no. for pulse counting: EmonTx V2 = 0, EmonTx V3 = 1, EmonTx Shield - see Wiki
#define PULSEPIN 3                               // Interrupt input pin: EmonTx V2 = 2, EmonTx V3 = 3, EmonTx Shield - see Wiki
#define PULSEMINPERIOD 100                       // minimum period between pulses (ms) - default pulse output meters = 100ms
                                                 //   Set to 0 for electronic sensor with solid-state output.
                                                 
// Output settings                               // THIS SKETCH WILL NOT WORK WITH THE RFM12B radio.
#define RFM69CW                                  // The type of output: Radio Module, serial or none.
                                                 // Can be RFM69CW 
                                                 //   or SERIALOUT if a wired serial connection is used (space-separated values for the
                                                 //     "direct serial" EmonHubSerialInterfacer
                                                 //     (see https://github.com/openenergymonitor/emonhub/tree/emon-pi/conf/
                                                 //        interfacer_examples/directserial) 
                                                 //   or EMONESP if an ESP WiFi module is used 
                                                 //     (see https://github.com/openenergymonitor/emonTxFirmware/blob/master/emonTxV3/
                                                 //       noRF/emonTxV3_DirectSerial/emonTxV3_DirectSerial.ino)
                                                 //       (key:value pairs for the EmonHubTx3eInterfacer)
                                                 //   or don't define anything if neither radio nor serial connection is required - in which case 
                                                 //      the IDE serial monitor output will be for information and debugging only.
                                                 // The sketch will hang if the wrong radio module is specified, or if one is specified and not fitted.
                                                 // For all serial output, the maximum is 9600 baud. The emonESP module must be set to suit.
                                            
#if RadioFormat == RFM69_LOW_POWER_LABS
  #include <RFM69.h>                             // RFM69 LowPowerLabs radio library
#elif RadioFormat == RFM69_JEELIB_CLASSIC
  #include <rfmTxLib.h>                          // RFM69 transmit-only library using "JeeLib RFM69 Native" message format
#elif RadioFormat == RFM69_JEELIB_NATIVE
  #include <rfm69nTxLib.h>                       // RFM69 transmit-only library using "JeeLib RFM69 Native" message format
#endif
  
const int busyThreshold = -97;                   // Signal level below which the radio channel is clear to transmit
const byte busyTimeout = 15;                     // Time in ms to wait for the channel to become clear, before transmitting anyway

typedef uint8_t DeviceAddress[8];


//-------------------- emonTx Settings - Stored in EEPROM and shared with config.ino ---------------
//-------------------- Constants which must be set individually for each system --------------------
#include <emonEProm.h>                           // OEM EEPROM library

struct {
  byte RF_freq = RF69_433MHZ;                     // Frequency of radio module can be RFM_433MHZ, RFM_868MHZ or RFM_915MHZ. 
  byte networkGroup = 210;                       // wireless network group - needs to be same as emonBase and emonGLCD. OEM default is 210
  byte rf_on = 1;                                // RF - 0 = no RF, 1 = RF on.
  byte nodeID = 11;                              // node ID for this emonTx. Or nodeID-1 if DIP switch 1 is ON. 
  byte  rfPower = 25;                            // 7 = -10.5 dBm, 25 = +7 dBm for RFM12B; 0 = -18 dBm, 31 = +13 dBm for RFM69CW. Default = 25 (+7 dBm)
  double vCal  = 268.97;                         // (240V x 13) / 11.6V = 268.97 Calibration for UK AC-AC adapter 77DB-06-09, 
                                                 //   for the EU adapter use 260.00, for the USA adapter use 130.00
  double i1Cal = 90.91;                          // (100 A / 50 mA / 22 Ohm burden) = 90.91 or 60.6 for emonTx Shield
  double i1Lead = 2.00;                          // 2° phase lead
  double i2Cal = 90.91;
  double i2Lead = 2.00;
  double i3Cal = 90.91;
  double i3Lead = 2.00;
  double i4Cal = 16.67;                          // (100 A / 50 mA / 120 Ohm burden) = 16.67
  double i4Lead = 0.20;                          // 0.2° phase lead
  float period = 9.85;                           // datalogging period - should be fractionally less than the PHPFINA database period in emonCMS
 
  bool  pulse_enable = true;                     // pulse counting
  int   pulse_period = 110;                      // pulse min period - 0 = no de-bounce
  bool  temp_enable = true;                      // enable temperature measurement
  DeviceAddress allAddresses[6];                 // sensor address data
  bool  showCurrents = false;                    // Print to serial voltage, current & p.f. values  

} EEProm;
  
uint16_t eepromSig = 0x0016;                     // oemEProm signature - see oemEProm Library documentation for details.
 
#define VCAL_EU 260.0                            // can use DIP switch 2 to set this as the starting value.                     


//--------------------------------------------------------------------------------------------------


#define WIRES 4-WIRE      // either 4-WIRE (default, measure voltage L1 - N) or 3-WIRE (no neutral, measure voltage L1 - L2)

#define CT1Phase PHASE1   // either PHASE1, PHASE2 or PHASE3 to attach c.t.1 to a phase. This c.t. MUST be used.
#define CT2Phase PHASE2   // similarly to attach c.t.2 to a phase. This c.t. MUST be used.
#define CT3Phase PHASE3   // similarly to attach c.t.3 to a phase. This c.t. MUST be used, do not comment this line.
#define CT4Phase PHASE1   // similarly to attach c.t.4 to a phase or comment this line if c.t.4 is not used 
                          //   (See also NUMSAMPLES below)
#define LEDISLOCK         // comment this out for LED pulsed during transmission
                          //  otherwise LED shows loop is locked, and occults to show transmission, but that is not easily visible

                          
//--------------------------------------------------------------------------------------------------
// other system constants
#define SUPPLY_VOLTS 3.3  // used here because it's more accurate than the internal band-gap reference. Use 5.0 for Arduino / emonTx Shield
#define SUPPLY_FREQUENCY 50
#define NUMSAMPLES 36     // number of times to sample each 50/60Hz cycle - for a 4-wire system, this must be a multiple of 3;
                          //   for a 3-wire system, it must be a multiple of 6
                          // Permissible maximum values (serial only) 50 Hz, 3 c.t: 45         60 Hz, 3 c.t: 36
                          //                                          50 Hz, 4 c.t: 36         60 Hz, 4 c.t: 33
#define ADC_BITS 10       // ADC Resolution
#define ADC_RATE 64       // Time between successive ADC conversions in microseconds

#define PLLTIMERRANGE 100 // PLL timer range limit ~ +/-0.5Hz
#define PLLLOCKRANGE 40   // allowable ADC range to enter locked state
#define PLLUNLOCKRANGE 80 // allowable ADC range to remain locked
#define PLLLOCKCOUNT 100  // number of cycles to determine if PLL is locked

//--------------------------------------------------------------------------------------------------
//
//   Users should not need to change anything below here
//
//
//--------------------------------------------------------------------------------------------------

//--------------------------------------------------------------------------------------------------
// I/O pins for debugging
// Define these only for testing. On the emonTx V3.x, it may be necessary to comment out and
//  remove external connections to the interrupt pin, the One-wire or DS18B20 power pins.
//#define SYNCPIN 19  // this output will be a 50Hz square wave locked to the 50Hz input
//#define SAMPPIN 19  // this output goes high each time an ADC conversion starts or completes
//#define TXPIN 3     // this output goes high each time a radio transmission takes place
//--------------------------------------------------------------------------------------------------

// Arduino I/O pin usage
#if defined(EMONTX_V2)
// EmonTx v2 Pin references
#undef CT4Phase
#define VOLTSPIN 2
#define CT1PIN 3
#define CT2PIN 0
#define CT3PIN 1
#define LEDPIN 9
#define RFMSELPIN 10
#define RFMIRQPIN 2
#define SDOPIN 12
#define W1PIN 4         // 1-Wire pin for temperature

#elif defined(EMONTX_V32)
// EmonTx v3.2 Pin references
#define VOLTSPIN 0
#define CT1PIN 1
#define CT2PIN 2
#define CT3PIN 3
#define CT4PIN 4
#define LEDPIN 6
#define RFMSELPIN 4     // Pins for the RFM Radio module
#define RFMIRQPIN 3
#define SDOPIN 12
#define W1PIN 5         // 1-Wire pin for temperature
#define DS18B20_PWR 19  // Power for 1-wire temperature sensor

#elif defined EMONTX_SHIELD
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
void loop()
{
  getSettings();

  
  if(newsumCycle && !firstCycle)
    addsumCycle(); // a new mains sumCycle has been sampled
  firstCycle = false;
  
  if((millis()>=nextTransmitTime) && ((millis()-nextTransmitTime)<0x80000000L)) // check for overflow
  {
    #ifndef LEDISLOCK
      digitalWrite(LEDPIN,HIGH);
    #else
      digitalWrite(LEDPIN,LOW);
    #endif
    calculateVIPF();

    if (hasTemperatureSensor && EEProm.temp_enable)
        emontx.temp[0]=readTemperature();
    
    if (pulses)                                      // if the ISR has counted some pulses, update the total count
    {
        cli();                                       // Disable interrupt just in case a pulse comes in while we are updating the count
        emontx.pulseCount += pulses;
        pulses = 0;
        sei();                                       // Re-enable interrupts
    }

    sendResults();
    if (EEProm.temp_enable)
      convertTemperature(); // start next conversion
    nextTransmitTime+=EEProm.period*1000;
    #ifndef LEDISLOCK
      digitalWrite(LEDPIN,LOW);
    #else
      digitalWrite(LEDPIN,HIGH);
    #endif
  }
}

// timer 1 interrupt handler
ISR(TIMER1_COMPA_vect)
{
  #ifdef SAMPPIN
  digitalWrite(SAMPPIN,HIGH);
  #endif
  ADMUX = _BV(REFS0) | CT1PIN; // start ADC conversion for first current
  ADCSRA |= _BV(ADSC);
  #ifdef SAMPPIN
  digitalWrite(SAMPPIN,LOW);
  #endif
}

// ADC interrupt handler
ISR(ADC_vect)
{
  static int newV, lastV, sampleI1, sampleI2, sampleI3, sampleI4;
  static int storedV[BUFFERSIZE];  // Array to store >240 degrees of voltage samples
  int result;
  static int Vindex = 0;
  
  #ifdef SAMPPIN
  digitalWrite(SAMPPIN,HIGH);
  #endif
  result = ADCL;
  result |= ADCH<<8;
  // remove the nominal offset 
  result -=(ADC_COUNTS >> 1);
  // determine which conversion just completed
  switch(ADMUX & 0x0f)
  {
    case CT1PIN:
      ADMUX = _BV(REFS0) | CT2PIN; // start CT2 conversion
      ADCSRA |= _BV(ADSC);
      sampleI1 = result;
      sumI1sq += (long)sampleI1 * sampleI1;
      sumI1avg += sampleI1;
      break;
    case CT2PIN:
      ADMUX = _BV(REFS0) | CT3PIN; // start CT3 conversion
      ADCSRA |= _BV(ADSC);
      sampleI2 = result;
      sumI2sq += (long)sampleI2 * sampleI2;
      sumI2avg += sampleI2; 
     break;
    case CT3PIN:
    #ifdef CT4Phase
      ADMUX = _BV(REFS0) | CT4PIN; // start CT4 conversion
    #else
      ADMUX = _BV(REFS0) | VOLTSPIN; // start Voltage conversion        
    #endif
      ADCSRA |= _BV(ADSC);
      sampleI3 = result;
      sumI3sq += (long)sampleI3 * sampleI3;
      sumI3avg += sampleI3; 
      break;
    #ifdef CT4Phase
    case CT4PIN:
      ADMUX = _BV(REFS0) | VOLTSPIN; // start Voltage conversion
      ADCSRA |= _BV(ADSC);
      sampleI4 = result;
      sumI4sq += (long)sampleI4 * sampleI4;
      sumI4avg += sampleI4; 
      break;
    #endif
    case VOLTSPIN:
      lastV=newV;
      newV = result;
      storedV[Vindex] = newV;        // store this voltage sample in circular buffer
      sumVsq += ((long)newV * newV);
      sumVavg += newV; 

      sumPower1A += (long)storedV[(Vindex+BUFFERSIZE-CT1Phase)%BUFFERSIZE] * sampleI1;  // Use stored & delayed voltage for power calculation CT 1
      sumPower1B += (long)storedV[(Vindex+BUFFERSIZE-CT1Phase-1)%BUFFERSIZE] * sampleI1;

      sumPower2A += (long)storedV[(Vindex+BUFFERSIZE-CT2Phase)%BUFFERSIZE] * sampleI2;  // Use stored & delayed voltage for power calculation CT 2
      sumPower2B += (long)storedV[(Vindex+BUFFERSIZE-CT2Phase-1)%BUFFERSIZE] * sampleI2;

      sumPower3A += (long)storedV[(Vindex+BUFFERSIZE-CT3Phase)%BUFFERSIZE] * sampleI3;  // Use stored & delayed voltage for power calculation CT 3
      sumPower3B += (long)storedV[(Vindex+BUFFERSIZE-CT3Phase-1)%BUFFERSIZE] * sampleI3;

#ifdef CT4Phase
      sumPower4A += (long)storedV[(Vindex+BUFFERSIZE-CT4Phase)%BUFFERSIZE] * sampleI4;  // Use stored & delayed voltage for power calculation CT 4
      sumPower4B += (long)storedV[(Vindex+BUFFERSIZE-CT4Phase-1)%BUFFERSIZE] * sampleI4;
#endif      
      sumSamples++;
      updatePLL(newV,lastV);
      ++Vindex %= BUFFERSIZE;    
      break;
      
  }
  #ifdef SAMPPIN
  digitalWrite(SAMPPIN,LOW);
  #endif

}

void updatePLL(int newV, int lastV)
{
  static byte samples=0;
  static int oldV;
  bool rising;

  rising=(newV>lastV); // synchronise to rising zero crossing
  
  samples++;
  if(samples>=NUMSAMPLES) // end of one 50Hz sumCycle
  {
    #ifdef SYNCPIN
    digitalWrite(SYNCPIN,HIGH);
    #endif
    samples=0;
    if(rising)
    {
      // if we're in the rising part of the 50Hz sumCycle adjust the final timer count
      // to move newV towards 0, only adjust if we're moving in the wrong direction
      if(((newV<0)&&(newV<=oldV))||((newV>0)&&(newV>=oldV))) timerCount-=newV;
      // limit range of PLL frequency
      timerCount=constrain(timerCount,PLLTIMERMIN,PLLTIMERMAX);
      OCR1A=timerCount;
      if(abs(newV)>PLLUNLOCKRANGE) pllUnlocked=PLLLOCKCOUNT; // we're unlocked
      else if(pllUnlocked) pllUnlocked--;
      #ifdef LEDISLOCK
        digitalWrite(LEDPIN,pllUnlocked?LOW:HIGH);
      #endif
    }
    else // in the falling part of the sumCycle, we shouldn't be here
    {
      OCR1A=PLLTIMERMAX; // shift out of this region fast
      pllUnlocked=PLLLOCKCOUNT; // and we can't be locked
    }
    
    oldV=newV;
    
    newsumCycle=true; // flag new sumCycle to outer loop
  }
  else if(samples==(NUMSAMPLES/2))
  {
    // negative zero crossing
    #ifdef SYNCPIN
    digitalWrite(SYNCPIN,LOW);
    #endif
  }
  #ifdef SAMPPIN
  digitalWrite(SAMPPIN,LOW);
  #endif
}

// add data for new 50Hz sumCycle to total for the period (called from loop() )
void addsumCycle()
{
  // save results for outer loop
  noInterrupts();
  sumPeriodVsq      += sumVsq;
  sumPeriodVavg     += sumVavg;
  sumPeriodI1sq     += sumI1sq;
  sumPeriodI1avg    += sumI1avg; 
  sumPeriodI2sq     += sumI2sq;
  sumPeriodI2avg    += sumI2avg; 
  sumPeriodI3sq     += sumI3sq;
  sumPeriodI3avg    += sumI3avg; 
  sumPeriodI4sq     += sumI4sq;
  sumPeriodI4avg    += sumI4avg; 

  sumPeriodPower1A  += sumPower1A;
  sumPeriodPower1B  += sumPower1B;
  sumPeriodPower2A  += sumPower2A;
  sumPeriodPower2B  += sumPower2B;
  sumPeriodPower3A  += sumPower3A;
  sumPeriodPower3B  += sumPower3B;
  sumPeriodPower4A  += sumPower4A;
  sumPeriodPower4B  += sumPower4B;
  sumPeriodSamples  += sumSamples;

  sumVsq	    = 0;
  sumVavg	    = 0;
  sumI1sq	    = 0;
  sumI1avg	    = 0; 
  sumI2sq	    = 0;
  sumI2avg	    = 0; 
  sumI3sq	    = 0;
  sumI3avg	    = 0; 
  sumI4sq       = 0;
  sumI4avg	    = 0; 
      
  sumPower1A	= 0;
  sumPower1B	= 0;
  sumPower2A	= 0;
  sumPower2B	= 0;
  sumPower3A	= 0;
  sumPower3B	= 0;
  sumPower4A	= 0;
  sumPower4B	= 0;
  sumSamples	= 0;

  sumTimerCount+=(timerCount+1); // for average frequency calculation
  sumCycleCount++;
  newsumCycle=false;
  interrupts();
}


double removeRMSOffset(uint64_t sumSquared, int64_t sum, unsigned long numSamples)
{
    double x = ((double)sumSquared / numSamples) - ((double)sum * sum / numSamples / numSamples);
    return (x<0.0 ? 0.0 : sqrt(x));
}

double removePowerOffset(int64_t power, int64_t sumV, int64_t sumI, unsigned long numSamples)
{
    return (((double)power / numSamples) - ((double)sumV * sumI / numSamples / numSamples));
}

double deg_rad(double a)
{
    return (0.01745329*a);
}

double applyPhaseShift(double phaseShift, double sampleRate, double A, double B)
{
  double y = sin(deg_rad(phaseShift)) / sin(deg_rad(sampleRate));
  double x = cos(deg_rad(phaseShift)) - y * cos(deg_rad(sampleRate));
  return (A * x + B * y); 
}
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

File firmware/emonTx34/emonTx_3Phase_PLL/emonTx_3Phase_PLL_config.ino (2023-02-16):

/*
Configuration functions for EmonTxV34CM_rfm69n.ino

EEPROM layout

Byte
0     NodeID
1     RF Freq
2     rF Power
3     Network Group
4-7   vCal
8-11  i1Cal
12-15 i1Lead
16-19 i2Cal
20-23 i2Lead
24-27 i3Cal
28-31 i3Lead
32-35 i4Cal
36-39 i4Lead
40    temperature enable
41-88 temperature addresses
*/


#include <Arduino.h>
#include <avr/pgmspace.h>
#include <EEPROM.h>
#include <emonEProm.h>

 // Available Serial Commands
const PROGMEM char helpText1[] =                                
"\n"
"Available commands:\n"
"l\t\t- list the settings\n"
"r\t\t- restore sketch defaults\n"
"s\t\t- save settings to EEPROM\n"
"v\t\t- show firmware version\n"
"z\t\t- zero energy values\n"
"x\t\t- exit, lock and continue\n"
"?\t\t- show this text again\n"
"\n"
"w<x>\t\t- turn RFM Wireless data off: x = 0 or on: x = 1\n"
"b<n>\t\t- set r.f. band n = a single numeral: 4 = 433MHz, 8 = 868MHz, 9 = 915MHz (may require hardware change)\n"
"p<nn>\t\t- set the r.f. power. nn - an integer 0 - 31 representing -18 dBm to +13 dBm. Default: 25 (+7 dBm)\n"
"g<nnn>\t\t- set Network Group  nnn - an integer (OEM default = 210)\n"
"n<nn>\t\t- set node ID n= an integer (standard node ids are 1..60)\n"
"\n"
"d<xx.x>\t\t- xx.x = a floating point number for the datalogging period\n" 
"c<n>\t\t- n = 0 for OFF, n = 1 for ON, enable voltage, current & power factor values to serial output for calibration. \n"
"k<x> <yy.y> <zz.z>\n"
"\t\t- Calibrate an analogue input channel:\n"
"\t\t  x = a single numeral: 0 = voltage calibration, 1 = ct1 calibration, 2 = ct2 calibration, etc\n"
"\t\t  yy.y = a floating point number for the voltage/current calibration constant\n"
"\t\t  zz.z = a floating point number for the phase calibration for this c.t. (z is not needed, or ignored if supplied, when x = 0)\n"
"\t\t  e.g. k0 256.8\n"
"\t\t       k1 90.9 2.00\n"
"m<x> <yy>\t- meter pulse counting:\n"
"\t\t   x = 0 for OFF, x = 1 for ON, <yy> = an integer for the pulse minimum period in ms. (y is not needed, or ignored when x = 0)\n"
"t0 <y>\t\t- turn temperature measurement on or off: y = 0 for OFF, y = 1 for ON\n"
"t<x> <yy> <yy> <yy> <yy> <yy> <yy> <yy> <yy>\n"
"\t\t- change a temperature sensor's address or position:\n"
"\t\t  x = a single numeral: the position of the sensor in the list (1-based)\n"
"\t\t  yy = 8 hexadecimal bytes representing the sensor's address\n"
"\t\t    e.g.  28 81 43 31 07 00 00 D9\n"
"\t\t  N.B. Sensors CANNOT be added.\n"
;

extern DeviceAddress *temperatureSensors;

static void load_config(bool verbose)
{
  bool success = eepromRead(eepromSig, (byte *)&EEProm);
  if (verbose)
  {
    if (success)
      Serial.println(F("Loaded EEPROM config"));
    else
      Serial.println(F("No EEPROM config"));
    list_calibration();
  }
}

static void list_calibration(void)
{
  Serial.println(F("Settings:"));
  Serial.print(F("Band ")); 
  Serial.print(EEProm.RF_freq == RF69_433MHZ ? 433 : 
               EEProm.RF_freq == RF69_868MHZ ? 868 :
               EEProm.RF_freq == RF69_915MHZ ? 915 : 0);
  Serial.print(F(" MHz, Group ")); Serial.print(EEProm.networkGroup);
  Serial.print(F(", Node ")); Serial.print(EEProm.nodeID & 0x3F);
  Serial.print(F(", "));Serial.print(EEProm.rfPower - 18);Serial.println(F(" dBm"));
  Serial.println(F("Calibration:"));
  Serial.print(F("vCal = ")); Serial.println(EEProm.vCal);
  Serial.print(F("i1Cal = ")); Serial.println(EEProm.i1Cal);
  Serial.print(F("i1Lead = ")); Serial.println(EEProm.i1Lead);
  Serial.print(F("i2Cal = ")); Serial.println(EEProm.i2Cal);
  Serial.print(F("i2Lead = ")); Serial.println(EEProm.i2Lead);
  Serial.print(F("i3Cal = ")); Serial.println(EEProm.i3Cal);
  Serial.print(F("i3Lead = ")); Serial.println(EEProm.i3Lead);
  Serial.print(F("i4Cal = ")); Serial.println(EEProm.i4Cal);
  Serial.print(F("i4Lead = ")); Serial.println(EEProm.i4Lead);
  Serial.print(F("datalog = ")); Serial.println(EEProm.period);
  Serial.println(EEProm.rf_on ? F("RF on"):F("RF off"));
  Serial.print(F("temp_enable = ")); Serial.println(EEProm.temp_enable);
}

static void save_config()
{
  Serial.println(F("Saving..."));
  eepromWrite(eepromSig, (byte *)&EEProm, sizeof(EEProm));
  eepromPrint();
  Serial.println();
  Serial.println(F("Done. New config saved to EEPROM"));
}

static void wipe_eeprom(void)
{
  Serial.println(F("Resetting..."));
  
  eepromHide(eepromSig);   
  Serial.println(F("Sketch will now restart using default config."));
  delay(200);
}

void softReset(void)
{
  asm volatile ("  jmp 0");
}


int getPass(void)
{
/*
 * Get and verify the user's access code (replaces 'readString()' saves 1300 bytes)
 */

  char buf[5];
  if (Serial.readBytes(buf, 5) != 5)
    return 0;
  // Verbose
  if  (buf[0] == '+' 
    && buf[1] == '+'
    && buf[3] == '\r'
    && buf[4] == '\n')
  {
    if (buf[2] == '+')      // Verbose
    {
      calibration_enable = true;
      return 2;
    }
    else if (buf[2] == 's') //Silent
    {
      calibration_enable = true;
      return 1;
    }
  }
  return 0;
}
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

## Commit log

2017-01-22 move emonTx V3.4 hardware & firmware to single repo
    [20170122_emontx_v3_4_3.csv, emonTx V3.4.1.brd, emonTx V3.4.1.sch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]
2017-01-22 add gerber and enclosure data
    [fascia.brd, fascia.dxf]
2017-02-15 Fix node ID assignment comments
    https://wiki.openenergymonitor.org/index.php/EmonTx_V3.4#DIP_Switch_Config
    [src.ino]
2017-02-24 fix USA apparent power readings
    [src.ino]
2017-02-24 fix incorrect serial print of nodeID if set via serial EEPROM and DIP switch
    [src.ino]
2017-02-27 v2.8 Correct USA voltage to 120V
    [src.ino]
2017-03-30 correct RMS voltage calc at startup when USA mode is enabled
    [src.ino]
2017-06-13 fix space in serial node ID config help text
    [src.ino]
2017-06-21 Update src.ino
    spelling / grammar corrections
    [src.ino]
2017-09-05 update board and schematic images to latest V3.4.2
    [emonTx V3.4.2.sch]
2017-09-05 add description to BOM
    [20170122_emontx_v3_4_3.csv, 20170905_emontx_v3_4_3.xlsx]
2017-09-08 add V2.3.2 HW design
    [emonTx V3.4.3.brd, emonTx V3.4.3.sch]
2017-09-25 add missing v3.4.3 files
    [emonTx V3.4.4.brd, emonTx V3.4.4.sch]
2018-03-22 fix PCB revisions
2018-03-22 extract v3.4.4 gerbers
    [emonTx V3.4.3.GBL, emonTx V3.4.3.GBO, emonTx V3.4.3.GBS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]
2018-03-22 fix bool compile issue
    [src.ino]
2019-10-02 Fix two possible underflows that can generate long delays in loop
    In case the runtime calculated at the end of the loop is greater
    than 9900 ms, the calculated sleeptime underflows. Being it an
    unsigned long, the resulting value would be about 2^32
    milliseconds (about 50 days). This value is used as parameter
    in a delay() function to wait for the next acqusition cycle, if
    AC-AC adapter is used.
    Even in case of battery powered system, the time calculated
    inside the Sleepy::loseSomeTime() function could underflow if
    sleeptime is smaller than 500 ms. Being the parameter a word,
    the resulting value would be about 2^16 (about 65 seconds).
    This patch avoids both the underflows.
    In case of underfl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
    [src.ino]
2019-12-05 fix factory RFM test sequence V3.3.0
    [src.ino]
2020-08-06 Update src.ino
    Looks like showstring declaration is missing from main src.ino
    [src.ino]
2021-01-05 increase time for temp conversion, required for new batch of RJ45 sensors
2021-04-07 V3.4.5 hardware, very mintor tweaks for manufacturability
    [emonTx V3.4.5.brd, emonTx V3.4.5.sch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]
2021-04-07 update board image
2021-04-07 add note about CT socket colour
2022-03-10 TSV diode change
2022-12-29 burden resistor calculations
2023-02-16 update emontx3.2 CM firmware
2023-02-16 emontx3.2 cm firmware
2023-02-16 disable factory test for low power labs
2023-08-31 Add board files.
    [emonTx V3.2.brd, emonTx V3.2.sch]
2023-09-01 Fix newline handling. Now the code doesn't care if you send \r, \r\n, \n, \n\r
    [emonTx34_CM_config.ino]
2023-09-03 fix warning and potential crash from array out of bounds error
    [emonTx34_CM_config.ino]
2023-09-08 Revert "I'm using JEELIB_CLASSIC it would seem"
    This reverts commit 1710b2c68b60b56d9baa6593dfd9aa2490a91ed3.
    [emonTx34_CM.ino]

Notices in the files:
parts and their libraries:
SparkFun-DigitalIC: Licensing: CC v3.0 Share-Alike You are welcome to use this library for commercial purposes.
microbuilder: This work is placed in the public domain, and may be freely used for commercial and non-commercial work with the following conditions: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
